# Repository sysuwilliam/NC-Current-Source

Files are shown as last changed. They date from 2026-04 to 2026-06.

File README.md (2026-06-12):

<div align="center">

# 高精度数控恒流源

<p>
  
  
  
  
  
</p>

系统基于 <code>STM32F103 + DAC8562 + OPA197 + 可调 Buck</code>，实现高精度恒流输出、参数显示与保护控制。

</div>

## 项目简介

本项目是 2026 年中山大学电子设计与程序设计校内赛电子设计赛道选题三“高精度数控恒流源”的完整实现。系统以 `STM32F103` 为主控，结合 `DAC8562`、`OPA197`、功率 MOS 管和可调 Buck 电源，完成稳定恒流输出、状态检测、人机交互与保护控制。

项目目标是在不同负载条件下输出高精度、可调节、可显示、可保护的直流恒流。仓库中保留了从方案规划、硬件设计、嵌入式固件、串口屏工程，到测试标定、外壳设计和参考资料的完整内容。

## 主要功能

- 可设定输出电流并稳定恒流输出
- 串口屏显示电流、电压、负载等信息
- 按键与编码器调节参数
- Buck 自动调节输出余量，降低 MOS 发热
- 支持过流、短路、开路保护

## 工作原理

系统采用“硬件恒流内环 + 软件余量外环”的结构：

- `DAC8562 + OPA197 + MOS + Rs` 构成硬件恒流环，直接建立目标电流并负责快速稳流
- `STM32` 采样 `Vsense`、`VOUT+`、`VOUT-`，计算输出电流、负载电压、负载状态和 MOS 压差余量
- `DAC8562` 的另一通道用于控制可调 Buck，动态调节输出电压，为恒流环提供合适工作余量
- 串口屏、按键和编码器负责人机交互，实现参数设置、状态显示和工作控制

控制链路如下：

```text
I_set -> DAC8562 -> OPA197 + MOS + Rs -> I_out
                -> STM32采样与计算 -> Buck调节
```

简要理解就是：

- 模拟电路负责“把电流稳住”
- MCU 负责“把状态算清楚”
- Buck 负责“把供电余量调合适”

## 仓库结构

```text
.
├── README.md                        项目说明
├── 赛题/                            校赛题目原文
├── 规划/                            初期规划、中期报告、收尾总结
├── 代码/
│   ├── 成品/                        最终主固件工程
│   ├── 成品2/                       成品阶段备份工程
│   └── 测试板/                      早期测试板固件工程
├── PCB/
│   └── 测试板/                      PCB 工程文件
├── 串口屏/
│   ├── UI.HMI                       串口屏工程
│   └── 资料/                        串口屏开发手册、例程与协作笔记
├── 测试/
│   ├── 恒流源测试/                  测试规划、测试记录、标定数据与分析图表
│   └── 恒压源测试/                  早期电源与 Buck 联调记录
├── 数据手册/                        DAC、Buck、LDO 等器件手册
├── 外壳/                            3D 外壳模型文件
├── 参考工程/                        参考项目、接口说明、BOM 等资料
└── github协作指南/                  团队协作与 Git 使用说明
```

## 项目状态

项目已完成。仓库当前保存了最终代码、测试数据、串口屏工程、PCB 文件、外壳模型和相关设计资料，可用于展示、复盘和后续迭代参考。

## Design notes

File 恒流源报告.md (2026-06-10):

# 高精度数控恒流源系统设计、控制分析与测试报告

| 项目 | 内容 |
| --- | --- |
| 队伍 | 做的都队 |
| 成员 | 待补充 |
| 比赛 | 2026 年中山大学电子设计与程序设计校内赛电子设计赛道，选题三 |
| 仓库链接 | <https://github.com/sysuwilliam/NC-Current-Source> |
| 提交版本 | `debca7a` |
| 报告状态 | 阶段性报告，最终测试数据和外壳资料待赛前补充 |

## 摘要

本项目设计并实现了一套高精度数控恒流源系统，目标是在可调负载条件下输出稳定、可设定、可显示并具备保护能力的直流恒流。系统采用 `STM32F103 + DAC8562 + OPA197 + MOS + 可调 Buck` 的总体结构，其中 DAC8562 的 CH2 输出电流参考，OPA197、低边 MOS 与 `2Ω` 采样电阻构成快速硬件恒流内环；STM32 采样 `Vsense`、`VOUT+` 和 `VOUT-`，计算输出电流、负载电压、负载电阻和 MOS 压差余量，并通过 DAC8562 的 CH1 慢速调节 Buck 输出，使恒流环保留足够余量且降低 MOS 发热。现有测试表明，电流主链路线性良好，去掉 `0mA` 点后 `I_set -> I_meas` 拟合 `R² = 0.99999900`，`500mA` 点误差约为 `-0.5%`。后续重点是补全 `VOUT±` 校准、负载电阻显示、Buck 自动慢环和三类保护的最终验证。

## 1. 系统设计

### 1.1 总体架构

系统以外部直流输入作为整机能源，分为功率输出、模拟恒流、数字控制和人机交互四个部分。当前仓库中的设计资料和固件均围绕“硬件恒流内环 + 软件 Buck 余量外环”展开。

```text
35V 输入
├── 可调 Buck：输出 VOUT+，给负载和低边 MOS 恒流功率级供电
└── 固定 Buck：输出 5V
    ├── 串口屏
    ├── OPA197 运放
    └── LDO：输出 3.3V
        ├── STM32F103
        ├── DAC8562
        ├── TS5A3159A 模拟开关
        └── ADC / 比较器相关小信号电路
```

控制链路为：

```text
用户设定 Iset
    -> STM32 计算 DAC2 目标电压
    -> DAC8562 CH2 输出电流参考
    -> OPA197 + MOS + Rs 构成硬件恒流环
    -> STM32 采样 Vsense / VOUT+ / VOUT-
    -> 计算 Iactual / Vload / Rload / VMOS
    -> DAC8562 CH1 慢速调节可调 Buck 输出 VOUT+
```

### 1.2 关键器件与作用

| 模块 | 器件/参数 | 作用 |
| --- | --- | --- |
| 主控 | STM32F103 | 采样、计算、按键与串口屏交互、保护状态管理 |
| DAC | DAC8562 | CH2 设定恒流参考，CH1 控制可调 Buck |
| 恒流运放 | OPA197 | 驱动 MOS，使采样电阻电压跟随 DAC2 参考 |
| 功率调整 | 低边 MOS | 线性调整输出电流，承担恒流功率级压差 |
| 电流采样 | `Rs = 2Ω` | 将输出电流转换为采样电压 |
| Buck | LMR16030 相关电路 | 将输入电压降为可调 `VOUT+` 和固定 5V |
| 交互 | 串口屏、按键、编码器 | 设置电流、显示状态、清除报警 |

恒流功率路径为：

```text
VOUT+ -> 负载 -> MOS -> Rs -> GND
```

该路径需要短而粗，MOS、采样电阻和 Buck 电感是主要发热器件。PCB 设计中应把 MOS Drain 大焊盘铺铜并多打过孔，外壳对应 MOS、Rs 和电感区域预留散热孔。

### 1.3 PCB 与可靠性设计

1. `Rs` 使用 Kelvin 采样：功率电流从采样电阻主焊盘流过，运放反馈和 ADC 采样从采样点单独引出，减少铜皮压降对电流精度的影响。
2. `GND` 与 `AGND` 单点连接：连接点放在 Rs 下端或 `AGND_STAR` 附近，避免 Buck、屏幕和数字回流流过模拟参考地。
3. Buck 与模拟区隔离：Buck 的 SW 节点、电感、二极管和输入输出电容远离 DAC、OPA、ADC 分压和 MOS Gate 信号。
4. `VOUT+ / VOUT-` 采样从真实负载端附近引出，用于计算负载电压、负载电阻、MOS 压差和保护状态。
5. 外壳作为加分项处理：正文只放最终装配图、散热孔设计和接口布置说明；完整三维源文件放仓库附录。

## 2. 控制分析

### 2.1 硬件恒流内环

硬件恒流内环由 `DAC2 -> OPA197 -> MOS -> Rs` 构成。DAC2 输出电压作为运放同相端参考，运放调节 MOS Gate，使采样电阻上的电压接近参考电压。理想关系为：

```text
Iout = Vref / Rs
Iout = DAC_ISET / 2Ω
```

该环路不依赖软件高速闭环，主要由运放和 MOS 的模拟响应决定，因此适合承担快速稳流任务。实测中 `DAC2_meas -> I_meas` 拟合为：

```text
I_meas_mA = 0.497253 * DAC2_mea_mV - 0.029041
R² = 0.99999994
RMSE = 0.041 mA
```

该结果说明只要 DAC2 实际输出电压确定，模拟恒流内环线性非常好。当前主误差更多来自 DAC 命令值、ADC 显示换算和 Buck 余量设置。

### 2.2 Buck 慢速余量外环

Buck 外环的目的不是直接高速调电流，而是给恒流内环提供合适压差，避免 MOS 压差过小导致恒流失败，也避免压差过大造成 MOS 发热。

核心计算量为：

```text
Vload = VOUT+ - VOUT-
Rload = Vload / Iout
VMOS = VOUT- - Vsense
VOUTP_target = I_set * Rload_est + I_set * Rsense + VMOS_margin
```

根据测试和分析，初版可取：

```text
Rsense = 2Ω
VMOS_margin = 1.2V ~ 2.0V
```

DAC1 与 Buck 输出的反算采用当前测试总结中的关系：

```text
VOUT+ = 10.012879 * DAC1_actual_V - 1.797554
DAC1_cmd_V = (VOUTP_target + 1.797554) / 10.012879
```

仓库早期测试记录中也出现过 `VOUT+ = 31.242 - 10.011 * V_DAC1` 的负斜率公式，二者对应的控制点或电路阶段可能不同。最终报告应以最后一晚实测的 `DAC1_cmd -> VOUT+` 标定为准，明确写出当时测量点、接法和公式符号。

同时必须加入限幅，避免 Buck 输出超过硬件和输入电源能力。当前 `VOUT± 校准 -> Rload 校准 -> Buck 自动调 DAC1` 仍属于最终待验证项，建议最后一晚按以下顺序补齐：

1. 用万用表标定 `VOUT+`、`VOUT-` 显示值。
2. 用校准后的 `Vload / Iout` 计算 `Rload_est`。
3. 固定 50mA、250mA、500mA 三档，改变负载，观察自动 Buck 是否能让 `VMOS` 保持在目标范围。
4. 记录 `DAC1_cmd`、`VOUT+`、`VOUT-`、`VMOS` 和 MOS 温升趋势。

### 2.3 显示、状态与交互层

STM32 负责把 ADC 采样值换算为显示量，并通过串口屏显示工作模式、设定电流、实际电流、负载电阻、DAC 输出和保护状态。按键与编码器负责：

1. 设定目标电流。
2. 开启或停止输出。
3. 在过流或开路故障后清除报警。

显示值不应直接作为保护判断的唯一依据。报告中区分：

| 名称 | 用途 |
| --- | --- |
| `I_serial` | ADC 原始换算电流 |
| `I_disp` | 校准和滤波后的用户显示电流 |
| `I_fast` | 短平均、低延迟的保护判断电流 |
| `Rload_disp` | 滤波和死区处理后的负载电阻显示值 |

## 3. 保护逻辑

保护逻辑分为过流、短路和开路三类。报告应如实记录每一类保护的状态：已实现、已验证、设计完成待验证。当前建议最终报告采用下表更新。

| 保护类型 | 判据 | 动作 | 恢复方式 | 当前状态 |
| --- | --- | --- | --- | --- |
| 过流保护 | `Vsense > 1.10V` 或 `I_fast > 550mA`，持续超过去抖时间 | `SW_IN=0`、`DAC2=0`、`BUCK_EN=0`，报警锁存 | 用户按 `ALARM CLEAR` 后回到待机 | 设计完成，待最终验证 |
| 短路保护 | `Iset` 非零、`Iactual` 接近设定值且 `Vload < 0.2V ~ 0.5V` 持续 50ms-200ms | 进入短路限流，降低 Buck 输出，显示“短路限流” | 短路解除后自动回到正常 Buck 调节 | 设计完成，待最终验证 |
| 开路保护 | `Iset > 20mA`、`Iactual < 5mA`，Buck 已升高仍无电流，持续约 200ms | `SW_IN=0`、`DAC2=0`、`BUCK_EN=0`，报警锁存 | 接好负载后人工清除报警 | 设计完成，待最终验证 |

过流和开路应锁存，防止故障解除瞬间自动重启造成反复冲击；短路保护以“限流不损坏”为目标，可以自动恢复。保护判断使用 `I_fast` 或短时间平均值，避免显示滤波过慢造成保护滞后。

## 4. 测试数据与结果

### 4.1 测试数据来源

当前阶段的量化分析主要来自：

1. `测试/恒流源测试/测试记录/测试数据02.xlsx`
2. `测试/恒流源测试/测试分析/测试数据02分析.md`
3. `测试/恒流源测试/figures/` 中生成的拟合、误差、稳定性和余量图

原始表格和完整图像不放入正文全文展开，作为仓库附录提供。

### 4.2 电流设定精度

综合校准表中，设定电流与电流表实测电流拟合为：

```text
I_meas_mA = 0.994172 * I_set_mA + 0.259333
R² = 0.99999586
RMSE = 0.340 mA
最大拟合残差 = 1.071 mA
```

去掉 `0mA` 点后：

```text
I_meas_mA = 0.994738 * I_set_mA + 0.067706
R² = 0.99999900
RMSE = 0.165 mA
最大拟合残差 = 0.345 mA
```

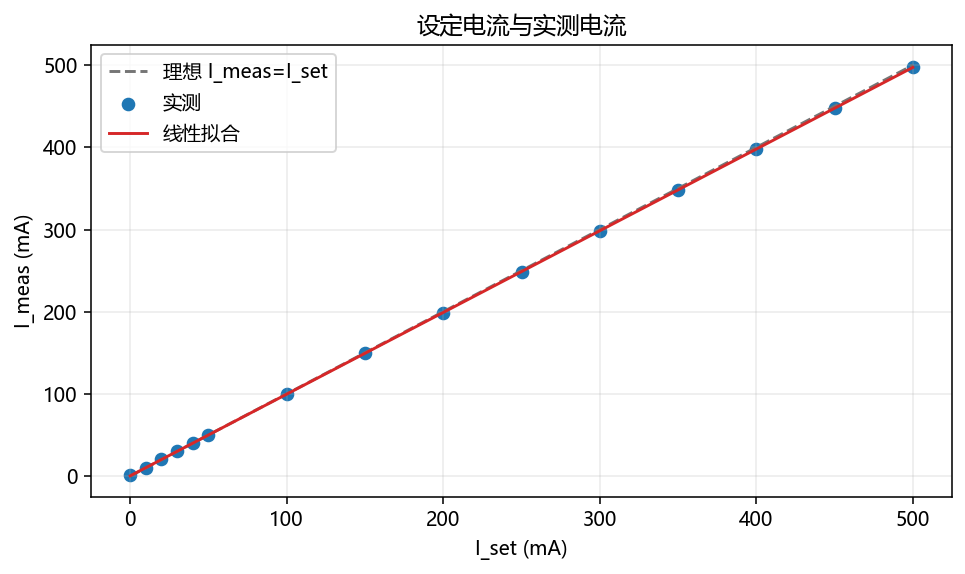
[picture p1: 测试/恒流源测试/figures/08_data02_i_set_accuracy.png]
设定电流与实测电流拟合


最大绝对误差出现在 `500mA` 点：

```text
I_set = 500mA
I_meas = 497.5mA
误差 = -2.5mA
相对误差 = -0.5%
```

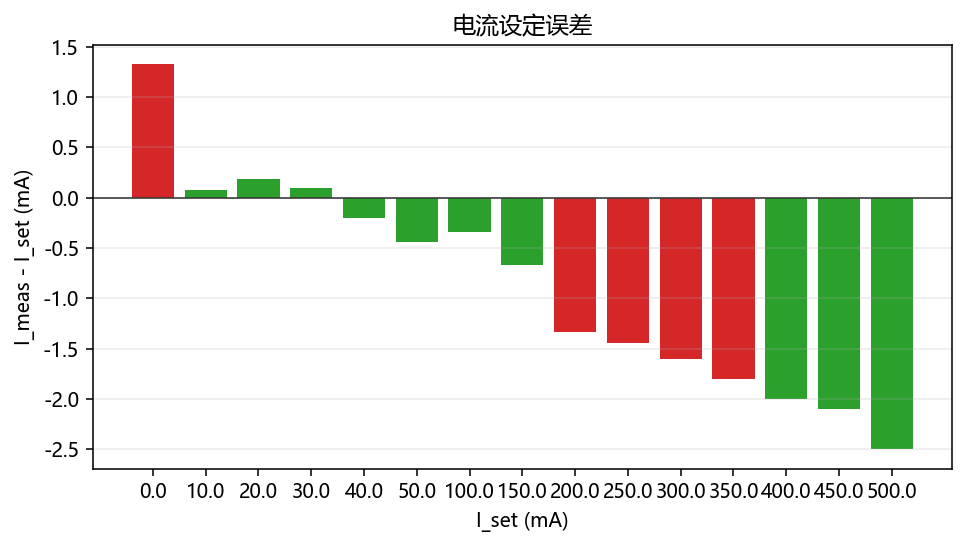
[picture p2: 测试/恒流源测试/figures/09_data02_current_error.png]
电流设定误差


### 4.3 DAC2 校准结果

DAC2 命令值到输出电流的拟合为：

```text
I_meas_mA = 0.498188 * DAC2_cmd_mV + 1.368386
R² = 0.99999534
RMSE = 0.361 mA
```

因此固件中采用如下前馈公式：

```text
DAC2_cmd_mV = (I_set_mA - 1.368386) / 0.498188
```

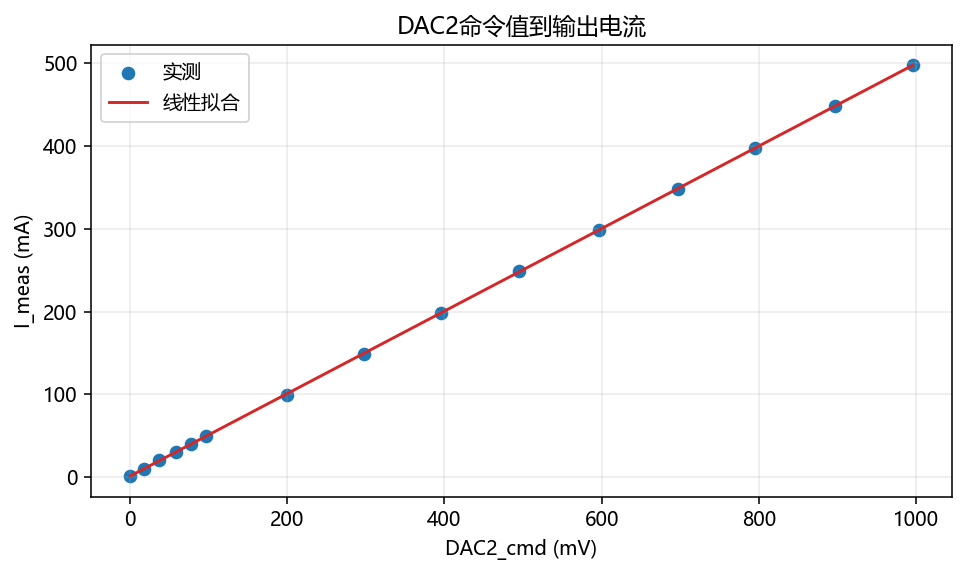
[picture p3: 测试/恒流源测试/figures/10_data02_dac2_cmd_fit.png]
DAC2 命令值到输出电流


DAC2 实测电压到输出电流的拟合更接近理论：

```text
I_meas_mA = 0.497253 * DAC2_mea_mV - 0.029041
R² = 0.99999994
RMSE = 0.041 mA
```

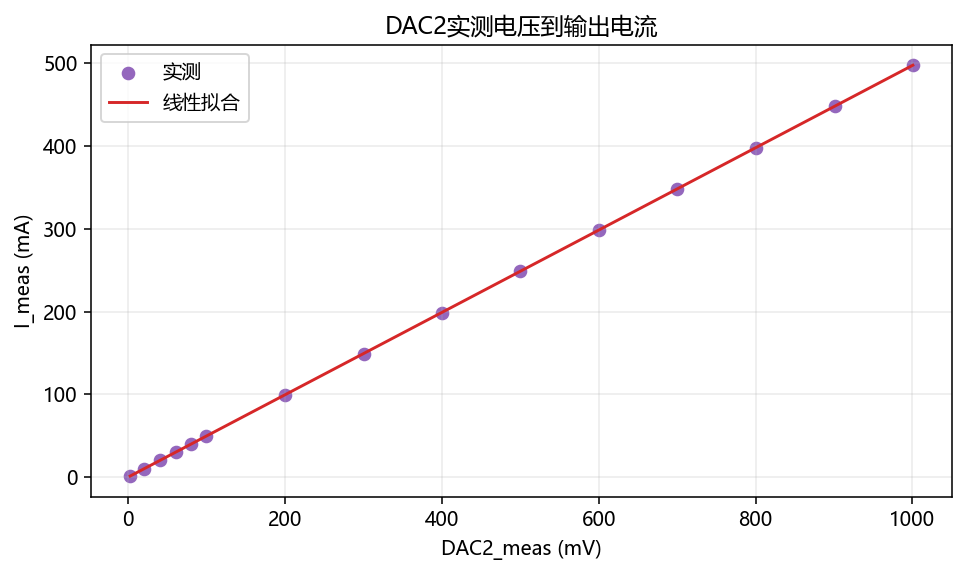
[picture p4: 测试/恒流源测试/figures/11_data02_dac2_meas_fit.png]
DAC2 实测电压到输出电流


### 4.4 VOUT 显示校准与 MOS 余量

当前 VOUT 显示链路的校准公式为：

```text
VOUTP_cal = 0.985864 * VOUTP_serial + 0.001825
VOUTN_cal = 0.998639 * VOUTN_serial - 0.026753
```

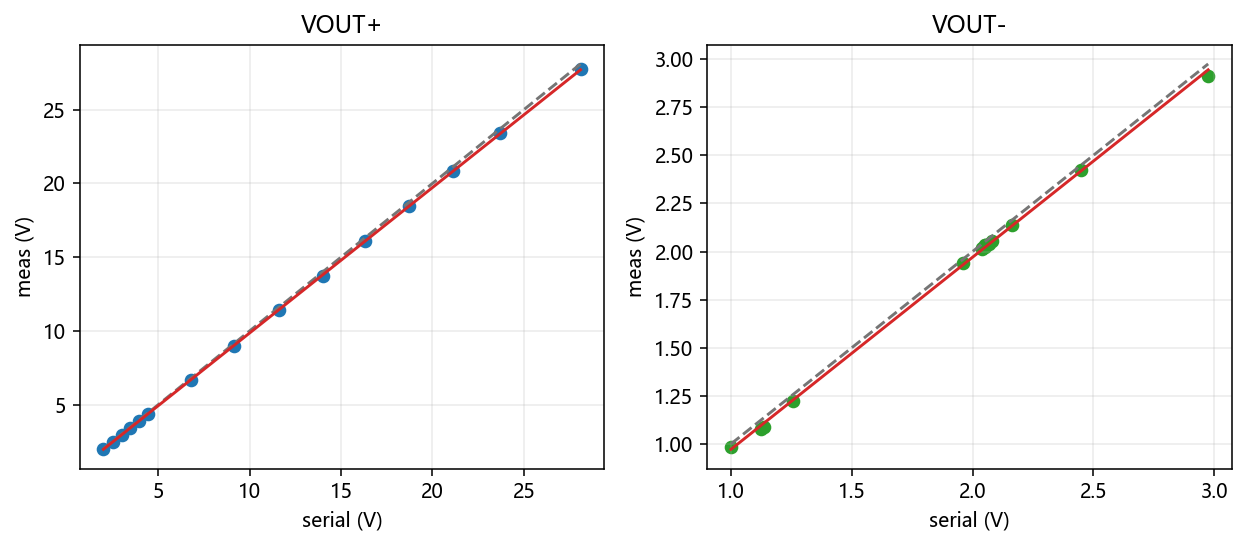
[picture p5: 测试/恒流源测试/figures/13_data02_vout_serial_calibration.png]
VOUT 串口显示校准


以主表估算的 MOS 压差余量如下：

| I_set(mA) | I_meas(mA) | VOUTN_meas(V) | Vsense_serial(mV) | VMOS估算(V) |
| --- | ---: | ---: | ---: | ---: |
| 250 | 248.56 | 2.426 | 505 | 1.921 |
| 300 | 298.40 | 1.222 | 606 | 0.616 |
| 350 | 348.20 | 1.076 | 705 | 0.371 |
| 400 | 398.00 | 0.985 | 807 | 0.178 |
| 450 | 447.90 | 1.087 | 909 | 0.178 |
| 500 | 497.50 | 2.913 | 1011 | 1.902 |

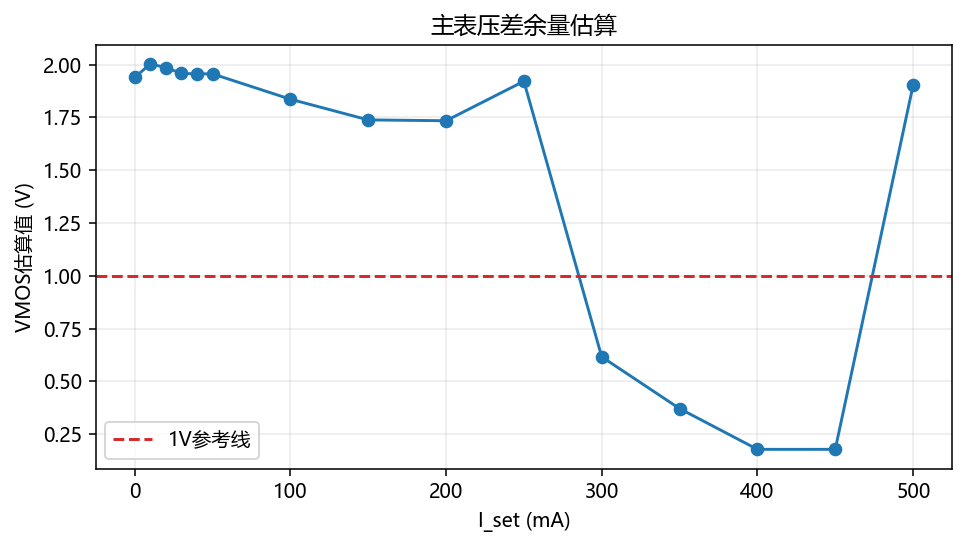
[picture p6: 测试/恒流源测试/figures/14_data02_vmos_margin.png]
MOS 压差余量估算


该结果说明 `300mA ~ 450mA` 工况下 Buck 输出余量偏低，恒流环接近压差不足。最终报告应在自动 Buck 慢环实现后补充新表，证明 `VMOS` 能稳定保持在目标范围。

### 4.5 连续采样稳定性

连续串口数据在 50mA、250mA、500mA 三档下的统计如下：

| I_set(mA) | 样本数 | I_actual均值(mA) | I_actual标准差(mA) | Vsense均值(mV) | Vsense标准差(mV) | RLOAD均值(Ω) | RLOAD标准差(Ω) | VMOS均值(mV) |
| --- | ---: | ---: | ---: | ---: | ---: | ---: | ---: | ---: |
| 50 | 29 | 51.023 | 0.447 | 97.793 | 0.412 | 50.161 | 0.537 | 1920.4 |
| 250 | 30 | 252.685 | 0.377 | 501.900 | 0.305 | 49.759 | 0.097 | 2346.5 |
| 500 | 31 | 506.804 | 0.301 | 1009.742 | 0.514 | 49.631 | 0.039 | 1924.4 |

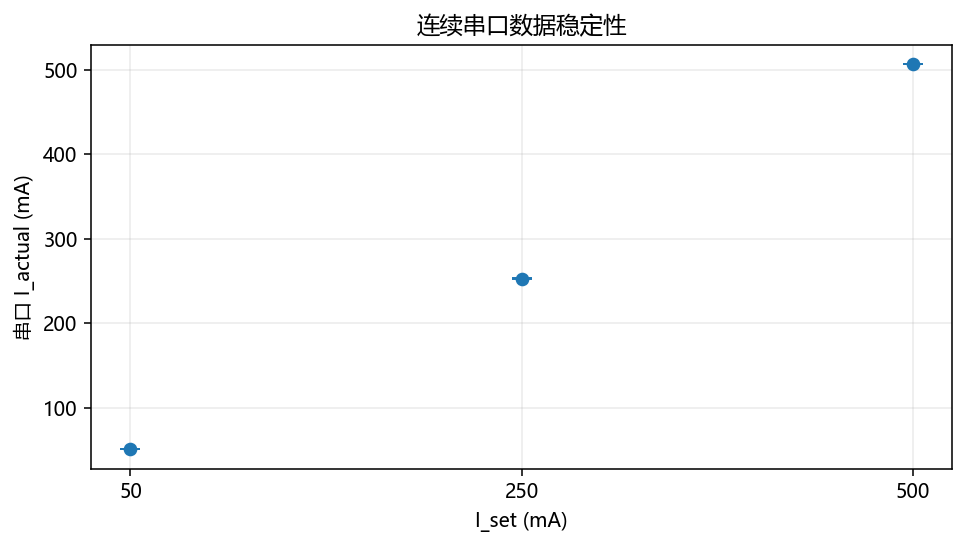
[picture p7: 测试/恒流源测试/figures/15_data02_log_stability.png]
连续串口数据稳定性


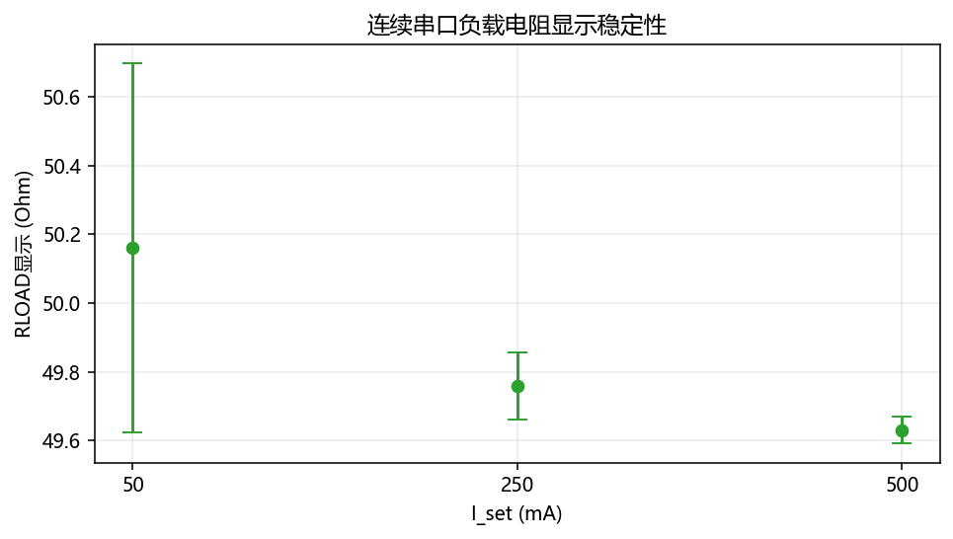
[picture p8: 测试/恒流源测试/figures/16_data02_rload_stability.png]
连续串口负载电阻显示稳定性


结论是电流显示重复性较好，三档标准差均小于 `0.5mA`；负载电阻显示在低电流档波动较大，适合增加低电流显示门限、强滤波和显示死区。

### 4.6 纹波测试

当前仅记录了 `50mA` 档的一次示波器读数：

```text
Vpp ≈ 5mV
Rsense = 2Ω
I_ripple_pp ≈ 5mV / 2Ω = 2.5mApp
```

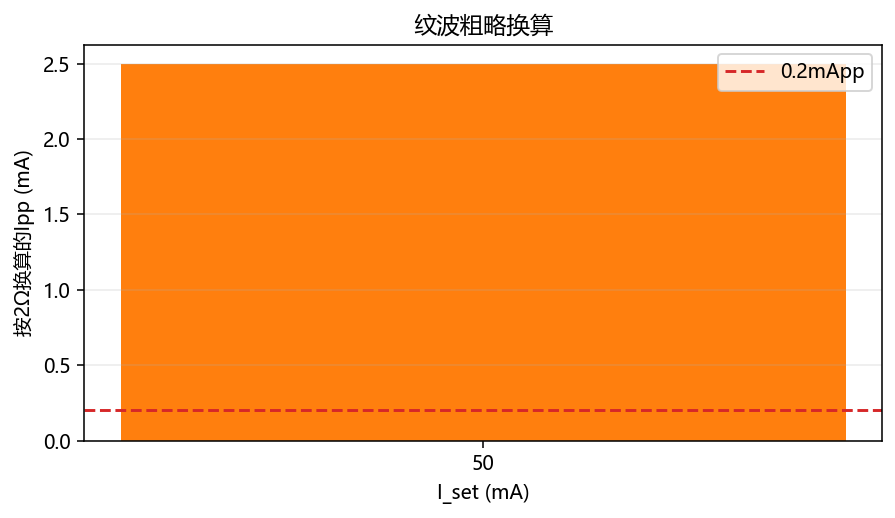
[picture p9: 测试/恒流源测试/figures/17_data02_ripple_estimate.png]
纹波粗略换算


该数据不能直接作为最终纹波结论，因为普通探头长地线、Buck 高频尖峰、示波器带宽和噪声底都会影响 mV 级读数。最终应按短地弹簧、AC 耦合、20MHz 限带、先测噪声底的方法重测。

## 5. 误差分析

### 5.1 DAC2 命令值与实际输出误差

`DAC2_meas -> I_meas` 的线性非常好，而 `DAC2_cmd -> I_meas` 的 RMSE 明显更大，说明模拟恒流内环本身不是主要误差来源，DAC 命令值到实际电压的偏差和软件换算更关键。现已采用前馈校准：

```text
DAC2_cmd_mV = (I_set_mA - 1.368386) / 0.498188
```

低电流段仍受零点偏置和仪表分辨率影响，`0mA`、`5mA`、`10mA`、`20mA` 可单独补测。

### 5.2 采样电阻误差与温漂

理想公式假设 `Rsense = 2Ω`。实际中采样电阻的初始精度、温漂、焊盘热分布和功率发热都会改变等效阻值。建议使用 `0.1%`、低温漂、足够功率裕量的采样电阻，并在最终报告中记录测试时电流档位、持续时间和发热情况。

### 5.3 ADC 分压与参考误差

`VOUT+`、`VOUT-` 经分压进入 ADC，误差来源包括分压电阻容差、ADC 参考电压、布线噪声和滤波延迟。当前已得到校准式：

```text
VOUTP_cal = 0.985864 * VOUTP_serial + 0.001825
VOUTN_cal = 0.998639 * VOUTN_serial - 0.026753
```

后续 `Rload` 和 `VMOS` 都应使用校准后的 `VOUTP_cal`、`VOUTN_cal` 计算，否则 Buck 慢环会被错误余量带偏。

### 5.4 Buck 余量不足

主表中 `300mA ~ 450mA` 的 `VMOS` 估算值只有 `0.178V ~ 0.616V`，说明 Buck 目标电压偏低，MOS 压差不足，恒流环可能接近饱和。改进方向是用校准后的负载估计值计算：

```text
VOUTP_target = I_set * Rload_est + I_set * Rsense + VMOS_margin
```

并让 DAC1 慢速调节 Buck，使 `VMOS` 保持在目标范围。

### 5.5 纹波测量误差

若目标电流纹波为 `0.2mA`，在 `2Ω` 采样电阻上的等效电压纹波只有：

```text
0.2mA * 2Ω = 0.4mVpp
```

这已经接近普通示波器探头和接地方法的噪声底。最终纹波测试必须先测噪声底，再使用短地、限带和合适时基记录，不应只用一次 `5mVpp` 普通探头读数下结论。

## 6. 待补充的最终验证项目

| 项目 | 需要补充的内容 | 建议验收记录 |
| --- | --- | --- |
| 成员信息 | 队员姓名、学号、分工 | 首页表格 |
| `VOUT±` 校准 | 新校准后的公式和误差 | `VOUTP/VOUTN` 实测对比表 |
| `Rload` 显示 | 不同电流和负载下的显示误差 | `Rload_nominal`、`Rload_disp`、误差 |
| Buck 自动慢环 | 负载变化时 `VMOS` 是否维持目标范围 | `DAC1_cmd`、`VOUT+`、`VMOS` 曲线或表格 |
| 三大保护 | 过流、短路、开路触发和恢复过程 | 判据、动作、恢复状态截图或日志 |
| 纹波 | 规范测量后的最终纹波 | 噪声底、带宽、时基、Vpp、换算电流 |
| 外壳 | 装配图、散热孔、接口位置 | 正文一张图，源文件放仓库 |

## 7. 资料索引

| 资料 | 仓库路径 |
| --- | --- |
| 总体说明 | `README.md` |
| 系统方案与 PCB 原则 | `方案说明.md` |
| 固件主工程 | `代码/成品/`、`代码/成品2/` |
| PCB 工程 | `PCB/测试板/` |
| 恒流测试记录 | `测试/恒流源测试/测试记录/` |
| 恒流测试分析 | `测试/恒流源测试/测试分析/` |
| 测试图表 | `测试/恒流源测试/figures/` |
| 串口屏资料 | `串口屏/` |
| 数据手册 | `数据手册/` |
| 参考工程 | `参考工程/` |

## 参考资料

1. `README.md`：项目简介、系统架构、关键参数和仓库导航。
2. `方案说明.md`：电源树、恒流控制逻辑、保护逻辑、PCB 布局和调试流程。
3. `测试/恒流源测试/测试分析/测试数据02分析.md`：电流精度、DAC 校准、VOUT 校准、稳定性和纹波分析。
4. `测试/恒流源测试/测试分析/PID调控校准公式总结.md`：校准公式、Buck 目标电压和可选 PI 调控方案。
5. `测试/恒流源测试/测试记录/测试数据02.xlsx`：原始测试数据。

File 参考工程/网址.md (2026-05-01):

1. [200W超低纹波可调数字电源-LRP3212（Low Ripple Power 32V 12A）](https://oshwhub.com/eda_ydaolrocl/200w-ultra-low-ripple-digital-bu)
2. [OPA547压控恒流源](https://oshwhub.com/2259123zz/opa547-ya-kong-heng-liu-yuan)
3. [支持正负电流输出的数控恒流源](https://www.jlc-ycs.com/platform/detail/8251253cc31848cc811d72bcd725bc76?type=1)

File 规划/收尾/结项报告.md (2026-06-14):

# 高精度数控恒流源系统设计、控制分析与测试报告

| 项目 | 内容 |
| --- | --- |
| 参赛队伍 | 做的都队 |
| 参赛成员 | 邓嘉杰、刘欣雅、卢城霖 |
| 选题 | 选题三：高精度数控恒流源 |
| 项目仓库 | [https://github.com/sysuwilliam/NC-Current-Source](https://github.com/sysuwilliam/NC-Current-Source) |

---

## 摘要

本项目设计并实现了一套基于单片机控制的高精度数控恒流源。系统面向 `0～500 mA` 直流恒流输出需求，支持 `1 mA` 步进设定、输出电流和负载参数实时显示，并具有过流、短路和开路保护功能。为兼顾恒流精度、输出范围和功率器件温升，系统采用“**可调 Buck 预稳压 + 运放/MOS 线性恒流 + MCU 数字标定与控制**”的混合控制结构。

硬件以 STM32F103C8T6 为控制核心，MCP4822 双通道 DAC 分别产生恒流参考电压和 Buck 调节电压；OPA197、功率 MOS 管及 `2 Ω` 采样电阻构成快速模拟恒流内环；LMR16030 可调 Buck 根据设定电流和负载估计值调节 `VOUT+`，为 MOS 管保留约 `1.5 V` 的工作压差，从而在保证恒流能力的同时降低线性功率器件发热。STM32 同步采集 `VOUT+`、`VOUT-` 和 `V_SENSE`，完成电流、电压、负载阻值和 MOS 压差的计算，并通过均值滤波、卡尔曼滤波、线性校准及多点标定后的残差补偿提高显示精度。

测试结果表明，DAC2 实测电压与输出电流具有很高的线性度，关系为 `I_meas = 0.497253×DAC2_meas−0.029041`，决定系数达到 `R²=0.99999994`；设定电流与实测电流去除零点后决定系数为 `R²=0.99999900`。历史测试中 500 mA 点误差为 `−2.5 mA`，相对误差为 `−0.50%`；连续采样结果显示，50 mA、250 mA 和 500 mA 三档的显示标准差均小于 `0.5 mA`。最终系统完成 0～500 mA 数字设定、负载阻值显示、Buck 自动调压以及过流、短路和开路保护。串口屏除显示数值与状态外，还可实时绘制目标电流和实际电流双通道波形；项目同时完成了面向实物装配、散热和操作的三维外壳结构设计。

**关键词：** 数控恒流源；模拟负反馈；可调 Buck；数字校准；PI 控制；负载检测；STM32

---

## 1 项目背景与设计任务

### 1.1 项目背景

恒流源能够在负载阻值发生变化时维持输出电流基本不变，广泛应用于器件测试、LED 驱动、传感器激励、电化学测量和实验室电源等场景。传统模拟恒流源具有响应快、结构直观的优点，但设定方式单一、参数不易显示，且在宽负载范围下容易因功率管压差过大而产生明显发热；纯开关恒流方案效率较高，但开关纹波、闭环补偿和低电流精度控制难度较大。

本项目将线性恒流与开关预稳压相结合：快速模拟环负责稳定电流，低速数字环负责设定、校准、显示、保护和供电余量管理，使系统兼具高精度、宽负载范围和较低功耗。

### 1.2 设计任务

赛题要求设计并制作一台基于单片机控制的高精度数控恒流源，主要技术要求如下：

1. 输出电流范围为 `0～500 mA`，设定步进为 `1 mA`，精度要求为 `±0.5%`；
2. 当输出电流超过 `550 mA` 时能够自动切断，并显示设定电流和实际输出电流；
3. 在恒流模式下，负载电阻在 `0～50 Ω` 范围变化时，输出电流变化绝对值小于设定值的 `1%`；
4. 输出端短路时自动将电流限制在设定值，不损坏设备；
5. 负载开路时自动检测并报警；
6. 发挥部分要求输出纹波电流不大于 `0.2 mA`，并能够测量和显示负载电阻值。

### 1.3 设计指标与完成情况

| 指标 | 赛题要求 | 系统设计与测试结果 |
| --- | --- | --- |
| 输出电流范围 | 0～500 mA | 实现 0～500 mA 数字设定，软件安全上限保留至 600 mA，正常使用限制在 500 mA |
| 设定步进 | 1 mA | 实现 1 mA、10 mA、100 mA 可切换步进，默认可使用 1 mA 精调 |
| 电流精度 | ±0.5% | 主链路线性良好；历史保守数据最大误差约为 500 mA 点 −0.50%，低电流区通过多点标定后的残差补偿进一步修正 |
| 负载范围 | 0～50 Ω | 模拟恒流环配合 Buck 自动调压，覆盖短路至约 50 Ω 负载 |
| 负载变化 | 电流变化绝对值小于设定值 1% | 最终功能验证中负载变化满足设计要求 |
| 过流保护 | >550 mA 自动切断 | 设置 550 mA 阈值，触发后关闭 Buck 并锁存报警 |
| 短路保护 | 限制在设定值 | 模拟恒流内环天然限流，Buck 前馈在低阻工况下降低功耗 |
| 开路保护 | 自动检测并报警 | 根据设定电流、实际电流和输出状态检测并报警 |
| 负载阻值显示 | 可测量并显示 | 由校准后的负载压降与输出电流计算，低电流区设置显示门限和强滤波 |
| 输出纹波 | ≤0.2 mA | 已建立采样电阻纹波测试方法；普通探头粗测受噪声底限制，详见 8.7 节 |

---

## 2 系统总体方案

### 2.1 总体设计思路

系统采用两块 PCB 分离设计：功率/模拟板负责输入保护、电源变换、恒流功率级和模拟采样；控制板负责 STM32、编码器、按键、串口通信与人机交互。板间通过排线传输 SPI、Buck 使能和 ADC 信号，能够降低功率开关噪声对数字控制和弱信号测量的影响，也便于分模块调试。

总体能量与控制流程如下：

```mermaid
flowchart LR
    VIN[直流输入 30 V] --> PROT[保险丝/TVS/共模滤波]
    PROT --> BUCK1[可调 Buck]
    BUCK1 --> VP[VOUT+]
    VP --> LOAD[外部负载 0~50 Ω]
    LOAD --> VN[VOUT-]
    VN --> MOS[线性 MOS 恒流级]
    MOS --> RS[Rs=2 Ω]
    RS --> GND[GND]

    PROT --> BUCK5[固定 5 V Buck]
    BUCK5 --> OPAMP[OPA197]
    BUCK5 --> LDO[3.3 V LDO]
    LDO --> MCU[STM32F103]
    LDO --> DAC[MCP4822]

    MCU -->|SPI DAC2| DAC
    DAC -->|电流参考| OPAMP
    OPAMP -->|Gate 驱动| MOS
    MCU -->|SPI DAC1| DAC
    DAC -->|Buck 控制| BUCK1

    VP --> ADC[ADC 采样]
    VN --> ADC
    RS --> ADC
    ADC --> MCU
    MCU --> HMI[串口屏/编码器/按键]
```

### 2.2 方案比较与选择

#### 2.2.1 纯线性恒流方案

纯线性方案可由运放、MOS 管和采样电阻构成，结构简单、输出纹波低、恒流响应快，但 MOS 管承受的功耗为：

$$
P_{MOS}=V_{MOS}I_{out}
$$

当输入电压高、负载电压低或发生短路时，MOS 管压差明显增大，容易产生较高温升，不利于长期稳定运行。

#### 2.2.2 纯 Buck 恒流方案

纯开关恒流方案效率高，但要在 0～500 mA 全范围内同时满足低纹波、高精度和快速负载响应，需要复杂的电流模式控制和环路补偿，且开关节点噪声会增加 ADC 和显示校准难度。

#### 2.2.3 本项目混合方案

本项目由 Buck 粗调供电电压、线性环精调输出电流：

- OPA197 与 MOS 构成的模拟恒流环响应最快，直接承担负载扰动；
- DAC2 和数字 PI 负责设定与静态精度修正；
- DAC1 和 Buck 慢环只管理 MOS 压差，不参与高速电流调节。

这种分层控制使每个环路只处理适合自身带宽的问题，既避免 Buck 高频调节干扰电流，又显著降低 MOS 管长期功耗。

### 2.3 系统模块组成

| 模块 | 核心器件或参数 | 主要作用 |
| --- | --- | --- |
| 主控模块 | STM32F103C8T6 | 数据采集、控制计算、状态机和人机交互 |
| 双通道 DAC | MCP4822-E/SN | DAC1 控制 Buck，DAC2 产生恒流参考 |
| 模拟恒流环 | OPA197 + SUD50N06-09L-TP + 2 Ω | 快速建立并稳定输出电流 |
| 可调 Buck  | LMR16030 | 输出 VOUT+，动态管理 MOS 压差和功耗  |
| 固定电源 | LMR16030 + SPX29302 | 产生 5 V 和 3.3 V 电源 |
| ADC 采样 | STM32 内部 ADC + 精密分压 | 采集 VOUT+、VOUT−、Vsense |
| 人机交互 | 串口屏、EC11 编码器、按键 | 参数设置、数据显示和告警提示 |
| 输入保护 | 自恢复保险丝、TVS、共模电感 | 过流、浪涌和高频干扰抑制 |

---

## 3 硬件系统设计与工作原理

### 3.1 输入保护与电源树

系统测试时通常使用 24～30 V 直流输入，输入端依次设置自恢复保险丝、TVS 管、共模电感和大容量滤波电容。电源分为两路：

1. 一路经可调 LMR16030 输出 `VOUT+`，供负载和线性恒流功率级使用；
2. 另一路经固定 Buck 输出 5 V，供 OPA197 和串口屏使用，再通过 SPX29302 LDO 产生 3.3 V，供 STM32、MCP4822 和小信号电路使用。

固定 5 V 和 3.3 V 电源与功率输出分开，避免负载变化直接影响 MCU 供电。调试过程中发现，实验电源限流设置过低时会进入恒流模式，造成 5 V、3.3 V 下跌及 MCU 复位，因此整机调试时将输入电源限流设置为不低于 0.5 A，并在正式工作前检查电源是否保持 CV 状态。

### 3.2 双通道 DAC 电路

MCP4822 是双通道 12 位电压输出 DAC，通过 SPI 与 STM32 通信。两路输出的职责严格分开：

- **DAC1：** 经 OPA197 和反馈网络改变可调 Buck 的反馈状态，用于调节 `VOUT+`；
- **DAC2：** 产生恒流参考电压，直接送入恒流运放同相端。

DAC2 与运放输入之间串联 `R1=330 Ω`。该电阻不是为了形成明显分压，而是限制异常状态下的瞬态电流，并与输入端电容共同隔离 DAC 输出和运放输入的高频扰动。输入节点通过 `R6=49.9 kΩ` 下拉至 AGND，使 MCU 未初始化、DAC 关闭或连接异常时仍具有明确的 0 V 默认状态，避免高阻节点悬浮；`C5=100 nF` 对参考电压进行低通滤波，减小数字通信和电源噪声耦合到恒流设定端。

参考节点的直流关系为：

$$
V_{ref}=V_{DAC2}\frac{49.9k}{49.9k+330}
$$

比例约为 0.99343，因此保护电阻对量程影响很小，可在标定中统一补偿。

### 3.3 模拟恒流内环

恒流功率路径为：

```text
VOUT+ → 负载 → VOUT− → Q2 Drain → Q2 Source
       → V_SENSE_RAW → Rs → GND
```

OPA197 同相端接收 DAC2 参考，反相端经 `R5=47 Ω` 采集 `V_SENSE_RAW`。运放调节 Q2 Gate 电压，使采样电阻两端电压逼近参考电压：

$$
V_{sense}\approx V_{ref},\qquad I_{out}=\frac{V_{sense}}{R_s}
$$

本系统实际使用开步睿思 `PZWR0005B2R00A9` 精密绕线电阻，参数为 `2 Ω、±0.1%、5 W`。因此理想关系约为：

$$
I_{out}(mA)\approx0.496715\,V_{DAC2}(mV)
$$

实测斜率为 `0.497253 mA/mV`，与理论值接近，说明模拟恒流链具有良好的线性基础。

运放输出与 MOS Gate 之间串联 `R4=47 Ω`，用于限制 MOS 栅极瞬态充放电电流，并隔离栅极电容对运放输出稳定性的影响；反相输入前的 `R5=47 Ω` 可限制异常输入电流，并与补偿网络共同改善高频稳定性。运放输出与反相端之间预留 `C2=330 pF` 补偿电容，用于抑制由 MOS 栅极电容、布线寄生参数和负载变化引起的高频振荡。该电容取值需要在稳定性和响应速度之间折中，因此原理图中保留了根据阶跃波形调整或拆除的余地。

### 3.4 MOS 管工作区与功耗管理

Q2 采用 SUD50N06-09L-TP 功率 MOS 管，在本系统中工作于线性区。MOS 管压差定义为：

$$
V_{MOS}=V_{OUT-}-V_{sense}
$$

MOS 功耗为：

$$
P_{MOS}=V_{MOS}I_{out}
$$

如果 Buck 输出过低，`V_MOS` 不足，运放即使将 Gate 电压提高也无法继续增加电流，恒流环进入压差饱和；如果 Buck 输出过高，则 MOS 功耗和温升增加。综合恒流稳定性和发热，系统将目标 MOS 压差设置为约 1.5 V，并允许其在合理范围内缓慢变化。

例如在 500 mA 工作时，若 `V_MOS=1.5 V`，MOS 理论功耗约为：

$$
P_{MOS}=1.5\times0.5=0.75W
$$

相比直接由 30 V 线性降压，该功耗明显降低。PCB 对 MOS 大焊盘铺铜并设置导热过孔，实物安装散热片，外壳在 MOS、电感和采样电阻附近预留通风区域。

### 3.5 可调 Buck 与 DAC1 控制

可调 Buck 使用 LMR16030。DAC1 经运放和反馈网络改变 FB 节点等效电压，从而调节 `VOUT+`。最终阶段对控制链进行了实测标定，得到：

$$
V_{OUT+}=10.012879\,V_{DAC1}-1.797554
$$

因此目标输出电压对应的 DAC1 命令为：

$$
V_{DAC1}=\frac{V_{OUT+,target}+1.797554}{10.012879}
$$

DAC1 输出在软件中限制于硬件有效范围，目标 `VOUT+` 同时受输入电压和 Buck 最大占空比限制。当输入为 30 V 时，系统在 500 mA、约 50 Ω 负载工况下可将 `VOUT+` 提高至约 27.7 V，并为恒流环保留接近 2 V 的 MOS 压差。

### 3.6 ADC 采样电路

系统采集三个模拟量：

- `ADC_VOUT+`：VOUT+ 经 `330 kΩ/33 kΩ` 精密电阻分压；
- `ADC_VOUT−`：VOUT− 经相同比例分压；
- `V_SENSE`：采样电阻上端电压经独立 RC 滤波后进入 ADC。

VOUT 分压比例约为 11，使最高约 30 V 的功率输出落入 3.3 V ADC 的安全量程。分压节点后串联 `1 kΩ`，并配置 `22 nF` 电容：串联电阻限制 ADC 采样瞬态电流并隔离输入保护，电容滤除 Buck 开关尖峰。`V_SENSE` 通道使用 `1 kΩ+10 nF` 的较轻滤波，兼顾保护、抗噪和电流变化响应。

理想换算为：

$$
V_{OUT}=\frac{ADC_{raw}}{4095}\times3.3\times11,
\qquad I_{raw}=\frac{V_{sense}}{2Ω}
$$

实际系统在理想换算后再进行通道标定，用于补偿 ADC 参考电压、分压器实际比例、地参考差异和装配误差。

### 3.7 数模地、跨板连接与 PCB 布局

功率/模拟板设置 GND、AGND 和 ADC_REF_GND：

- GND 承担 Buck、MOS、负载和采样电阻的功率回流；
- AGND 作为 DAC、运放等弱信号电路的参考；
- GND 与 AGND 通过 0 Ω 电阻单点连接；
- ADC_REF_GND 从采样参考区域单独引至控制板，避免屏幕、LED、按键和数字通信电流流过模拟测量参考。

PCB 将 Buck 的 SW 节点、电感和肖特基二极管集中在功率区，将 DAC、运放、ADC 分压和反馈线布置在模拟区。MOS Gate、运放输入及 ADC 信号远离电感和高速开关节点；采样电阻的反馈线从器件端点单独引出，减小大电流铜皮压降对测量结果的影响。

两块板联调时还发现，实验室临时取用、长度和接触质量不一致的散装杜邦线会明显影响跨板 ADC 信号稳定性。其原因包括接触电阻变化、信号回路面积过大、参考地与信号线分离以及对 Buck 开关噪声的拾取。最终连接应使用长度一致、固定压接的排线或线束，并使每个敏感模拟信号尽量与 ADC_REF_GND 相邻；调试线束固定后不再随意更换。该经验同时说明，精密测量系统的“连接器和线束”属于模拟链路的一部分，而不是可以忽略的机械附件。

## 4 控制系统与软件设计

最终固件采用采样就绪标志协调控制更新，电流 PI 与 Buck 前馈分别承担不同任务，串口屏数据通过发送队列输出，避免长时间阻塞主控制流程。

### 4.1 控制层级

系统包含三个不同时间尺度的环节：

1. **模拟恒流内环：** 由 OPA197、MOS 和采样电阻组成，速度最快，直接抑制负载扰动；
2. **数字电流修正：** STM32 根据校准后的电流反馈，以增量式 PI 微调 DAC2，修正稳态误差；
3. **Buck 供电余量前馈：** 根据设定电流和负载估计值计算 `VOUT+`，约 1 s 更新一次，用于保证 MOS 工作压差并降低发热。

其中 Buck 程序不是高速电流闭环，也不追踪每一次 ADC 抖动；快速恒流由模拟环完成。

### 4.2 主程序流程

```mermaid
flowchart TD
    A[系统上电] --> B[初始化 GPIO/ADC/DMA/SPI/UART/定时器]
    B --> C[初始化 DAC、串口屏、按键和编码器]
    C --> D[处理屏幕、按键与编码器]
    D --> E[读取三路 ADC 并进行滤波]
    E --> F{形成一组新数据?}
    F -- 否 --> D
    F -- 是 --> G[更新物理量与 ADC_FLAG]
    G --> H[Buck 前馈更新 DAC1]
    H --> I[增量式 PI 更新 DAC2]
    I --> J[执行保护和状态显示]
    J --> D
```

均值窗口和卡尔曼状态完成更新后置位 `ADC_FLAG`，DAC1、DAC2 只在新数据有效时更新。屏幕发送采用缓冲队列和串口中断机制，数值刷新与波形绘制不会在主循环中长时间等待。

### 4.3 数据采集与滤波

三路 ADC 原始值分别进入独立数组，达到设定样本数后计算均值，再送入三个独立的一维卡尔曼滤波器。最终代码中的典型参数为：

```text
Q   = 0.001
MEA = 0.05
```

均值滤波降低随机抖动，卡尔曼滤波改善显示稳定性。VOUT+、VOUT−、Vsense 分别维护独立状态，避免通道间相互覆盖。

### 4.4 电流设定前馈

历史标定得到 DAC2 命令电压与实测电流的关系：

$$
I_{meas}(mA)=0.498188\,V_{DAC2,cmd}(mV)+1.368386
$$

目标电流可反算为 DAC2 初始命令：

$$
V_{DAC2,ff}(mV)=\frac{I_{set}(mA)-1.368386}{0.498188}
$$

前馈用于使输出快速接近目标，PI 只修正剩余偏差。实际输出还经过上下限约束，避免异常变量产生超量程命令。

### 4.5 增量式 PI 电流修正

最终代码采用增量式 PI：

$$
e(k)=I_{set}(k)-I_{disp}(k)
$$

$$
\Delta u(k)=K_p[e(k)-e(k-1)]+K_i e(k)
$$

$$
u(k)=u(k-1)+\Delta u(k)
$$

参数为 `Kp=0.0007`、`Ki=0.00025`、`Kd=0`。程序设置误差死区，并将 DAC2 命令限制在 `0～1.4 V`。不使用微分项，是因为 ADC 量化噪声和 Buck 开关尖峰会被微分运算放大；本系统的主要动态响应已由模拟恒流环承担。

### 4.6 电流显示误差补偿

原始电流由 `V_SENSE/2 Ω` 得到。最终程序首先进行全量程基础修正：

$$
I_{base}=0.98189I_{raw}+4.821mA
$$

随后依据多点标定结果，对低电流区中可重复的剩余偏差作小幅补偿。该处理用于建立 ADC 读数与外部标准电流表之间的静态映射，属于测量仪器常用的标定方法。系统精度仍主要建立在高线性的模拟恒流内环、精密采样电阻和 PI 闭环基础上。

### 4.7 VOUT 校准、负载计算与显示

最终 VOUT 校准公式为：

$$
V_{OUT+,cal}=0.98663V_{OUT+,raw}+0.13675
$$

$$
V_{OUT-,cal}=0.97992V_{OUT-,raw}+0.24886
$$

校准后计算：

$$
V_{load}=V_{OUT+,cal}-V_{OUT-,cal}
$$

$$
R_{load}=\frac{V_{load}}{I_{disp}}
$$

低电流时除法会放大噪声，因此程序在电流过小时不更新负载阻值，正常工作区对结果进行滤波和范围限制。

### 4.8 Buck 供电余量前馈

最终代码每约 `1000 ms` 更新一次 Buck 控制量。目标电压为：

$$
V_{OUT+,target}=I_{set}R_{load}+I_{set}R_s+1.5V
$$

再由实测关系反算 DAC1：

$$
V_{DAC1}=\frac{V_{OUT+,target}+1.797554}{10.012879}
$$

DAC1 命令限制在硬件有效范围内。低于约 10 mA 时，程序将 DAC1 设置为较低的安全值，避免低电流或空载状态下 VOUT+ 无必要升高。该算法是低速前馈而非高速反馈：它根据当前负载估计给出合适供电余量，恒流精度仍由模拟内环和 DAC2 PI 保证。

### 4.9 人机交互与波形显示

串口屏能够显示设定电流、实际电流、VOUT+、VOUT−、负载电压、负载阻值、DAC 命令以及保护状态。编码器支持 `1 mA、10 mA、100 mA` 步进调节，按键用于输出控制和报警处理。

除数值显示外，屏幕内置双通道波形窗口：通道 0 绘制目标电流，通道 1 绘制实际电流。STM32 周期性调用波形数据发送函数，将两条曲线同步送入串口屏，因此能够直接观察设定变化、建立过程、稳态偏差和扰动恢复。这一功能既提高了现场展示效果，也为 PI 参数调整和异常排查提供了直观依据。

## 5 保护设计

### 5.1 过流保护

程序将 `550 mA` 作为过流阈值。当校准后的电流量超过阈值时，状态标志进入过流保护，主程序关闭 Buck，使目标电流和 DAC2 命令回到安全状态，并在串口屏显示故障信息。保护解除后由用户重新确认输出条件，避免自动反复启动。

### 5.2 短路限流

输出端短路时，负载电压接近零，但 OPA197、MOS 和采样电阻构成的模拟负反馈环仍会使 `V_SENSE` 跟随 DAC2 参考，因此电流被限制在设定值附近。短路保护的核心不是额外制造一个更高带宽的软件环，而是利用原有硬件恒流内环完成限流；Buck 前馈在低负载条件下降低 VOUT+，减少 MOS 在短路状态下的功耗。短路解除后，系统继续按负载估计更新供电余量。

### 5.3 开路检测

输出使能后，如果实际电流接近零，程序将其判为负载开路，关闭 Buck 并在屏幕显示开路告警。开路判断依赖电流反馈和 Buck 使能状态，不通过 `V/I` 计算，因此不会在电流接近零时产生除零问题。工程使用中应在输出连接稳定后再使能，并保证板间采样线与参考地连接可靠，避免接触不良被误认为负载开路。

### 5.4 保护测试结果

| 测试项目 | 测试方式 | 系统表现 | 结论 |
| --- | --- | --- | ---- |
| 过流 | 将输出条件推向 550 mA 以上 | Buck 关闭，输出命令进入安全状态，屏幕显示过流信息 | 通过 |
| 短路 | 输出端直接短接 | 模拟恒流环将电流限制在设定值附近，器件未出现损坏  | 通过 |
| 开路 | 工作过程中断开负载 | 电流降为零，系统关闭输出并显示开路告警 | 通过 |
| 故障恢复 | 排除故障后重新确认输出 | 系统可恢复正常工作 | 通过 |

## 6 设计、制作与调试过程

### 6.1 第一阶段：电源与 Buck 验证

首轮焊接后，先将恒流环关闭，仅验证输入保护、固定 5 V、3.3 V LDO 和可调 Buck。测试确认固定供电基本正常，可调 Buck 能随控制点变化。早期实验同时发现元件漏焊、封装不匹配、反馈电阻开路等问题，由此建立了“分模块上电、先电阻再电压、先固定电源再功率输出”的调试流程。

### 6.2 第二阶段：恒流模拟链路排查

初次测试中出现 DAC2 给定后 MOS 源极电压仍接近零的现象。逐点测量 DAC 输出、运放同相端、反相端、输出端和 MOS 三极后，定位到 DAC2 至运放输入的 R1 焊接不良。重新焊接后参考电压能够到达运放输入，验证了逐节点测量对模拟闭环排故的重要性。

同时观察到固定较高 `VOUT+` 时 MOS 明显发热，说明仅有线性恒流环虽然能够工作，但不适合宽负载范围长期运行。这一结果推动了后续 Buck 自动余量控制设计。

### 6.3 第三阶段：DAC 方案迭代

早期版本采用另一型号 DAC，调试中出现参考电压无法启动、输出高阻和焊接可靠性问题。经过 SPI 波形、供电、参考电压及芯片焊接检查后，团队决定更换为 MCP4822，并重新设计功率/模拟板。新方案具有内置基准、双通道结构清晰、驱动简单等优点，最终稳定实现 DAC1、DAC2 双路控制。

同时取消了容易形成悬浮节点的模拟开关，使 DAC2 经保护电阻直接进入恒流运放，并增加明确下拉路径。这一修改减少了启动状态不确定性，也简化了保护和调试逻辑。

### 6.4 第四阶段：第二版硬件联调

新板完成后，依次验证：

1. MCP4822 SPI 通信和实际输出；
2. DAC1 与 VOUT+ 的传递关系；
3. DAC2 与实测电流的传递关系；
4. `V_SENSE`、`VOUT+`、`VOUT−` 跨板采样；
5. 编码器、串口和串口屏通信。

测试中曾出现 VOUT+ 消失，最终定位为 Buck 反馈网络中的 R21 开路。重新焊接后 Buck 恢复。该问题说明功率反馈路径中的单个焊点即可使整机表现为严重故障，因此最终 PCB 增加关键测试点，并在装配后进行断电连通性检查。

跨板 ADC 联调还发现，随机取用的散装杜邦线会使 Vsense 和 VOUT 采样出现明显漂移或跳动。更换为接触可靠、长度一致并将模拟信号与 ADC_REF_GND 配对的固定线束后，采样稳定性显著改善。最终将线束与连接器纳入模拟测量链统一管理。

### 6.5 第五阶段：数据标定与软件重构

系统能够恒流后，采集 0～500 mA 多点数据，记录设定电流、DAC2 命令、DAC2 实测值、电流表值、ADC 显示值及 VOUT 参数。数据分析表明：

- 模拟恒流内环本身线性度极高；
- DAC 命令值与实际输出存在固定增益和零点偏差；
- ADC 电流显示存在比例误差和低电流残差；
- VOUT+、VOUT− 需要分别校准；
- 不同负载下 MOS 压差需要由 Buck 自动管理。

因此软件重构为独立的采样滤波、物理量换算、校准、PI、电源余量和保护模块，避免原先在主循环中混杂更新造成变量语义不清和调节周期不确定。

### 6.6 第六阶段：最终闭环与功能完成

最终阶段完成了：

- 低电流显示残差补偿；
- 电流 PI 参数调整；
- VOUT+、VOUT− 和负载阻值校准；
- Buck 负载前馈慢环；
- 过流、短路和开路保护；
- 串口屏数据显示和状态提示；
- 外壳结构与接口布局设计。

最终系统能够在改变设定电流和负载时自动调节 VOUT+，并保持输出电流稳定，形成从硬件、固件、交互到结构设计的完整作品。

### 6.7 关键迭代汇总

| 阶段 | 主要问题 | 定位方法 | 改进结果 |
| --- | --- | --- | --- |
| 初版供电 | 元件漏焊、反馈开路  | 断电阻值和分模块上电 | 固定 5 V、3.3 V 和 Buck 正常 |
| 恒流输入 | DAC2 未到达运放输入 | 测量 DAC2、R1、U2 +IN | 修复 R1 焊点，恒流链建立 |
| DAC 调试 | 参考和输出异常 | 独立供电、SPI 波形、芯片引脚检查 | 改用 MCP4822，双通道正常 |
| 功率温升 | MOS 压差过大 | 测量 VOUT−、Vsense 和温升 | 引入 Buck 余量控制和散热片 |
| 采样显示 | 电流与电压显示偏差  | 多点仪表对比和误差分析 | 完成线性校准和多点误差补偿 |
| 控制稳定 | 两个数字环互相干扰  | 降低更新频率、职责分离 | 模拟快环、PI 慢修正、Buck 更慢 |
| 安全功能 | 故障状态需自动处理  | 开路、短路、过流实测 | 三类保护通过 |

---

## 7 成果展示

### 7.1 硬件成果

项目完成了一套控制板和一套功率/模拟板。功率/模拟板集成输入保护、固定 5 V Buck、可调 Buck、MCP4822、OPA197、功率 MOS、2 Ω 精密采样电阻以及三路 ADC 前端；控制板集成 STM32、编码器、按键、串口屏接口和板间连接器。两板分离便于功率区与数字区独立调试，同时通过固定线束传递 DAC、控制和采样信号。

> **图 7-1 双板实物及连接关系**
> 

### 7.2 串口屏与波形显示

串口屏可显示设定电流、实际电流、VOUT+、VOUT−、负载阻值、DAC 命令、输出状态和故障状态。其波形页面同时绘制目标电流与实际电流，两条曲线能够直观反映设定阶跃、实际跟随和稳态波动。这一设计使恒流源不依赖外接上位机即可完成基本状态观察，也便于现场展示控制效果。

### 7.3 外壳结构设计

项目完成了针对双板系统的三维外壳方案。功率板位于底部并围绕 MOS、Buck 电感和采样电阻设置通风区域；串口屏固定在上盖开窗处；控制板和编码器布置在便于操作的面板位置。外壳采用分体式安装和可拆上盖，屏幕、控制板和功率板分别设置机械支撑，避免通过 PCB 或排线相互承力，并为内部线束预留弯折和检修空间。

### 7.4 软件与工程成果

项目仓库保存了最终 STM32 工程、串口屏工程、原理图与 PCB、外壳模型、测试日志、校准数据和分析图表。软件实现了 ADC 采样与滤波、增量式 PI、电源余量前馈、状态显示、双曲线波形以及三类故障处理。

### 7.5 项目特点

1. **Buck 与线性恒流协同：** Buck 管理功率余量，模拟环保证快速稳流，兼顾效率和精度；
2. **双 DAC 分工明确：** DAC1 管理供电余量，DAC2 管理恒流参考；
3. **可视化程度高：** 串口屏同时显示数值、状态以及目标/实际电流波形；
4. **测量链工程化：** 采用独立 ADC 参考地、精密 2 Ω 采样电阻和固定跨板线束；
5. **完整设计闭环：** 项目覆盖原理图、PCB、固件、测试标定、保护、人机界面和外壳结构。

## 8 测试方案与结果分析

### 8.1 测试仪器与条件

测试使用可调直流稳压电源、数字万用表、电流表、示波器以及多组功率电阻/滑动变阻器。输入电压主要为 24～30 V，测试前确认电源处于 CV 模式且限流不低于系统正常输入电流。电流表串接于输出回路，万用表分别测量 DAC、VOUT 和 Vsense 测试点；ADC 数据通过串口输出并同步显示在串口屏。

### 8.2 DAC2 实测电压与输出电流

测试得到：

$$
I_{meas}(mA)=0.497253V_{DAC2,meas}(mV)-0.029041
$$

决定系数 `R²=0.99999994`，RMSE 为 `0.041 mA`，最大残差约 `0.090 mA`。理论斜率为 `0.496715 mA/mV`，与实测结果接近，证明 OPA197、MOS 和 2 Ω 采样电阻构成的模拟内环具有良好线性。

DAC2实测电压与输出电流

### 8.3 设定电流与实测电流

综合校准表中，设定电流与电流表实测值的关系为：

$$
I_{meas}(mA)=0.994738I_{set}(mA)+0.067706
$$

去除 0 mA 点后，`R²=0.99999900`，RMSE 为 `0.165 mA`，最大残差为 `0.345 mA`。历史数据中 500 mA 点为 497.5 mA，误差 `−2.5 mA`，相对误差 `−0.50%`；低电流区绝对误差通常为亚毫安量级，但由于分母较小，相对误差更敏感。

设定电流与实测电流

电流设定误差

### 8.4 电流显示误差补偿

多点仪表对比表明，ADC 显示误差具有较稳定的增益和零点成分，低电流区还存在小幅、可重复的剩余偏差。程序先进行基础线性修正，再根据标定结果对剩余偏差作小幅补偿。补偿前典型的“电流表实测值减显示值”如下：

| I_set/mA | 差值/mA | I_set/mA | 差值/mA |
| ---: | ---: | ---: | ---: |
| 10 | 1.08 | 100 | 1.00 |
| 20 | 1.80 | 150 | 0.70 |
| 30 | 1.40 | 200 | 0.50 |
| 40 | 1.37 | 250 | 0.80 |
| 50 | 1.24 | 300 | 0.90 |
| 60 | 0.70 | 350 | 1.00 |
| 70 | 0.70 | 400 | 0.80 |
| 80 | 1.00 | 450 | 0.30 |
| 90 | 1.70 | 500 |  −0.10 |

这些误差相对于 0～500 mA 满量程很小，但在 10～100 mA 区间会明显影响相对误差，因此需要进行低电流标定。

### 8.5 VOUT+、VOUT− 校准

最终校准数据如下：

| VOUT+ 原始换算/V | 万用表/V | VOUT− 原始换算/V | 万用表/V |
| ---: | ---: | ---: | ---: |
| 4.94 | 5.007 | 1.60 | 1.865 |
| 12.02 | 12.004 | 9.24 | 9.237 |
| 20.14 | 20.002 | 17.36 | 17.247 |
| 27.22 | 26.994 | 24.46 | 24.249 |

得到：

$$
V_{OUT+,cal}=0.98663V_{OUT+,raw}+0.13675
$$

$$
V_{OUT-,cal}=0.97992V_{OUT-,raw}+0.24886
$$

校准后的电压足以支持负载阻值显示和 Buck 余量估计。

### 8.6 连续采样稳定性

三档连续串口数据统计如下：

| I_set/mA | 样本数 | I_actual 均值/mA | 标准差/mA | Vsense 均值/mV | Vsense 标准差/mV | RLOAD 均值/Ω | RLOAD 标准差/Ω | VMOS 均值/mV |
| ---: | -----: | ---: | ---: | ---: | ---: | ---: | ---: | ---: |
| 50 | 29 | 51.023 | 0.447 | 97.793 | 0.412 | 50.161 | 0.537 | 1920.4 |
| 250 | 30 | 252.685 | 0.377 | 501.900 | 0.305 | 49.759 | 0.097 | 2346.5 |
| 500 | 31 | 506.804 | 0.301 | 1009.742 | 0.514 | 49.631 | 0.039 | 1924.4 |

三档显示标准差均小于 0.5 mA。低电流时 `R=V/I` 对噪声更敏感，因此 50 mA 档负载显示波动大于高电流档。

连续串口数据稳定性

负载阻值显示稳定性

### 8.7 负载适应能力

测试覆盖短路、低阻负载以及约 50 Ω 高阻负载。短路时模拟环维持限流；负载升高时，Buck 前馈根据 `I_set(R_load+R_s)+1.5V` 提高 VOUT+，避免 MOS 压差不足。连续记录中 50 mA、250 mA 和 500 mA 三档均在约 50 Ω 负载附近保持稳定输出，说明系统可覆盖题目规定的高阻端工况。

负载调整率的测试方法为在固定 `I_set` 下连续改变负载，并计算：

$$
S_L=\frac{I_{max}-I_{min}}{I_{set}}\times100\%
$$

最终功能测试中，短路限流、高阻输出和负载变化均能正常工作。

### 8.8 Buck 自动调压和 MOS 余量

早期固定 DAC1 时，部分中高电流、高阻工况的 `V_MOS` 仅为 0.18～0.62 V，恒流环接近压差不足；500 mA 工况将 VOUT+ 提高至约 27.724 V 后，`V_MOS` 恢复至约 1.90 V。最终代码根据负载估计和设定电流每约 1 s 计算一次 VOUT+ 目标，使 MOS 获得约 1.5 V 设计余量，并避免低阻负载时承担不必要的功耗。

### 8.9 纹波测试

早期在 50 mA 档使用普通示波器探头得到约 5 mVpp 的读数。该结果混入长地线环路、Buck 高频尖峰和示波器噪声底，不能直接等同于真实低频电流纹波。题目所要求的 `0.2 mA` 对 2 Ω 采样电阻仅对应 `0.4 mVpp`，应使用短地弹簧、AC 耦合、20 MHz 限带，并首先测量噪声底。项目已完成测量链路分析，后续可使用差分探头或低噪声前置放大器提高毫伏以下测量可信度。

## 9 误差分析

### 9.1 DAC 量化与增益误差

MCP4822 为 12 位 DAC。量化、内部基准和通道增益误差使软件命令值与实际输出存在差异。测试中 `DAC2_meas→I_meas` 的 RMSE 仅为 0.041 mA，而 `DAC2_cmd→I_meas` 的 RMSE 为 0.361 mA，说明模拟恒流内环的本征误差很小，主要固定误差出现在 DAC 命令到实际参考电压的链路中。

### 9.2 采样电阻误差与温升

实际器件为 `PZWR0005B2R00A9` 精密绕线电阻，标称 `2 Ω、±0.1%、5 W`。500 mA 时功耗为：

$$
P_R=I^2R=0.5^2\times2=0.5W
$$

额定功率约为实际最大耗散的 10 倍，可降低温升引起的阻值漂移，并提高短路限流状态下的可靠性。绕线电阻存在寄生电感，但本项目输出为直流、控制带宽较低，其影响远小于阻值精度、布线和地参考误差。

### 9.3 运放和 MOS 误差

OPA197 输入失调会等效叠加到采样电压上；对 2 Ω 采样电阻而言，100 μV 对应约 0.05 mA。MOS 阈值和跨导变化不会直接决定闭环稳态电流，但会影响运放输出范围、动态响应和低压差可控能力。

### 9.4 ADC、参考电压与分压误差

STM32 ADC 的量化误差、3.3 V 参考偏差、分压器实际比例、采样时间和通道串扰都会影响 VOUT 与 Vsense。VOUT 需要约 11 倍还原，因此 ADC 端的微小偏差会被同步放大。VOUT+、VOUT− 分别标定可补偿两个通道的器件和布线差异。

### 9.5 接地、线束与接触误差

功率地存在 Buck、MOS 和负载回流，如果 ADC/DAC 参考与功率回路共用较长路径，地电位差会表现为电流零点和显示误差。系统采用 AGND/GND 单点连接、ADC_REF_GND 独立回流和采样线独立引出。

跨板调试中还验证了线束质量的重要性：散装杜邦线的长度、接触电阻和回路面积不一致，会使 ADC 跨板信号波动；固定压接排线、信号与参考地相邻、减少插拔和悬空连接后，稳定性明显改善。因此连接器、排针焊点和线束接触均属于误差链的一部分。

### 9.6 Buck 余量误差

负载估计不准或 Buck 更新不及时会使 `V_MOS` 偏离设计值。压差过小时恒流环可能饱和，压差过大时 MOS 发热增加。最终代码使用约 1 s 周期的负载前馈，避免 DAC1 高频动作扰动电流；负载突变后的短时间内则由模拟恒流环利用原有余量保持输出。

### 9.7 低电流相对误差

在 10～20 mA 区间，即使绝对误差只有 0.1～0.2 mA，相对误差也会显著增大。ADC 零点、运放失调、仪表分辨率和跨板地差在该区间占比更高。因此系统采用零点门限、滤波和多点标定后的残差补偿，而不将低电流误差简单归结为一个全量程比例系数。

### 9.8 测试仪器和方法误差

电流表会引入额外内阻和保险丝接触电阻；功率电阻实际值随温度变化；普通示波器探头在毫伏级测量时容易拾取地线环路噪声。测试时应固定仪表档位、线束和等待时间，并明确区分电流表实测值、ADC 显示值与理论计算值。

### 9.9 误差链总结

综合测试表明，误差贡献大致为：

```text
DAC命令与实际电压差异、ADC与地参考误差
> 采样电阻温漂、线束与仪表误差
> 模拟恒流内环的本征线性误差
```

因此系统采用“高线性模拟内环 + 数字标定和慢速修正”的结构：软件补偿的是稳定、可重复的系统偏差，而不是替代硬件闭环。

## 10 总结与展望

本项目完成了一套覆盖原理图、PCB、嵌入式固件、人机界面、数据标定和外壳结构的高精度数控恒流源。系统采用可调 Buck 与线性恒流环结合的结构：OPA197、MOS 和 2 Ω 精密采样电阻承担快速恒流，STM32 和 MCP4822 完成数字设定、PI 修正以及 Buck 供电余量管理，从而兼顾输出精度、负载范围和功率器件温升。

测试表明，模拟恒流链的电压—电流斜率与理论值接近，连续显示标准差小于 0.5 mA；系统能够完成 0～500 mA 调节、高阻负载输出、短路限流、开路报警和过流关断。串口屏不仅显示数值和状态，还实时绘制目标电流与实际电流双通道波形；三维外壳方案进一步考虑了屏幕开窗、操作面板、功率器件散热、双板支撑和线束检修。

项目调试经历了电源反馈开路、DAC 方案更换、模拟节点悬浮、焊点接触、跨板 ADC 线束干扰以及多环职责划分等问题。通过分模块上电、逐节点测量、多点仪表对比和软件重构，最终形成了可运行、可测量、可展示的完整系统。

后续可从以下方面继续提升：

1. 使用独立精密基准和外置高分辨率 ADC，提高低电流绝对精度；
2. 对采样电阻实施更严格的 Kelvin 四线连接，并使用定制屏蔽线束；
3. 在保持 Buck 低速稳定的前提下，改善负载阶跃后的余量恢复速度；
4. 使用低噪声差分测量链，对 0.2 mA 纹波指标进行高置信度验证；
5. 增加参数保存、上位机记录和自动化测试功能。

总体而言，系统实现了题目要求的数控恒流、参数测量、自动供电余量调节和安全保护，具有较好的完整性、可扩展性和工程实践价值。

## 附录 A 关键控制公式汇总

| 项目 | 公式 |
| --- | --- |
| DAC2 理论电流 | `Iout_mA≈0.496715×DAC2_meas_mV` |
| DAC2 实测关系 | `I_meas_mA=0.497253×DAC2_meas_mV−0.029041` |
| DAC2 命令前馈 | `DAC2_cmd_mV=(I_set_mA−1.368386)/0.498188`  |
| 电流基础校准  | `I_base=0.98189×I_raw+0.004821 A` |
| VOUT+ 校准 | `VOUTP_cal=0.98663×VOUTP_raw+0.13675 V` |
| VOUT− 校准 | `VOUTN_cal=0.97992×VOUTN_raw+0.24886 V` |
| 负载电压 | `Vload=VOUTP_cal−VOUTN_cal` |
| 负载阻值 | `Rload=Vload/I_disp` |
| MOS 压差 | `VMOS=VOUTN_cal−Vsense` |
| Buck 目标 | `VOUTP_target=I_set×(Rload+2Ω)+1.5V` |
| DAC1 反算 | `DAC1=(VOUTP_target+1.797554)/10.012879` |
| MOS 功耗 | `PMOS=VMOS×Iout` |
| 纹波换算 | `Iripple_pp=Vpp/Rs` |

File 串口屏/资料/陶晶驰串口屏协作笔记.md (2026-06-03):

# 陶晶驰串口屏协作笔记

本文用于后续开发高精度数控恒流源的串口屏界面和 STM32 联调代码。资料来源为本目录下的 `官方网页.md`、`开发手册.pdf`、`例程.zip`，以及陶晶驰官方 wiki/官网页面入口。

## 1. 基本模型

陶晶驰串口屏的开发分两部分：

1. 在 PC 端的 USART HMI 工具里制作 HMI 工程，放置页面和控件，编写屏内事件脚本，然后编译生成 `*.tft` 下载到屏。
2. MCU 通过 UART 给屏幕发送 ASCII 指令，并解析屏幕返回的串口数据。

屏幕端不是普通液晶裸屏，而是带脚本解释器的 HMI 设备。绝大多数 UI 改动都可以通过类似 `控件.属性=值` 的命令完成，例如：

```c
tjc_send_string("main.t_set.txt=\"1.234\"");
tjc_send_string("main.n_current.val=1234");
tjc_send_string("page setting");
```

所有串口指令必须以 3 个字节 `0xff 0xff 0xff` 结尾。用 C 字符串发送时常写成：

```c
printf("n0.val=666\xff\xff\xff");
```

建议项目中封装一个 `tjc_send_cmd()`，统一追加结束符，避免漏发。

## 2. 串口与电气连接

常规连接：

- 屏幕 TX 接 STM32 RX。
- 屏幕 RX 接 STM32 TX。
- GND 共地。
- 屏幕按型号供电，常见为 5 V，实际以产品型号页和丝印为准。

默认联调建议：

- UART: `115200, 8N1`。
- 不开硬件流控。
- STM32 先用中断或 DMA 接收，进入环形缓冲区，再由主循环解析完整帧。

波特率相关：

- `baud=115200`：修改当前运行波特率，掉电不一定保存。
- `bauds=115200`：保存波特率配置，写入后通常需要复位/重新连接确认。
- HMI 工程 `program.s` 中常设置：

```text
bauds=115200
bkcmd=0
page 0
```

## 3. 指令格式

### 3.1 设置控件属性

文本控件：

```text
t0.txt="hello"
main.t_current.txt="12.345mA"
```

数值控件：

```text
n0.val=123
main.n_dac.val=32768
```

颜色、显隐、使能等属性也可直接设置，具体属性取决于控件类型。

### 3.2 页面跳转

```text
page 0
page main
```

建议正式项目使用页面名，减少页面 ID 改动带来的问题。

### 3.3 刷新与可见性

```text
ref t0          // 刷新单个控件
ref 0           // 刷新当前页
vis b0,0        // 隐藏 b0
vis b0,1        // 显示 b0
tsw b0,0        // 禁止触摸 b0
tsw b0,1        // 允许触摸 b0
tsw 255,0       // 禁止当前页所有控件触摸
tsw 255,1       // 恢复当前页所有控件触摸
```

实际工程中，进行危险操作或保存参数时可短暂 `tsw 255,0`，处理完成后恢复。

### 3.4 模拟点击

```text
click b0,1      // 触发按下事件
click b0,0      // 触发释放事件
```

可用于 MCU 主动驱动屏幕执行某个按钮事件，但正式项目更推荐把共用逻辑写成页面/控件事件脚本或 MCU 端函数，避免“假点击”导致状态难追。

### 3.5 获取控件值

```text
get n0.val
get t0.txt
```

屏幕会返回数值帧或字符串帧。MCU 必须按返回帧格式解析，不要把它当普通 ASCII 行。

### 3.6 屏幕主动发原始数据

屏内事件脚本常用：

```text
printh 55 01 04 01 ff ff ff
prints h0.val,1
```

- `printh` 发送十六进制字节。
- `prints` 发送变量原始内容，可按指定长度输出。

官方例程使用了自定义 7 字节帧：

```text
55 cmd data0 data1 ff ff ff
```

例如：

```text
printh 55 01 04 01 ff ff ff
```

表示命令 `0x01`，对象/通道 `0x04`，状态 `0x01`。

## 4. 屏幕返回帧

所有屏幕返回数据通常也以 `ff ff ff` 结束。常见帧包括：

- `0x65 page_id component_id event ff ff ff`：触摸事件返回。`event=0x01` 多表示按下，`event=0x00` 多表示释放。
- `0x66 page_id ff ff ff`：当前页面 ID 返回，常由 `sendme` 触发。
- `0x70 ascii... ff ff ff`：字符串数据返回，常由 `get t0.txt` 触发。
- `0x71 value[4] ff ff ff`：数值数据返回，常由 `get n0.val` 触发，数值通常为小端 32 位。
- `0x00 ff ff ff`、`0x01 ff ff ff` 等：指令执行状态返回，受 `bkcmd` 影响。
- `0x86 ff ff ff`：设备进入睡眠。
- `0x87 ff ff ff`：设备自动唤醒。
- `0x88 ff ff ff`：设备上电初始化完成。

`bkcmd` 控制指令执行结果是否返回：

- `bkcmd=0`：不返回普通指令执行结果，减少串口负担。
- `bkcmd=1/2/3`：按不同级别返回成功/失败信息，调试时可打开。

建议开发期使用 `bkcmd=3` 检查指令错误，正式运行改为 `bkcmd=0` 或低返回级别。

## 5. STM32 端建议架构

### 5.1 发送封装

建议最少实现：

```c
void tjc_send_cmd(const char *cmd);
void tjc_set_txt(const char *obj, const char *txt);
void tjc_set_val(const char *obj, int32_t val);
void tjc_page(const char *page_name);
```

实现要点：

- 所有函数最终都调用同一个 UART 发送函数。
- 自动追加 `0xff 0xff 0xff`。
- 文本值需要自动加双引号，例如 `t0.txt="abc"`。
- 避免在中断里拼接长字符串。

### 5.2 接收解析

推荐流程：

1. UART 中断或 DMA 收字节，写入环形缓冲。
2. 主循环或任务中查找完整帧，以 `ff ff ff` 作为帧尾。
3. 按首字节分发：
   - `0x65`：官方触摸事件。
   - `0x66`：页面 ID。
   - `0x70`：字符串返回。
   - `0x71`：数值返回。
   - `0x55` 或项目自定义帧头：屏内脚本主动发给 MCU 的业务命令。
4. 解析成功后从环形缓冲删除整帧；帧头不匹配时删除 1 字节重新同步。

官方 HAL 例程的 `deleteRingBuffer()` 代码中 `return` 位于 `for` 循环内部，按实际效果只删除 1 字节。移植时应修正为循环完成后再返回。

### 5.3 自定义协议建议

对恒流源项目，建议不用屏幕默认触摸事件直接承载业务，而是在屏内按钮/滑块事件里发自定义帧：

```text
55 cmd len payload... checksum ff ff ff
```

最简版可先使用：

```text
55 cmd data0 data1 ff ff ff
```

后续如果命令变多，再升级为带长度和校验的帧。命令建议预留：

- `0x01`：设置输出电流，单位可用 uA 或 0.001 mA。
- `0x02`：输出使能/关闭。
- `0x03`：切换量程或模式。
- `0x04`：请求 MCU 回传当前测量值。
- `0x05`：校准参数保存/读取。
- `0x06`：报警确认。

屏幕只负责输入意图，真正的限幅、斜坡、保护、校准换算必须在 MCU 端完成。

## 6. 恒流源界面初步拆分

建议页面：

- `main`：设定电流、实际电流、输出电压/功率、输出开关、状态/报警。
- `set`：数字键盘或步进设置，支持 mA/uA 单位。
- `cal`：校准入口，显示 DAC 码、ADC 原始值、拟合参数。
- `protect`：过压、过流、过温、合规电压余量等保护状态。
- `about` 或 `debug`：固件版本、屏幕版本、串口状态、原始测量值。

建议控件命名：

- 文本显示用 `t_` 前缀，如 `t_i_set`、`t_i_meas`、`t_status`。
- 数值变量用 `n_` 前缀，如 `n_i_set_ua`、`n_output_en`。
- 按钮用 `b_` 前缀，如 `b_out`、`b_set`、`b_cal_save`。
- 滑块用 `h_` 或 `j_` 前缀，具体跟工具默认控件类型保持一致。

MCU 定期刷新屏幕的内容：

- 设定电流。
- 实测电流。
- 输出电压或 MOS 管余量。
- DAC 码/ADC 码。
- 输出状态。
- 保护/报警状态。

屏幕发给 MCU 的内容：

- 用户确认后的设定值。
- 输出开关命令。
- 校准点确认。
- 页面切换后的数据请求。

## 7. 调试清单

1. 用 USB-TTL 单独连屏，确认 `baud` 和供电。
2. 串口助手发送 `page 0 ff ff ff`、`t0.txt="OK" ff ff ff` 验证屏幕接收。
3. 屏幕按钮事件写 `printh 55 01 01 01 ff ff ff`，串口助手确认返回。
4. STM32 接屏后先只打印/记录收到的十六进制帧。
5. 再打开业务解析，确认帧尾同步和异常帧恢复。
6. 最后才接入 DAC 输出控制，且必须在 MCU 端做电流限幅和输出使能保护。

## 8. 后续协作约定

后续我会按这个思路协助：

- 设计 HMI 页面时，先定页面名、控件名、事件帧。
- 写 STM32 代码时，先实现稳定的 `tjc_send` 和 `tjc_parse` 模块。
- 联调时，用串口助手先验证每条屏幕脚本，再接 MCU 业务逻辑。
- 所有危险输出命令都先进入 MCU 的安全状态机，屏幕命令不直接改 DAC。

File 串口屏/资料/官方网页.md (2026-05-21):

[产品型号](https://www.tjc1688.com/contents/7/13.html)
[资料中心](http://wiki.tjc1688.com/start/index.html#)
[stm32联调](http://wiki.tjc1688.com/debug/stm32/index.html)

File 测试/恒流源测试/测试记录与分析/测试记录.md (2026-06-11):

# 测试记录

## 第一次测试（5.14周四晚）

第二版需要修改：
元件临时替换
C29（1uF）（忘买了）暂时用10uF替代✔
C24（22uF/63V）（封装和耐压不匹配）暂时用10uF/50V替代✔
R15和R21（以及R8、R37）100kΩ（忘买了）暂用插件替代✔
SMD焊盘不匹配：U4、U8、U13、U14 ✔
部分丝印被遮挡/未标出，R22与R23的丝印反了（还有哪反了？）✔
LED1坏了✔
测试结论：除了可调buck以外的供电/降压电路都没有问题

## 第二次测试（5.16周六早）

万用表测不了贴片电阻阻值（R22=10kΩ较精确）
因为R15断开导致5V降不了，D4烧毁
由实测数据拟合得到可调buck输出公式：VOUT+ = 31.242 - 10.011 * V_DAC1
由公式计算最值：0（-1.794）~31.242V 范围合适
有误差（比如4.8/5）但没什么问题。（因为公式精度只影响 Buck 输出和 MOS 余量估计，误差 0.2V 左右可以接受，而且最后可以靠adc反馈自动微调）
负载45Ω，VOUT+二十几伏/15V，给SWIN使能，
DAC_CH2给0.1V，测得mos栅极1.55V，漏极23.694V，源极约为0
DAC_CH2给0.2V，栅极1.6V，漏极接近VOUT+，源极仍为0
记录了调整DAC_CH1时VOUT+的响应速度，VOUT+向下调很快，向上则较慢（后续调整哪里的电容？）
测试结论：可调buck降压电路没问题，mos和运放还需研究
需要进一步测试：
DAC_CH2给电压时，运放IN+（U2pin3）是否有电压？
运放的各引脚电压（主要是IN+-、OUT）看运放是否正常工作

## 第三次测试（5.17周日早）

过程记录：
R3附近丝印VOUT+标错了吧，那个应该是ADCREFGND，所以0V是正常的

---

VIN为15V，负载45Ω，DACCH1给0，DACCH2给0，
VOUT+为14.897，VOUT-为14.839
VOUT+为14.890，VOUT-为14.824
VOUT+为14.894，VOUT-为14.817
上电时间在5分钟以内
观察到，单片机绿色led自动熄灭——应该是自动复位
继续测，5V、3.3V、bucken、swin都正常，估计是噪声使mcu复位
Mos数据：
Vg=1.557V，Vd=VOUT-=14.846V，Vs=0
观察到IN+没法接受到DACCH2的0.2V电压，怀疑断路，发现R1确实没焊好，于是重新焊好R1

---

DACCH2不给电压：
Vload=1.871
VOUT+=14.574
VOUT-=12.750

---

Vload=0.350
VOUT+=14.877
VOUT-=14.526
Mos：
Vg=1.7V
Vd=VOUT-
Vs=17mV

---

VOUT+=14.520
VOUT-=10.356
Vload=4.149
电源显示电流0.10~0.11A
Vd=2V，Vs=195mV
Mos很烫（因为15V对mos来说太多）

---

VIN改成8V后，发现不使能时，VOUT+还有一点多伏，接在万用表两端正在稳定缓慢放电。我每次等到放电放至10mV以内时再使能，发现VIN无论是8V还是15V，使能后都没有再出现电流很大的现象——我猜和哪个电容没放完电有关。

---

VIN给8V，确保VOUT+放电完毕，还没开始使能，发现单片机红色电源灯自己熄灭了，但重新上电还能亮，我就暂时没管这个继续测了
打算绕过R1，0.2V不给DACCH2直接给com脚：
模拟开关Com给0.2V，电源显示电流到0.12A，
此时VOUT+=7.7V，VOUT-=3V，Vload=4V
且马上撤去com电压，只要上电&使能，0.12A（0.11A）就能保持——这个肯定是放电问题，但又不是VOUT+的放电问题，因为VOUT+我再看一次确保使能前是0V了，但再使能还是有0.11A的电流
我再次测试，使能后还是0.11A，测了com的电压，从约200mV马上减小到约0V，同时观察到0.11A变成0.02A（多次复现后确认是com脚的放电问题，而且要使能后放电效果最好）
过了十分钟吧，再使能，电流掉到0.04A了（说明com脚自动放电很慢）
没使能的时候测com，从24mV一下放电为0V，这时再使能就是0.02A了
单片机电源灯自动熄灭原因分析：我让com悬浮后又放电后，接着马上重新上电的一小段时间内，单片机电源灯不亮，我测5V和3V3都是正常的，然后测完就发现单片机又能一直稳定亮了——单片机的供电也受到了放电的影响？（但这是在放电后的影响）总之这个隔一小段时间才能稳定给单片机供电的现象是可以复现的。
测模拟开关：
SWIN=0，u1的pin2/3有一个是-35mV，其他都正常
SWIN=1，没有不符合预期的异常数据。Agnd也都是精确的0V。
数据分析：
0.01A/15V和0.02A/8V是数字电源待机输入电流，表示基本无负载输出；
0.12A是电源输入电流，适合仅作为有无负载输出的状态判断，不用计算
标红数据：Is= Vload / 45Ω ≈0.089A，与理论值0.1A目标电流接近（先不纠结误差，因为实验数据记录并不严谨和精确）
测试结论：
运放和mos都是正常的，模拟开关本身应该也没问题，问题定位到模拟开关的com脚上
猜测原因：
撤掉手动电压后是开路，不是 0V；COM/+IN 有 C1 和高阻输入，所以会存电。（“断开0.2V”和“把该电源通道输出设成0V并保持开启”是不同的，dac输出0V也不是悬空，而是把输出拉到0V附近）
如果是这样，那么保证单片机和dac芯片的稳定通信就能解决问题，但还是建议焊上下拉电阻47kΩ（并在第二版中做相应修改）

## 第四次测试（5.21周四晚）

可调buck分压问题：DAC_CH1为0.75时，VOUT+预期是23.73V，以后记得VIN要调到大于VOUT+预期值
DAC_CH1不受单片机指令控制，一直保持=FB电压（0.75V），说明DAC_CH1输出是高阻态（被FB拉到相同电压），说明DAC芯片没有输出
DAC芯片引脚电压记录
pin1：DAC_CH1 0.75
pin2：DAC_CH2 0
pin4：LDAC# 0
pin5：CLR# 3.3V
pin6：SYNC# 3.3V
pin7：SCLK 0
pin8：DIN 0
pin9：AVDD 3.3V
pin10：VREFIN/VREFOUT 0
示波器可以看到spi的方波信号（到底是哪个脚的信号？）
要做dac单独模块排查
BUCK_EN = 0
只保留 3.3V
直接测 U3 pin1 / pin2 / pin10
先让 DAC 本体输出 0V、1V、2V 成功
再接回 Buck 和恒流环
串口输出、adc、编码器✅
除了dac模块其他都没问题，先跳过dac，继续手动给dac1和2的电
尝试复现测试三现象，但给了一次dacch2的0.2V后，单片机就自动复位了（绿灯灭），撤去0.2V，一按下使能按键单片机就复位，绿灯按下去才亮松开就灭（使能了才复位？还是单片机一直在复位？）用万用表给com放电后单片机才可以稳定开启使能
在COM右端和agnd测试点焊盘之间焊上47kΩ后：
为什么一给com脚0.2V，单片机同时自动复位？并且用万用表测com脚两端电压，发现电压从0V附近稳定上升到70mV，有时又跳变到更低，但最终这么做时间长了（至少半分钟）都会变成突然跳到5V输出（不是手不稳定的问题，附近也没有5V的电压）同时伴随着单片机电源灯熄灭？（此现象发生过至少三次，且最终都没有损坏单片机）
47kΩ电阻真的形成放电路径了吗？有时测com脚电压，能逐渐上升到十几二十几甚至更高mV最后突变到5V，有一两次又稳定在一点多/二点多mV上。而万用表的测量其实也是在放电，这样就不确定电是谁放的、万用表又引入了什么影响——AI建议还是要断电测电阻
AI建议测试操作2：

1. 全部断电，VOUT+ 放干净。
2. 测 COM、AGND、U1 pin4、U2 pin3、U2 pin6、+5V 之间的电阻。
3. 如果 COM 到 U2 OUT 或 +5V 不是开路/高阻，先清焊点、洗助焊剂、重焊 47k。
4. 上电但 BUCK_EN=0，不给 COM 0.2V，只测 COM、U2 +IN、U2 OUT 是否自己爬升。
   （此现象没尝试复现过）运放的out脚，在com电压跳变到5V后，测得接近5V。但后面com正常时out脚就是1.2（还是1.6来着）左右
   对比第三次测试，既然接线和硬件相同，为什么那次就没有“一给”0.2V就复位的问题？是因为（之前代码只用到了bucken和swin的同时使能按键）新的代码复杂度增加影响了单片机吗？还是今天连线哪里有问题？（拆下来接上去过好几次，大概率没问题）
   Safe_off能直接产生类似复位的现象，可能导致混淆，这个很可疑
   ——先禁用safeoff的灭灯功能，看看下次测试还有没有绿灯熄灭现象
   Dacch2是否能代替com，这也还没验证（模拟开关）
   5V到底是哪来的？这是最奇怪的问题（其实我只有第一次观察到了5V，后面都是听到万用表切换到V档、看见单片机电源灯熄灭，而并没有直接看到是5V还是几V）
   观察到用手碰焊上去的47kΩ下拉电阻时，电源电流从0.02变成0.03/0.04A

下一步测试：
Dac芯片独立测试
5V来源硬件检查（见“测试操作2”）
Safeoff代码清零验证

## 第五次测试（5.22周五晚）

Dac芯片独立测试：
烧录了ai提供的第一版代码，只给3V3焊盘上电，前四个（见聊天记录）都符合预期，就是pin10没有输出（测的全都是电容不是小引脚）
做了几轮代码（包括软件spi）和硬件检查，结论是要么是焊接导致芯片整体偏移，要么是芯片本身真的坏了，最好重新焊接一下，还不行就是芯片坏了，干脆换一个芯片
5V来源硬件检查：
【给下一块板的启示】
DAC 输出到运放 +IN 不要经过容易悬浮的模拟开关，直接到运放输入，中间可串 100Ω～1k 保护电阻；
运放 +IN 必须有明确下拉/默认 0V 路径；
DAC 输出、运放 +IN、运放 OUT、MOS Gate、+5V 都留测试点；
高阻模拟节点周围少放脏焊点、飞线、临时插件；
不要再让“断开输入”变成悬空状态。
新图建议这样画：
DAC_OUT ── 100Ω~1k ── 运放 +IN
│
47k~100k
│
AGND
没来得及做VIN上电时的检查
Safeoff代码清零验证：
没来得及验证去掉safeoff后，是否还有“com给电后一按按键绿灯就灭”的现象
下一步（最后）测试：
Dac芯片重焊，烧ai给的测试代码，看能不能开启2.5V参考电压，不行就放弃这个芯片

## 第六次测试（5.23周六早）

Dac8562还是不行，遂放弃，画新的原理图并重新打板

## 第七次测试（5.28周日晚）

新板子dac芯片本身正常了，出现了一些代码上的问题

## 第八次测试（5.30周六早）

硬件部分大致测试通过，剩下软件

## 第九次测试（5.31周日晚）

VOUT+消失——发现是因为R21断路
dac1的设定值与实际值✅
dac1与Vout+的公式get✅
Vsense的采样值（算得实际电流）与用电流表测得实际电流的线性校准公式get✅（还没算好）
一个注意事项：电源限流要设到0.5A，否则CV切换到CC使3V3和5V掉电波动、单片机复位
发现电位器在450mA（45欧）的时候就会烧（所以这次没测500mA，要测的话就之后调小电阻吧）
获取测试数据01

## 第十次测试（6.2周二晚）

获取测试数据02，算出校准公式

## 第十一次测试（6.4周四晚）

校准公式不准
代码重构

## 第十二次测试（6.6周六早）

代码重构完成，剩下小电流Idisp校准、显示滤波问题、三大保护逻辑、…

## 第十三次测试（6.9周二晚）

电流校准完成，pi与滤波调参完成

## 第十四次测试（6.11周四晚）
VOUT+-与Rload校准完成
BUCK慢环添加完成
电流重新校准完成
三大保护测试通过
外壳设计完成

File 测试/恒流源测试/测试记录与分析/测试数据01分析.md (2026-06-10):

# 恒流源测试数据01分析报告

## 1. 电路工作链路概述

从原理图看，系统由控制板和功率/模拟板组成。输入电源经保护和滤波后产生 `VBUS/VBUS_FILT`，一路固定 BUCK 产生 `+5V`，再由 LDO 产生 `3V3`；另一路可调 BUCK 产生 `VOUT+`。控制板通过 SPI 驱动 `MCP4822` 双通道 DAC，其中：

- `DAC_CH1` 参与可调 BUCK 的 FB 求和节点，决定输出电压上限/工作点；
- `DAC_CH2` 作为恒流参考，送入 `OPA197`，运放驱动 MOS 管，使采样电阻电压跟随参考；
- `ADC_VOUT+ / ADC_VOUT- / V_SENSE` 回到 MCU，用于电压、电流和压差状态判断。

因此这个电源更准确地说是：**BUCK 提供可调电压余量，运放+MOS+采样电阻形成恒流闭环，MCU/DAC 给定目标值。**

从控制结构上看，它不是单纯靠 BUCK 闭环直接恒流，而是两级控制：

```text
DAC1 -> 可调BUCK反馈节点 -> 决定VOUT+可用电压余量
DAC2 -> 运放恒流参考 -> MOS线性调整 -> 决定负载电流
```

这个结构的优点是恒流环可以由模拟运放快速闭合，MCU 只需要给 DAC 目标值；缺点是 MOS 上必须保留足够压差，BUCK 输出电压设得太低时恒流环会进入饱和。

## 2. 可调 BUCK 反馈节点理论公式

原理图中可调 BUCK 的 FB 节点连接：

- `R21 = 100kΩ`：从 `VOUT+` 到 FB；
- `R20 = 3.3kΩ`：从 FB 到 GND；
- `R22 = 10kΩ`：从控制注入电压 `Vinj` 到 FB；
- LMR16030 的 FB 稳态电压记为 `Vfb`，典型值约 `0.75V`。

对 FB 节点列 KCL：

```text
(Vout - Vfb)/R21 + (Vinj - Vfb)/R22 + (0 - Vfb)/R20 = 0
```

整理得：

```text
Vout = Vfb * (1 + R21/R20 + R21/R22) - (R21/R22) * Vinj
```

这里的物理含义是：

- `R21/R20` 决定普通 BUCK 分压反馈的基础放大倍数；
- `R21/R22` 决定外部控制电压对输出电压的调制增益；
- 因为 `Vinj` 项前面是负号，所以注入电压升高会让 BUCK 输出下降；
- 只要 FB 节点输入电流很小，且 BUCK 能正常闭环，这个线性求和模型就成立。

代入原理图阻值：

```text
1 + R21/R20 + R21/R22 = 41.3030
R21/R22 = 10.0000
Vout = 41.3030 * Vfb - 10 * Vinj
```

若取 `Vfb = 0.75V`：

```text
Vout ≈ 30.9773 - 10 * Vinj
```

由 Sheet1 实测截距反推：

```text
Vfb_eff = 31.241957 / 41.3030 = 0.756408 V
```

这与 `0.75V` 典型值接近，说明 FB 求和模型与原理图吻合。

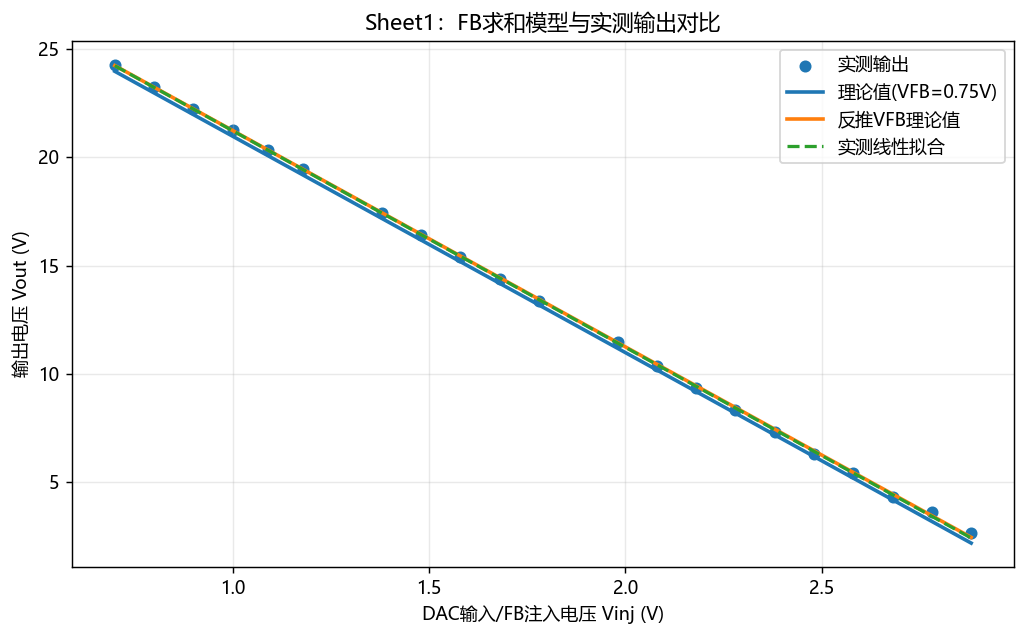
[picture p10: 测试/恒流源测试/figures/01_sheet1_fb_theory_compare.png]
Sheet1 FB理论对比


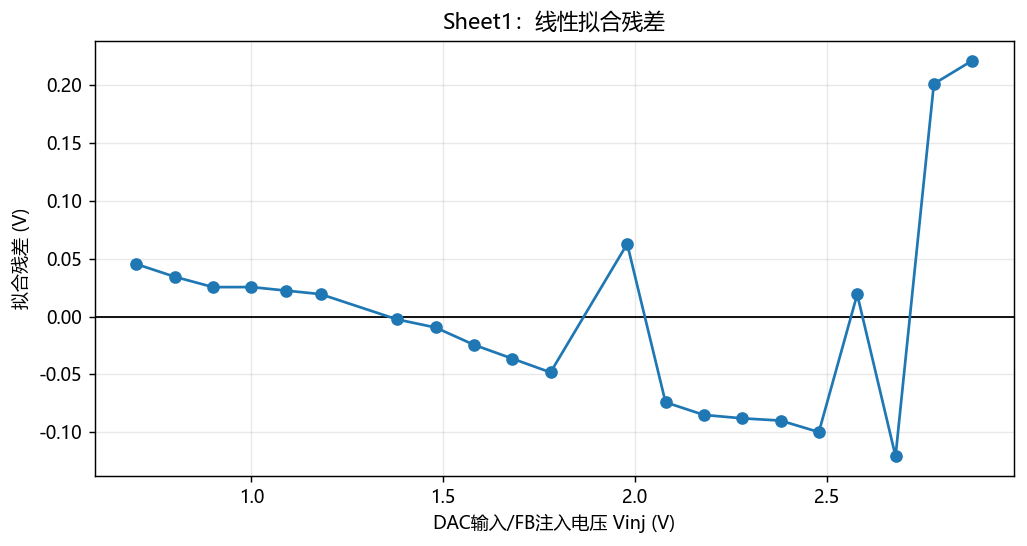
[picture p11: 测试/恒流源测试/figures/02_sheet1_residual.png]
Sheet1残差


Sheet1 实测拟合：

```text
Vout = -10.010538 * Vinj + 31.241957
R² = 0.99983856
最大残差 = 0.221 V
平均绝对残差 = 0.065 V
```

结论：斜率理论值为 `-10`，实测为 `-10.0105`，非常接近；截距对应的 FB 等效参考约 `0.7564V`。

## 3. DAC1 到输出电压的正向调压关系

在 Sheet2 的 DAC1 标定中，输出随 `DAC1_actual` 增大而增大。结合前面的反向 FB 注入公式，可以理解为运放/控制级使：

```text
Vinj ≈ 3.3V - VDAC1
```

这个关系来自硬件上 `DAC_CH1` 经运放和电阻网络参与 FB 控制。若运放工作在线性区，且它把 DAC1 转换成相对于 `3V3` 的反向控制量，那么 DAC1 越高，实际送入 FB 求和节点的 `Vinj` 越低；由于 `Vout` 对 `Vinj` 的系数是 `-10`，最终表现为 DAC1 越高，`VOUT+` 越高。

代入 FB 求和公式：

```text
Vout = 10 * VDAC1 + (41.3030 * Vfb - 33)
```

使用反推 `Vfb_eff = 0.756408V`：

```text
Vout ≈ 10 * VDAC1 -1.7580
```

实测拟合：

```text
Vout = 10.012879 * VDAC1(V) -1.797554
R² = 0.99999995
最大残差 = 0.000898 V
```

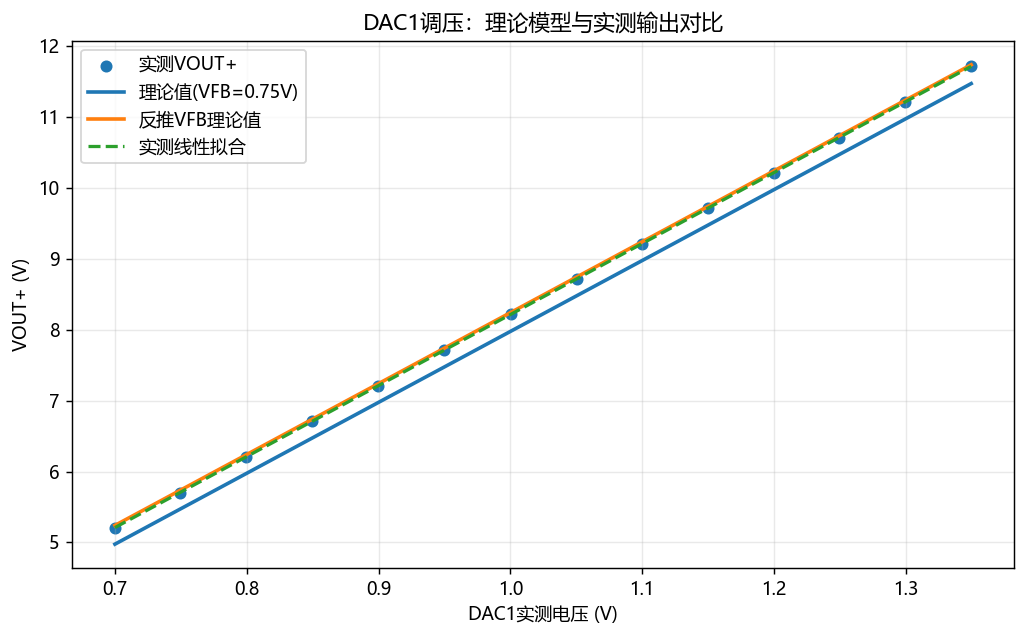
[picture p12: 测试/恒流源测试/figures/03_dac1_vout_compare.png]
DAC1理论对比


结论：DAC1 每增加 `100mV`，输出电压约增加 `1.001V`。实测斜率与理论 `10V/V` 基本一致，说明可调 BUCK 的 DAC 控制链路线性很好。DAC1 本身最大实测误差约 `0.900mV`。

这组结果也说明目前 DAC1 控制输出电压的主要误差不是线性误差，而更可能来自：

- LMR16030 FB 参考电压的实际值与典型值偏差；
- DAC1 输出零点/满量程误差；
- 运放输出摆幅、输入失调和电阻精度；
- 测量仪表或采样换算的小偏差。

## 4. DAC2 恒流理论公式

恒流环中，`DAC_CH2` 经 `R1=330Ω` 串联后，节点由 `R6=49.9kΩ` 到 AGND，并经 `C5` 滤波送入 `OPA197` 正输入端。理想情况下，运放调节 MOS 管，使采样电阻电压等于该参考电压：

```text
Vref_i = VDAC2 * 49.9k / (49.9k + 330)
Iout = Vref_i / Rsense
```

若 `Rsense = 2Ω`：

```text
Iout = VDAC2 * 0.993430 / 2Ω
```

硬件上运放闭环的目标可以理解为：

```text
V+ = Vref_i
V- = Vsense = Iout * Rsense
运放调节MOS栅极，直到 V- ≈ V+
```

所以理想恒流值只由 `DAC2参考电压 / 采样电阻` 决定。MOS、负载和 BUCK 输出电压主要决定“能不能达到这个电流”，而不是理想电流公式本身。也就是说，只要 MOS 未饱和、运放未饱和、BUCK 电压余量足够，恒流公式应当成立。

用 `mV` 和 `mA` 表示：

```text
Iout(mA) ≈ 0.496715 * DAC2(mV)
```

如果忽略 `330Ω` 与 `49.9kΩ` 的轻微分压，则近似为：

```text
Iout(mA) ≈ 0.5 * DAC2(mV)
```

实测拟合：

```text
Iout = 0.498058 * DAC2_Target(mV) +1.685285
R² = 0.99999300
最大拟合残差 = 0.891 mA
```

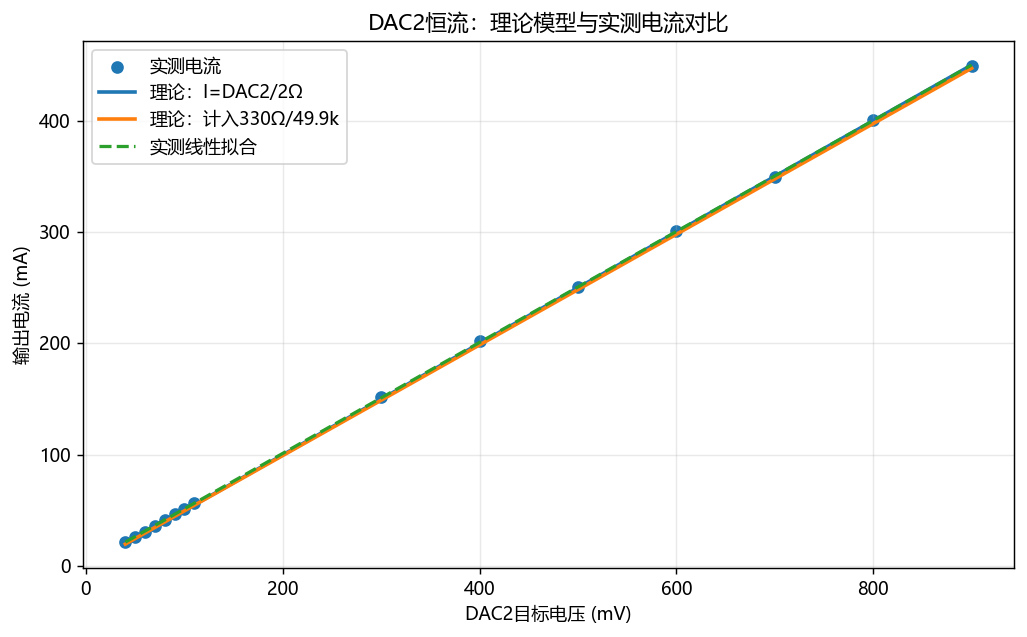
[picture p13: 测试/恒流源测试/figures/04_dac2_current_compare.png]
DAC2理论对比


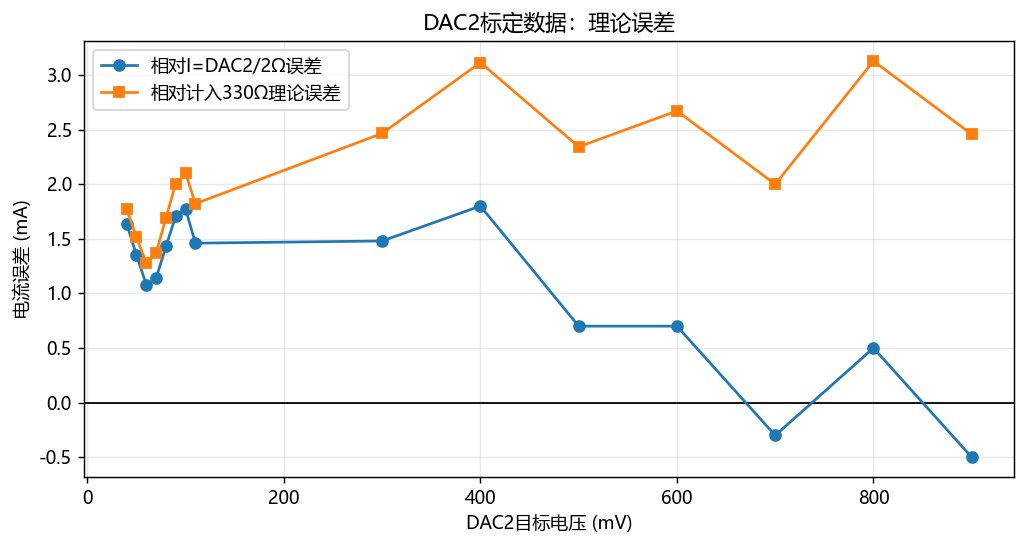
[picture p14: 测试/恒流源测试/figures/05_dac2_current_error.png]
DAC2误差


DAC2 标定数据摘要：

| DAC2目标(mV) | DAC2实测(mV) | 理论电流(mA) | 实测电流(mA) | 误差(mA) |
| --- | --- | --- | --- | --- |
| 900 | | 450.00 | 449.50 | -0.50 |
| 800 | | 400.00 | 400.50 | 0.50 |
| 700 | | 350.00 | 349.70 | -0.30 |
| 600 | | 300.00 | 300.70 | 0.70 |
| 500 | | 250.00 | 250.70 | 0.70 |
| 400 | | 200.00 | 201.80 | 1.80 |
| 300 | | 150.00 | 151.48 | 1.48 |
| 110 | 113.65 | 55.00 | 56.46 | 1.46 |
| 100 | 104.20 | 50.00 | 51.77 | 1.77 |
| 90 | 94.00 | 45.00 | 46.71 | 1.71 |
| 80 | 83.38 | 40.00 | 41.43 | 1.43 |
| 70 | 72.74 | 35.00 | 36.14 | 1.14 |
| 60 | 62.55 | 30.00 | 31.08 | 1.08 |
| 50 | 53.03 | 25.00 | 26.35 | 1.35 |
| 40 | 43.53 | 20.00 | 21.64 | 1.64 |

结论：DAC2 到输出电流的线性很好，但存在正偏差。相对于 `I=DAC2/2Ω` 的简单理论，平均绝对误差约 `1.171mA`，最大约 `1.800mA`。这说明主要问题不是非线性，而是零点/比例系数/采样链路存在系统偏置。

从硬件角度看，偏高可能来自以下几类来源：

- `Rsense` 实际值小于标称 `2Ω`，同样的采样电压会对应更大的真实电流；
- DAC2 输出或运放输入端存在正向零点偏移；
- 运放输入失调被直接等效成采样电阻上的电压误差，例如 `10mV` 失调在 `2Ω` 上就是 `5mA`；
- MCU/串口打印中的电流计算使用了理想 `2Ω`，但实际采样电阻、ADC基准或增益没有校准；
- 采样地 `AGND/ADC_REF_GND/GND` 回流导致毫伏级地电位差，这在 `2Ω` 采样上会直接变成毫安级电流误差。

目前偏差量级约 `5~9mA`，折算成采样电阻电压约 `10~18mV`，这个量级很像零点、地线压降、运放失调叠加后的系统误差。

## 5. 输出电压采样公式

原理图中 `VOUT+` 与 `VOUT-` 均通过 `330kΩ/33kΩ` 分压进入 ADC，并在 ADC 前串 `1kΩ`、并 `22nF` 做低通滤波。理想分压比为：

```text
Vadc = Vin * 33k / (330k + 33k) = Vin / 11
Vin = 11 * Vadc
```

因此负载两端电压可由差分方式重构：

```text
Vload = 11 * (ADC_VOUT+ - ADC_VOUT-)
```

串口日志中 `Vload` 与 `VOUT_P - VOUT_N` 基本一致，说明这条采样链路的公式方向是正确的。这里采用高阻分压，优点是损耗小；缺点是 ADC 输入源阻抗较高，因此 `1k + 22nF` 滤波、电容漏电、ADC采样时间都会影响精度。若后续追求更高精度，建议检查 ADC 采样周期是否足够长。

## 6. 串口日志恒流点与重复性

右侧串口日志解析出 18 条完整记录，每个电流档重复 3 次。统计如下：

| DAC2目标(mV) | 理论电流(mA) | 实测均值(mA) | 标准差(mA) | 平均误差(mA) | 最小VMOS(mV) |
| --- | --- | --- | --- | --- | --- |
| 400 | 200.0 | 205.509 | 0.077 | 5.509 | 5451 |
| 500 | 250.0 | 255.474 | 0.215 | 5.474 | 2166 |
| 600 | 300.0 | 306.173 | 0.308 | 6.173 | 1936 |
| 700 | 350.0 | 356.041 | 0.244 | 6.041 | 1846 |
| 800 | 400.0 | 408.728 | 0.350 | 8.728 | 1615 |
| 900 | 450.0 | 458.633 | 0.379 | 8.633 | 125 |

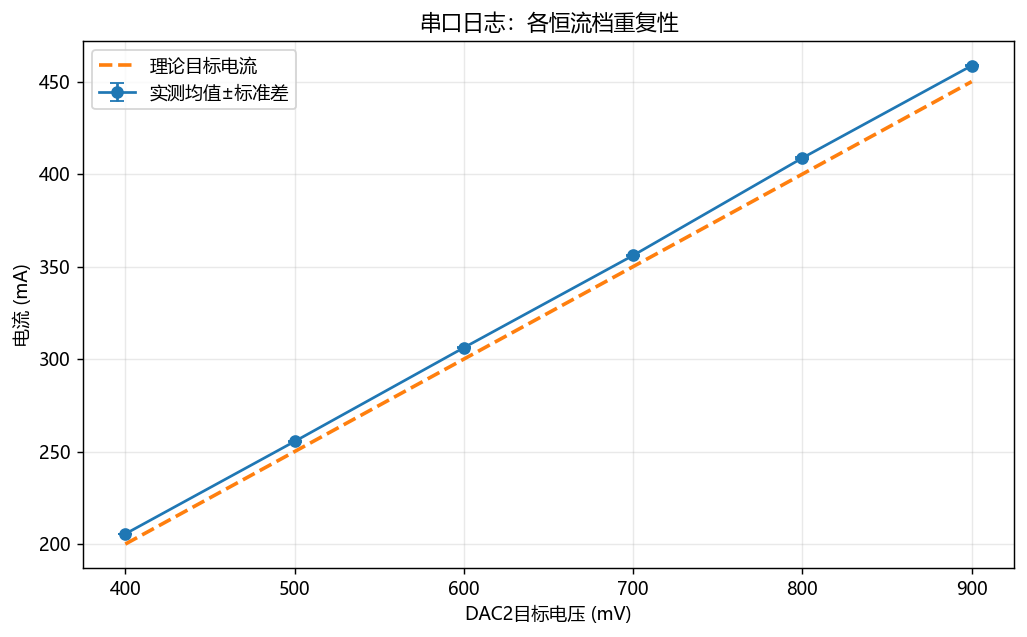
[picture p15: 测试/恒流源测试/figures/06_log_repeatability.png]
重复性


重复性很好：各档最大标准差约 `0.379mA`。这说明闭环在这些测试点下较稳定，误差主要表现为系统偏高，而不是随机抖动。

## 7. 压差余量分析

恒流环需要 MOS/调整级保留足够压差，否则运放即使继续驱动，也无法让采样电阻电压继续升高。串口日志中的 `VMOS` 可作为压差余量观察量。

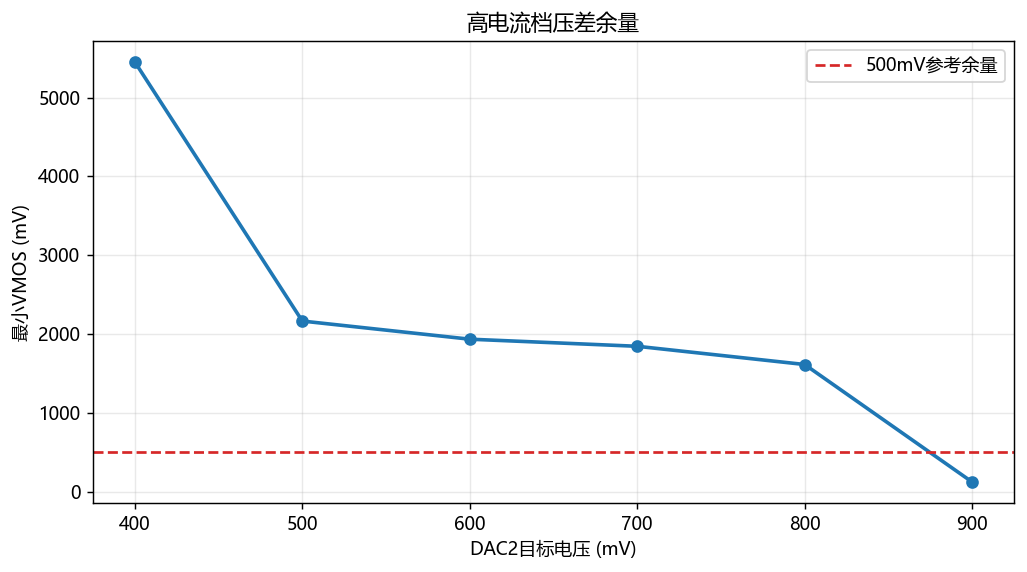
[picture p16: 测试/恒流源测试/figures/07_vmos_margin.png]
VMOS压差余量


在 `DAC2_Target = 900mV` 档：

```text
理论电流 ≈ 450mA
实测电流 ≈ 458.6mA
最小VMOS ≈ 125mV
```

这个压差已经很低，说明该负载约 `46Ω`、电流约 `459mA` 时接近调节边界。如果继续提高电流、提高负载阻值，或输入电压下降，恒流环可能进入饱和，表现为电流上不去、误差变大或波动增加。

从硬件能量路径看，负载电压约为：

```text
Vload ≈ Iout * Rload
```

调整级需要的余量近似为：

```text
VOUT+ >= Vload + VMOS_min + Vsense + 走线/器件余量
```

其中 `Vsense = Iout * Rsense`。当 `Rload≈46Ω`、`Iout≈459mA` 时，仅负载就需要约 `21.1V`，采样电阻还需要约 `0.918V`，再加上 MOS 调整余量，BUCK 输出必须足够高。现在测到的 `VMOS` 最低约 `125mV`，说明 DAC1 对应的 BUCK 输出电压已经贴近需求下限。

## 8. 综合判断

1. **可调 BUCK 的理论模型成立。** FB 求和方程给出的斜率为 `-10`，Sheet1 实测为 `-10.0105`，反推 FB 参考约 `0.7564V`。
2. **DAC1 调压链路线性极好。** `VOUT+` 与 `DAC1_actual` 的 R² 为 `0.99999995`，最大拟合残差仅 `0.000898V`。
3. **DAC2 恒流链路线性好但整体偏高。** 实测斜率 `0.498058mA/mV` 接近理论 `0.5mA/mV`，但截距约 `1.685mA`，实际电流普遍偏高。
4. **重复性优于绝对精度。** 同档三次重复标准差小于 `0.4mA`，说明可以通过软件标定显著改善绝对误差。
5. **高电流档受压差余量限制。** `900mV` 档最小 `VMOS` 只有约 `125mV`，建议提高 DAC1 电压余量或限制该负载下的最大恒流设定。

整体来看，这版硬件已经具备比较好的基础：电压调节链路线性非常好，恒流环重复性也好，说明原理设计方向成立。当前更像是“还没完成精密校准”和“高电流档余量需要管理”的阶段，而不是拓扑错误。

## 8.1 已获得与待补充的标定关系

本次测试已经确认或正在建立的关系如下：

1. `DAC1_Target` 与 `DAC1_actual` 的对应关系已经获得。当前数据中 DAC1 实测误差最大约 `0.900mV`，可以认为 DAC1 输出本身线性和一致性较好。
2. `DAC1_actual` 与 `VOUT+` 的标定公式已经获得：

```text
VOUT ≈ 0.010012879 * DAC1_actual(mV) - 1.797554
```

也可写成：

```text
VOUT ≈ 10.012879 * DAC1_actual(V) - 1.797554
```

3. `V_SENSE` 采样值换算出的电流与电流表实测电流之间，还需要进一步做线性校准。建议后续按以下形式拟合：

```text
I_meter = k_sense * I_sense_adc + b_sense
```

其中：

```text
I_sense_adc = V_SENSE / Rsense
```

如果 `Rsense = 2Ω`，则理想情况下：

```text
I_sense_adc(mA) = V_SENSE(mV) / 2
```

实测后用于固件补偿的形式可以写成：

```text
I_calibrated = k_sense * (V_SENSE / Rsense) + b_sense
```

或者反向求目标采样电压：

```text
V_SENSE_target = Rsense * (I_target - b_sense) / k_sense
```

这一项目前“公式形式已确定，系数还未最终计算”，需要下一组 `V_SENSE` 与电流表同步数据来完成。

## 9. 下一步测试建议

建议下一轮测试按“先拆链路，后闭环整机”的顺序做。

### 9.1 静态硬件参数复测

- 用四线法测量采样电阻实际值，记录温度下的阻值变化；
- 单独测 `DAC_CH1/DAC_CH2` 输出电压，覆盖低端、中点、高端，得到 DAC 零点和增益误差；
- 测 `OPA197` 恒流环输入两端电压差，确认稳定恒流时 `V+` 与 `V-` 的误差量级；
- 测 `AGND`、`ADC_REF_GND`、功率 `GND` 在不同电流下的电位差，判断地线压降是否进入采样链路；
- 核对 `330k/33k` 分压电阻实际值，计算 ADC 电压采样比例误差。

### 9.2 DAC1 电压余量测试

- 固定负载和恒流目标，扫 DAC1，记录 `VOUT+、Vload、VMOS、Iout`；
- 找出每个电流档刚好失去恒流的 DAC1 临界点；
- 建立软件中的最小输出电压策略，例如：

```text
VOUT_set >= I_target * Rload_est + I_target * Rsense + VMOS_margin
```

其中 `VMOS_margin` 建议先取 `0.5~1.0V` 做保守验证。

### 9.3 DAC2 恒流校准测试

- 在足够压差余量下测试 DAC2，例如每 `50mV` 或 `100mV` 测一点；
- 每个点至少记录 5 次，计算均值、标准差和温升后的漂移；
- 拟合一次线性校准：

```text
I_actual = k * DAC2 + b
DAC2_corrected = (I_target - b) / k
```

- 若残差出现弯曲，再考虑二次校准或分段线性校准。

### 9.4 动态与热测试

- 做负载阶跃测试，观察恒流恢复时间、过冲和振荡；
- 在 100mA、300mA、450mA 等档位各持续运行 10~30 分钟，记录电流漂移、MOS温度、采样电阻温度；
- 测输入电压从低到高变化时的电流保持能力，确认实际输入范围；
- 对最高功率点进行热成像或点温测试，重点看 MOS、采样电阻、BUCK电感和二极管。

### 9.5 本次测试注意事项

- 输入电源的限流建议设置为 `0.5A`。如果电源限流过低，系统从 CV 状态切换到 CC 状态时，输入电源可能进入限流，导致板上 `5V` 与 `3V3` 掉电波动，进而引发单片机复位。
- 本次使用的电位器/负载在约 `450mA`、`45Ω` 条件下已经接近或超过承受能力，出现发热烧毁风险。因此本次没有继续测 `500mA`。后续如需测试 `500mA` 档，应更换功率足够的负载，或调小负载电阻并重新核算功耗。
- 负载功耗按下式估算：

```text
Pload = I^2 * Rload
```

以 `450mA`、`45Ω` 为例：

```text
Pload = 0.45^2 * 45 ≈ 9.1W
```

因此普通小功率电位器不适合直接承受该测试点，建议使用大功率电阻、电子负载或多电阻并联分摊功耗。

## 10. 当前整体分析与建议

- 软件中对 DAC2 做一次线性校准，初步可用实测拟合反解：

```text
DAC2_Target_corrected = (I_target - 1.685285) / 0.498058
```

- 对 DAC1 输出电压也可保留拟合式用于预设电压余量：

```text
VOUT ≈ 0.010012879 * DAC1_actual(mV) -1.797554
```

- 高电流/高负载电压时，确保 `VMOS` 至少保留数百 mV，工程上建议先按 `>=500mV` 作为报警线，再结合实测温升和动态响应决定最终阈值。
- 复测采样电阻实际阻值、OPA197输入失调、DAC2零点、ADC换算系数，优先排查造成 `+5~9mA` 系统偏差的来源。
- 完成 `V_SENSE` 采样电流与电流表实测电流的线性校准后，应优先在固件中使用校准后的 `I_calibrated` 作为显示值和保护判断值。

对当前版本的总体评价：

- **原理可行性：通过。** 电压环和恒流环的实测趋势与原理公式一致；
- **线性：较好。** DAC1、DAC2 的拟合 R² 都非常高；
- **重复性：较好。** 恒流点三次重复标准差小，适合做软件标定；
- **绝对精度：需要校准。** 当前电流整体偏高，必须补偿零点和增益；
- **高功率余量：需要优化。** 900mV 档 `VMOS` 过低，应提高 BUCK 设定或限制该工作点；
- **下一版重点：采样链路和地线。** 毫伏级误差会直接变成毫安级电流误差，PCB回流和ADC参考地需要重点检查。

## 对于本报告的分析：

1. DAC1/Buck 线性很好，DAC1 预设公式可用。
2. DAC2→I_meas 线性很好，适合一次线性校准。
3. 串口重复性不错，说明显示波动不是主要矛盾；主要是显示偏差要校准。
4. 高电流+高负载下 VMOS 会塌，必须管理 Buck 余量。
5. 高电流测试时负载功率很大，不能用普通电位器硬扛。

##### 存疑结论：

1. “实测均值偏高 5~9mA”——要改名为 I_serial_avg 偏高，而不是 I_meas 偏高。
2. “偏差像运放失调/地线压降”——目前证据不够，优先怀疑 ADC显示链校准。
3. “下一步测试建议”全部做——太散，只取其中与 I_meas、I_serial、VOUTP/N 相关的部分。

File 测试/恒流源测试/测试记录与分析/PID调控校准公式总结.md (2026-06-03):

# 校准与可选 PI 调控公式汇总

> 来源：`测试数据01分析.md`、`测试数据02分析.md`。
> 若 01、02 公式不同，以 `测试数据02分析.md` 为准。

## 0. 软件实现优先级建议

建议按以下顺序实现：

```text
1. 电流前馈校准：I_set -> DAC2_cmd
2. 电流显示/反馈校准：I_serial -> I_disp / I_feedback
3. 显示滤波与 I_fast 快速保护量
4. VOUT+ / VOUT- 校准与 Rload 显示
5. 过流、短路、开路保护逻辑
6. BUCK 前馈公式：VOUTP_target -> DAC1_cmd
7. 可选 PI 慢速修正：只修正剩余小误差
```

## 1. DAC2命令值 -> 实际输出电流

```text
I_meas_mA = 0.498188 * DAC2_cmd_mV + 1.368386
```

用途：根据 DAC2 命令值估算实际输出电流。

反算用于电流设定前馈：

```text
DAC2_cmd_mV = (I_set_mA - 1.368386) / 0.498188
```

用途：作为电流设定的前馈校准公式，先给 DAC2 一个接近目标电流的命令值。

## 2. DAC2实测电压 -> 实际输出电流

```text
I_meas_mA = 0.497253 * DAC2_meas_mV - 0.029041
```

用途：验证 DAC2 实际输出电压与恒流环输出电流是否一致。`DAC2_meas` 是万用表测 DAC_CH2 测试点得到的实测电压。

理论公式：

```text
Vref_i = VDAC2 * 49.9k / (49.9k + 330)
Iout = Vref_i / Rsense
```

若 `Rsense = 2Ω`：

```text
Iout_mA = 0.496715 * DAC2_meas_mV
```

用途：作为 DAC2 恒流链路的理论基准。此项主要用于排故，不是固件主控制公式；固件主控制优先使用第 1 节的 `DAC2_cmd -> I_meas`。

## 3. 串口/ADC电流显示校准

```text
I_feedback_mA = 0.980222 * I_serial_mA + 0.023329
```

用途：把 MCU 原始换算电流校准为更接近电流表的反馈电流。该值可作为：

```text
I_disp：最终显示电流
I_feedback：可选 PI 慢速修正的反馈量
```

建议后续代码里统一保留 `I_disp` 作为给用户看的显示值；若用于 PI，可在内部等价使用 `I_feedback`。

## 4. VOUT+ 显示校准

```text
VOUTP_cal = 0.985864 * VOUTP_serial + 0.001825
```

用途：校准 VOUT+ 显示值，用于后续计算负载电压、负载电阻和 BUCK 余量。

## 5. VOUT- 显示校准

```text
VOUTN_cal = 0.998639 * VOUTN_serial - 0.026753
```

用途：校准 VOUT- 显示值，用于计算 MOS 压差和负载电压。

## 6. 负载电压

```text
Vload = VOUTP_cal - VOUTN_cal
```

用途：计算负载两端真实电压。

## 7. MOS压差余量

```text
Vsense_cal_V = I_feedback * Rsense
VMOS = VOUTN_cal - Vsense_cal_V
```

用途：判断恒流环是否有足够压差余量。`VMOS` 太低时，恒流环可能进入饱和。

建议初步判断：

```text
VMOS < 0.5V：余量不足，建议提高 BUCK 或报警
VMOS 约 1.0V ~ 1.6V：较合适
VMOS 太大：MOS 功耗增加，需要降低 BUCK
```

## 8. 负载电阻估算

```text
Rload_est = Vload / I_feedback_A
```

用途：估算当前负载阻值，用于计算 BUCK 需要提供的输出电压。

注意低电流保护：

```text
I < 5mA：Rload 显示 --
5~10mA：可显示但强滤波
I ≥ 10mA：正常显示
```

原因：低电流时分母太小，轻微 ADC 波动会导致 Rload 显示明显跳变。

## 9. BUCK输出目标电压

```text
VOUTP_target = I_set_A * Rload_est + I_set_A * Rsense + VMOS_margin
```

当前建议：

```text
Rsense = 2Ω
VMOS_margin = 1.2~1.5V，可根据温升和恒流稳定性调整
```

用途：根据目标电流、负载阻值和 MOS 余量，计算 DAC1/BUCK 应该给出的 VOUT+。

## 10. DAC1命令值反算

测试拟合关系为：

```text
VOUT+ = 10.012879 * DAC1_actual_V - 1.797554
```

软件实际控制的是 `DAC1_cmd`，不是万用表测得的 `DAC1_actual`。由于当前 DAC1 误差较小，可先近似认为：

```text
DAC1_actual ≈ DAC1_cmd
```

反算：

```text
DAC1_cmd_V = (VOUTP_target + 1.797554) / 10.012879
```

用途：根据目标 BUCK 输出电压，反算 DAC1 应输出的控制电压。

建议加限幅：

```text
DAC1_cmd_V 限制在实际可用范围内，例如 0V ~ 3.3V
VOUT+_target 也应限制在 BUCK 和输入电源允许范围内（2V~28V）
```

## 11. ADC原始电压换算

```text
Vadc_mV = ADC_raw * 3300 / 4095
```

VOUT 分压为 `330k/33k`，比例约为 11：

```text
VOUT_mV = Vadc_mV * 11
```

用途：把 ADC 原始值换算为 VOUT+ / VOUT- 电压。

注意：这是理想换算，最终用于显示和计算时应再进入第 4、5 节的 VOUT 校准公式。

## 12. Vsense电流原始换算

```text
I_serial_mA = Vsense_mV / Rsense_ohm
```

若 `Rsense = 2Ω`：

```text
I_serial_mA = Vsense_mV / 2
```

用途：由采样电阻电压换算 MCU 原始电流显示值，再进入第 3 节电流显示校准公式。

建议区分：

```text
I_serial：原始换算电流
I_disp：校准 + 滤波后的显示电流
I_fast：短平均、少滤波后的保护用电流
```

## 13. PI 慢速修正核心公式

前馈：

```text
DAC2_ff_mV = (I_set_mA - 1.368386) / 0.498188
```

反馈：

```text
I_feedback_mA = 0.980222 * I_serial_mA + 0.023329
```

误差：

```text
error_mA = I_set_mA - I_feedback_mA
```

最终 DAC2 输出：

```text
DAC2_cmd_mV = DAC2_ff_mV + PI_trim_mV
```

其中：

```text
PI_trim_mV = PI(error_mA)
```

注意：

```text
1. PI_trim 的单位必须是 mV。
2. 建议先不加 D 项，避免放大 ADC 噪声。
3. PI 更新周期建议 100ms ~ 500ms。
4. PI_trim 必须限幅，例如 -10mV ~ +10mV。
5. 调试初期可直接令 PI_trim = 0，只使用前馈校准。
```

用途：用标定前馈快速接近目标，再由 PI 慢速修正剩余误差。此项是可选增强，不是当前第一优先级。

## 14. 电流纹波换算

```text
I_ripple_pp = Vpp / Rsense
```

若 `Rsense = 2Ω`：

```text
I_ripple_pp_mA = Vpp_mV / 2
```

用途：由采样电阻上的纹波电压换算输出电流纹波。

注意：普通示波器探头长地线容易引入开关噪声，重测纹波时应使用短地弹簧、AC 耦合、20MHz 限带，并先测噪声底。

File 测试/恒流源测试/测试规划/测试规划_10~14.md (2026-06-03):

# 建议、测试计划与思路整理

## 命名规范

为了避免越说越晕，提议我们约定一下命名规范，不能什么都叫“实际值”，比如按下表

| 名字 | 含义 | 来源 | 用途 |
| --- | --- | --- | --- |
| `I_set` | 用户设定电流 | 编码器/按键/程序 | 用户目标 |
| `DAC2_cmd` | 软件最终给 DAC2 的命令电压 | 校准公式算出 | 控制恒流目标 |
| `I_meas` | 电流表实测电流 | 外部电流表 | 校准真值、验收真值 |
| `ADC_VSENSE_raw` | ADC 原始采样码 | STM32 ADC | 校准底层数据 |
| `I_serial` | 目前串口未经最终校准/滤波的电流显示 | 软件旧公式 | 临时观察，最后被 `I_disp`替代  |
| `I_disp` | 最终成品上的显示电流 | 校准+滤波后 | LCD/串口显示、用户看到的实际电流 |
| `I_fast` | 快速保护用电流 | 短平均、少滤波 | 过流保护 |
| `VOUTP_meas` | 万用表测 VOUT+ | 万用表 | 校准/验证 |
| `VOUTN_meas` | 万用表测 VOUT- | 万用表 | 计算 Vload、Vmos |
| `VOUTP_adc / VOUTN_adc` | MCU 根据 ADC 算出的 VOUT+/VOUT- | ADC | 软件计算 |
| `Rload_disp` | 显示负载电阻 | 软件计算+滤波 | 发挥项显示 |
| `Vmos` | MOS 两端电压 | `VOUT- - Vsense`或万用表直接测 | Buck 外环、热安全 |

## 系统思路整理

### 1.电流控制主链：

`I_set → DAC2_cmd → 模拟恒流环 → I_meas`

解释：利用I_set和I_meas的数据，拟合出软件校准公式①，修正原本的 `I_set*2=DAC2_cmd` 公式，使 `I_set=I_meas`

### 2.电流显示链：

重要性：直接影响显示电流的精度；且因为这个数据作为pid的目标值，故间接影响输出电流的精度

`ADC_VSENSE_raw → I_serial → 校准公式② → 滤波 → I_disp`

解释：利用I_serial和I_meas的数据，拟合出软件校准公式②，修正原本的 `ADC_Vsense_raw /2 =I_disp` 公式，使 `I_disp=I_meas`

### 3.PID/PI ：

* 为了不影响硬件内环、不引入抖动，pid需要慢速调控DAC2
* 先做PI就够
* 一个思路

  ```
  每 100ms~500ms：
  error = I_set - I_disp
  如果误差持续存在：
  DAC2_cmd += 很小的修正量
  ```

## 三大保护逻辑

### 1.过流保护

看 I_disp 超过 550 就关 Buck EN

AI建议：不要用很慢的显示滤波值，而用 `I_fast`（短平均后的电流），这样既避免毛刺误触发，也不会保护太慢。

### 2.短路保护

注意：题目里的短路保护不是“短路就立刻断电”，而是“输出端短路时，自动限制输出电流为设定值，不损坏设备”

也就是0Ω时系统仍要正常运行，关键在于可调buck（mos）

0Ω/0500mA/Vmos留1V余量——则VOUT+需要1~2V——理论上可行，但我们没测过能否做到这一点

### 3.开路保护

开路时不要用 `Rload = V/I` 去判断，因为 I≈0，R会溢出或变成巨大数

AI建议方案：

```
如果 I_set > 某个阈值，比如 10mA
但 I_disp 长时间 < I_set 的 10% 或 < 5mA
同时 VOUT+ 已经升到较高值 / Buck 已经给到上限
则判断开路
```

或更简单的初版：

```
I_set > 20mA
且 I_disp < 2mA
持续 500ms
→ 开路报警
```

## 电流纹波问题（目标是0.2mA内）

这个到时候不知道怎么测评，示波器电流探头吗？

我们用万用表的话可以观察到0.01mA档的跳变（总体在0.1mA以内吧），但AI说明：万用表 0.01mA 档跳动小，不等于纹波 ≤0.2mA。万用表显示的是低速平均/有效值，可能看不到高频纹波。

AI建议：

```
用示波器电压探头测 Rs 两端电压纹波
AC耦合
尽量短地线
带宽限制打开，比如 20MHz
测 Vpp
I_ripple ≈ V_ripple / 2Ω
```

## 负载变化时电流变化 < 1%

等滑动变阻器到了再测吧？

## 【建议】Rload 显示方案（当前优先级不高）

题目只是说“可测量并显示负载电阻值”，没有给很严格的精度。所以我们不用显示到小数点后三位。

AI的精度建议：

```markdown
0~10Ω：显示 0.1Ω
10~50Ω：显示 0.5Ω 或 1Ω
低电流时：Rload 不更新或显示“--”
```

因为低电流时，`I_disp` 在分母，轻微波动会把 Rload 放大得很明显。

处理方式：

```
VOUT+ / VOUT-：做 ADC 校准 + 中等滤波
I_disp：用校准后电流
Rload_disp：强滤波 + 显示死区
```

## 后续测试需要

### 1.VOUT+能否稳定输出1~2V？

### 2.电流主链路与显示链路还有VOUT+-的校准数据

记录：

```
I_set_mA              用户设定电流
DAC2_cmd_mV           软件给 DAC2 的目标电压
I_meas_mA             电流表实测实际电流
I_serial_mA           串口当前显示/计算的电流
Vsense_serial_mV      串口显示的 Vsense
ADC_VSENSE_raw        ADC原始值，能输出就记

VOUTP_meas_V          万用表测 VOUT+
VOUTN_meas_V          万用表测 VOUT-
VOUTP_serial_V        串口显示 VOUT+
VOUTN_serial_V        串口显示 VOUT-

Rload_nominal_Ω       负载标称值，比如45Ω
```

推荐测点：

```
负载先固定 45Ω：0mA
10mA
50mA
100mA
200mA
300mA
400mA
450mA
```

如果 45Ω 下高电流余量不够，再补一组较小负载：

```
负载 25Ω 或 10Ω：
100mA
300mA
500mA
```

每个点稳定后记录一次即可；但串口值如果会跳，就同一条件下连续记 3 组

### 4.用于串口滤波的数据

不能再随机取三组了

AI建议：可以固定三个电流情况（比如50、250、500）然后连续记录30组 I_serial和30组 Vsense_serial

用于：

```
决定 ADC平均次数
决定 EMA alpha
判断是否有偶发跳点
决定显示死区
```

### 5.电流纹波测试（感觉也得排到下次）

```
示波器测 2Ω 采样电阻两端纹波
I_set = 50mA、250mA、500mA
负载 = 典型负载，比如 25Ω/45Ω
记录 Vsense_ripple Vpp
换算 I_ripple = Vpp / 2Ω
```

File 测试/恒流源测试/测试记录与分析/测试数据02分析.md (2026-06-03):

# 恒流源测试数据02分析报告

## 1. 数据来源与总体判断

本次分析基于 `测试记录/测试数据02.xlsx`，主要包含三类数据：

- 综合校准表：`0~500mA` 的设定电流、实测电流、DAC2 命令值、DAC2 实测值、串口显示电流、VOUT+ / VOUT- 显示与实测；
- 连续串口数据：约 `50mA`、`250mA`、`500mA` 三档的连续打印数据；
- 纹波表：目前只记录了 `50mA` 档的示波器读数。

总判断是：**电流控制主链路已经基本可用，模拟恒流内环线性非常好；后续重点应放在 DAC2 命令校准、电流显示校准、VOUT± 显示校准、BUCK 压差余量管理和纹波测量方法。**

所有图像由 `测试分析/generate_test_data02_figures.py` 使用 `D:\envs\torch_env\python.exe` 生成，输出到 `../figures` 目录。

## 2. 设定电流到实测电流

综合校准表中，设定电流 `I_set` 与电流表实测电流 `I_meas` 的线性拟合为：

```text
I_meas_mA = 0.994172 * I_set_mA + 0.259333
R² = 0.99999586
RMSE = 0.340 mA
最大拟合残差 = 1.071 mA
```

若去掉 `0mA` 点后再拟合：

```text
I_meas_mA = 0.994738 * I_set_mA + 0.067706
R² = 0.99999900
RMSE = 0.165 mA
最大拟合残差 = 0.345 mA
```

设定电流与实测电流

误差统计如下：

```text
平均绝对误差 = 1.075 mA
最大绝对误差：I_set = 500mA, I_meas = 497.5mA, 误差 = -2.5mA, 相对误差 = -0.5%
去掉0mA后最大相对误差：I_set = 20mA, I_meas = 20.19mA, 相对误差 = 0.95%
```

电流设定误差

结论：高电流段已经贴近题目常见的 `±0.5%` 边界，`500mA` 点刚好为 `-0.5%`。低电流段相对误差看起来偏大，但绝对误差只有 `0.1~0.4mA` 量级，主要受零点偏置、仪表分辨率和低电流测量噪声影响。

## 3. DAC2 命令值到输出电流的校准公式

综合表中 `DAC2_cmd` 是固件给 DAC2 的命令电压，`I_meas` 是电流表实测电流。拟合结果为：

```text
I_meas_mA = 0.498188 * DAC2_cmd_mV + 1.368386
R² = 0.99999534
RMSE = 0.361 mA
最大拟合残差 = 0.848 mA
```

DAC2命令值到输出电流

因此固件中可以把目标电流反算为 DAC2 命令值：

```c
DAC2_cmd_mV = (I_set_mA - 1.3684f) / 0.49819f;
```

这个公式比直接使用理想关系更贴合当前硬件和软件输出链路。需要注意的是，`0mA` 点实测仍有约 `1.33mA`，如果比赛指标特别看重低电流，建议单独补测 `0mA、5mA、10mA、20mA` 并做低电流段校准或零点扣除。

## 4. DAC2 实测电压到输出电流

本次数据补充了 `DAC2_mea_mV`，它比 `DAC2_cmd` 更能直接反映模拟恒流环的输入参考。拟合结果为：

```text
I_meas_mA = 0.497253 * DAC2_mea_mV - 0.029041
R² = 0.99999994
RMSE = 0.041 mA
最大拟合残差 = 0.090 mA
```

DAC2实测电压到输出电流

理论上，DAC2 经 `330Ω` 串联电阻和 `49.9kΩ` 到地电阻后送入运放正输入端：

```text
Vref_i = VDAC2 * 49.9k / (49.9k + 330)
Iout = Vref_i / Rsense
```

若 `Rsense = 2Ω`，则：

```text
Iout_mA = VDAC2_mV * 0.993430 / 2
Iout_mA ≈ 0.496715 * VDAC2_mV
```

实测斜率 `0.497253mA/mV` 与理论 `0.496715mA/mV` 非常接近。这说明：**只要 DAC2 的实际输出电压确定，运放 + MOS + 采样电阻这条模拟恒流内环非常线性。** 当前误差更多来自 `DAC2_cmd -> DAC2_meas` 的输出误差，以及串口/ADC 显示链路的换算误差。

## 5. 电流串口显示校准

串口显示电流 `I_serial` 相比电流表实测值整体偏高。拟合结果为：

```text
I_meas_mA = 0.980222 * I_serial_mA + 0.023329
R² = 0.99999018
RMSE = 0.524 mA
最大拟合残差 = 1.105 mA
```

去掉 `0mA` 点：

```text
I_meas_mA = 0.980490 * I_serial_mA - 0.069168
R² = 0.99999003
RMSE = 0.521 mA
```

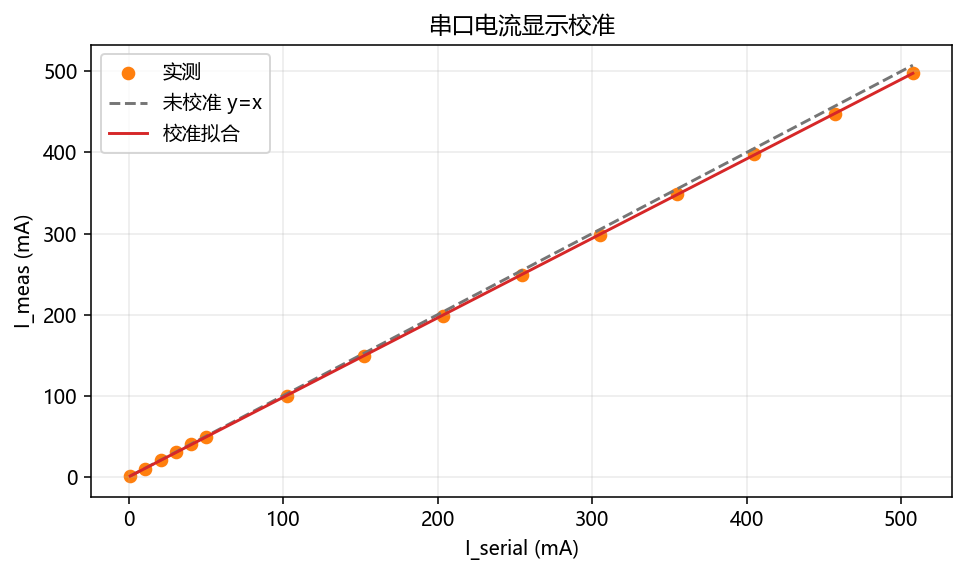
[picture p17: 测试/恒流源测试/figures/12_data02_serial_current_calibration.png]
串口电流显示校准


可以先使用全量数据拟合式做显示校准：

```c
I_disp_mA = 0.98022f * I_serial_mA + 0.023f;
```

例如 `500mA` 点：

```text
I_serial = 507.667mA
校准后 I_disp ≈ 497.65mA
电流表 I_meas = 497.5mA
```

结论：电流显示偏高不是随机波动，而是比例系数偏差。加入这条一次校准后，串口/OLED 显示会明显贴近电流表。

## 6. VOUT+ / VOUT- 显示校准

VOUT 显示链路的拟合结果如下：

```text
VOUTP_meas_V = 0.985864 * VOUTP_serial_V + 0.001825
R² = 0.99998807
RMSE = 0.0284 V
最大拟合残差 = 0.0616 V
```

```text
VOUTN_meas_V = 0.998639 * VOUTN_serial_V - 0.026753
R² = 0.99940035
RMSE = 0.0128 V
最大拟合残差 = 0.0312 V
```

VOUT串口显示校准

从原始显示误差看：

```text
VOUT+ 串口显示最大原始误差 ≈ 0.376 V
VOUT- 串口显示最大原始误差 ≈ 0.062 V
```

建议固件中先按下式修正显示值，再计算 `Vload`、`Rload` 和 `VMOS`：

```c
VOUTP_cal = 0.985864f * VOUTP_serial + 0.001825f;
VOUTN_cal = 0.998639f * VOUTN_serial - 0.026753f;
```

如果不校准 VOUT+，负载电阻和 MOS 压差的显示都会被 VOUT+ 偏高带偏。

## 7. 压差余量与 DAC1 设置

串口日志中的压差定义可按以下关系理解：

```text
VMOS = VOUT_N - Vsense
Vsense ≈ Iout * Rsense
Vload = VOUT_P - VOUT_N
```

综合表用 `VOUTN_meas - Vsense_serial` 估算主表压差，结果如下：

主表压差余量估算

关键点为：

| I_set(mA) | I_meas(mA) | VOUTN_meas(V) | Vsense_serial(mV) | VMOS估算(V) |
| --- | --- | --- | --- | --- |
| 250 | 248.56 | 2.426 | 505 | 1.921 |
| 300 | 298.40 | 1.222 | 606 | 0.616 |
| 350 | 348.20 | 1.076 | 705 | 0.371 |
| 400 | 398.00 | 0.985 | 807 | 0.178 |
| 450 | 447.90 | 1.087 | 909 | 0.178 |
| 500 | 497.50 | 2.913 | 1011 | 1.902 |

`300~450mA` 的 `VMOS` 明显偏低，尤其 `400mA`、`450mA` 只有约 `0.18V`。这不是 MOS 发热导致的压差下降，而是 BUCK 输出电压余量给低了。

以 `450mA`、约 `49.6Ω` 负载为例：

```text
负载电压 ≈ 0.4479A * 49.6Ω ≈ 22.22V
Vsense ≈ 0.909V
若希望 VMOS ≈ 2V，则 VOUT+ 目标应约为：
VOUT+ ≈ Vload + Vsense + VMOS ≈ 22.22 + 0.909 + 2.0 = 25.13V
```

而表中实测：

```text
VOUT+ = 23.417V
VOUT_N = 1.087V
Vsense = 0.909V
VMOS ≈ 0.178V
```

这说明 `300~450mA` 那几行 DAC1 / BUCK 输出目标很可能仍按较低负载电压估算，切到约 `49.6Ω` 负载后余量不够。`500mA` 点 VOUT+ 提高到 `27.724V`，VMOS 又回到约 `1.90V`，也印证了这一点。

建议 DAC1 / BUCK 输出目标按下式估算：

```text
VOUTP_target = I_set * Rload_est + I_set * Rsense + VMOS_margin
```

其中：

```text
Rload_est：建议使用校准后的 Vload/Iout 得到
Rsense：约 2Ω
VMOS_margin：建议初版取 1.5~2.0V
```

## 8. 连续串口数据稳定性

`Sheet1` 中三段连续串口数据分别对应约 `50mA`、`250mA`、`500mA`。解析统计如下：

| I_set(mA) | 样本数 | I_actual均值(mA) | I_actual标准差(mA) | Vsense均值(mV) | Vsense标准差(mV) | RLOAD均值(Ω) | RLOAD标准差(Ω) | VMOS均值(mV) |
| --- | ---: | ---: | ---: | ---: | ---: | ---: | ---: | ---: |
| 50 | 29 | 51.023 | 0.447 | 97.793 | 0.412 | 50.161 | 0.537 | 1920.4 |
| 250 | 30 | 252.685 | 0.377 | 501.900 | 0.305 | 49.759 | 0.097 | 2346.5 |
| 500 | 31 | 506.804 | 0.301 | 1009.742 | 0.514 | 49.631 | 0.039 | 1924.4 |

连续串口数据稳定性

连续串口负载电阻显示稳定性

结论：

- 电流显示重复性不错，三档标准差都小于 `0.5mA`；
- `50mA` 档的 `RLOAD` 显示波动较大，标准差约 `0.54Ω`，这是因为 `R = V/I` 在小电流时对电流噪声更敏感；
- `250mA` 和 `500mA` 档的负载显示已经比较稳，尤其 `500mA` 档 `RLOAD` 标准差约 `0.04Ω`。

显示滤波可以先按下面的思路实现：

```c
// 电流显示：响应稍快
I_disp = I_disp + 0.2f * (I_new - I_disp);

// 负载显示：响应更慢
Rload_disp = Rload_disp + 0.05f * (Rload_new - Rload_disp);
```

再加显示死区：

```text
Rload变化 < 0.3Ω 或 0.5Ω 时，不刷新显示
```

过流保护不要使用这么慢的显示滤波，仍应使用短平均或快速通道，并设置连续超限判据。

## 9. 纹波数据与测量方法

`Sheet2` 当前只记录了 `50mA` 档一项：

```text
I = 50mA
示波器读数 Vpp ≈ 5mV
若按 Rsense = 2Ω 直接换算：
Ipp ≈ 5mV / 2Ω = 2.5mApp
```

纹波粗略换算

题目若要求电流纹波不超过 `0.2mA`，对应采样电阻上的电压纹波只有：

```text
0.2mA * 2Ω = 0.4mVpp
```

因此 `5mVpp` 不能直接说明真实电流纹波合格。但也要谨慎：这个读数很可能混入了 BUCK 高频尖峰、探头地线环路噪声、示波器带宽和接地方式误差，不能仅凭一次普通探头读数判定真实低频电流纹波。

建议重测步骤：

```text
1. 先做噪声底测试：
   探头尖端和地都接到 Rs 下端 / ADC_REF_GND，观察 Vpp。

2. 正式测量：
   探头尖端接 Rs 上端 / V_SENSE；
   探头地接 Rs 下端 / ADC_REF_GND；
   使用短地弹簧，不使用长地夹；
   打开 20MHz 带宽限制；
   使用 AC 耦合；
   同时观察 1us/div、10us/div、100us/div，不只看 ns 级尖峰。

3. 记录 Vpp 后换算：
   I_ripple_pp = Vpp / Rsense
```

如果噪声底本身已经有几 mV，就说明当前测量夹具不足以验证 `0.4mVpp` 级别的采样纹波。

## 10. 汇总结论

已经比较好的部分：

```text
1. I_set -> I_meas 主链路线性很好，500mA 点误差约 -0.5%。
2. DAC2_meas -> I_meas 极其线性，说明模拟恒流内环本身很好。
3. 连续串口数据重复性不错，I_actual 标准差均小于 0.5mA。
4. 500mA + 约50Ω 工况下，VOUT+ 能到 27.724V，VMOS 约 1.9V，高压差工况可以跑。
```

建议马上修改或补测的部分：

```text
1. 固件更新 DAC2 命令校准：
   DAC2_cmd_mV = (I_set_mA - 1.3684f) / 0.49819f;

2. 固件更新电流显示校准：
   I_disp_mA = 0.98022f * I_serial_mA + 0.023f;

3. VOUT+ / VOUT- 先校准，再计算 Rload 和 VMOS。

4. DAC1 / BUCK 输出目标要根据实际负载估计值和 VMOS_margin 计算，避免 300~450mA 这种压差塌陷。

5. 纹波需要按短地、限带、噪声底测试的方法重测；目前 5mVpp 只能作为粗略风险提示，不能作为最终纹波结论。
```

一句话总结：**今天的数据说明电流控制主链已经接近成品状态；最大风险已经从“能不能恒流”转移到“显示准不准、余量够不够、纹波怎么测准”。**

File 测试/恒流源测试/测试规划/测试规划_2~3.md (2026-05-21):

目前已经确认，除了可调buck以外的供电/降压电路都没有问题

测试规范:

- <span class="mark">使能bucken前，要先确保DAC_CH1不是0V</span>（因为0V对应VOUT+最大输出目标，若此时负载较小，mos管发热严重会烧）

测试流程：

1.  测量R20、21、22的实际阻值，粗略计算公式Vout=A-B\*Vdac中的参数A、B，判断Vout+临界值情况

    1.  最大值

        1.  如果低于28V左右，就必须调整电阻（28V是极限，余量偏紧）

        2.  如果约 29V，可以接受

        3.  如果能到 30V，最好。

    2.  最小值

        1.  如果约3~4V，很理想

        2.  如果5V，可以接受

        3.  大于5V，得改电阻

（不改电阻只是不能测边界情况，而不影响接下来的测试，所以考虑到时间原因如果有这个问题可以先搁置？）

2.  如果VOUT范围合适，就进行低压（比如12V，限流0.5A）测试

    1.  接负载50Ω，目标电流设为0（DAC_CH2给0），单片机使能bucken（可能得测下有没有成功给出3.3V），测Vdac和VOUT+，验证趋势：DAC_CH1 越高，VOUT+ 是否越低

    2.  目标电流改为50mA（（DAC_CH2给0.1V）），在5~8V范围内改变VOUT+（DAC_CH1），看电流是否基本稳定在50mA，验证低输出范围是否正常

3.  MOS 裕量不足测试（主要是为了熟悉现象 & 找出大概可参考的Vds最小边界）（这个代替不了500mA&50Ω的最小边界，还得另测）

    1.  负载50Ω，目标电流50mA，先让VOUT+保持足够余量（6~8V），再逐步降低VOUT+，记录 mos余量不足时的临界Vmos（Vmos=VOUT- - Vsense）

    2.  观察mos余量不足的现象：

        1.  Vgate 会升高，甚至接近运放输出上限

        2.  实际电流达不到设定值

        3.  Vsense 开始低于 DAC_CH2

4.  进行高压测试——测量3~5组数据（eg：5、10、20、28、30），通过拟合进一步确认参数AB，得到精确公式。（因为还要考虑电阻误差、DAC 输出误差、LMR16030、FB 基准误差、PCB 实际情况，只测三个电阻的公式精度不够）

5.  还要测什么？

> 100mA 恒流测试  
> 不同负载 10Ω / 25Ω / 50Ω 的低电流测试  
> 短路低电流限流测试，比如 50mA
>
> ……

备注：VDAC_CH2与目标电流的关系：Vdac2=Vsense=I\*2Ω

暂时不用but先放这：

之后上自动测试时，要在软件里限制：

VDAC_MIN = 对应 VOUT=30V 的 DAC 值  
VDAC_MAX = 对应 VOUT=5V 的 DAC 值

（这个手动阶段还用不上吧？）

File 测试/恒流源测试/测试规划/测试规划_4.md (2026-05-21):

# 第四次测试规划

**存电问题**

1.  复现测试三现象：

> VIN给8V时，先是一切正常；
>
> 然后com脚给0.2V，看见电流0.12A，再撤去0.2V或者重新上电&使能，0.12A保持；
>
> 然后在使能情况下用万用表笔给com放电，电流恢复至待机功耗电流（8V时0.02A）；
>
> 此时立刻再重新上电，可观察到单片机供电受影响

2.  把com改成dacch2再看有没有0.12A，看R1路径通没通

3.  在com测试点焊盘和附近的agnd测试焊盘上焊下拉电阻47kΩ（得找找有没有插件，阻值差不多的就行），再看有没有存电问题

**代码验证**

1.  把DAC 代码跑通，单片机给dac1/2，看测试点上有没有对应电压、SW_IN=0 时COM 是否回到 0V即可，后续测试就不用再手动给电压了

2.  把ADC和串口打印代码跑通（同时记录万用表和串口打印值）：

    - VOUT+ 低压时 ADC_VOUT+ 是否约等于万用表 /11；

    - ADC_VOUT- 是否约等于万用表 /11；

    - Vsense 在无电流时是否接近 0；

    - 给 50mA 后 Vsense 是否接近 0.1V。

**恒流测试与自动调节BUCK测试**

1.  目标电流设为50mA（（DAC_CH2给0.1V）），负载45Ω，在6~8V范围内改变VOUT+（DAC_CH1），看电流是否基本稳定在50mA，验证低输出范围是否正常

> VOUT+=5V时，记录数据，对比理论值：

| 测量项 | 期望值 |
| --- | --- |
| DAC_CH2 / COM | 约 0.1V |
| Vsense | 约 0.1V |
| Vload | 约 2.25V |
| VOUT+ | 约 5V |
| VOUT- | 约 2.75V |
| VMOS = VOUT- - Vsense | 约 2.6V |
| 电流 | 约 50mA |

2.  目标电流设为100mA（（DAC_CH2给0.2V）），负载45Ω

程序预期公式输出：

Vbuck_target = I × Rload + I × Rs + VMOS_target

= 0.1 × 45 + 0.1 × 2 + 2.5

= 4.5 + 0.2 + 2.5

> = 7.2V
>
> 记录数据，对比理论值：

| 测量项 | 期望值 |
| --- | --- |
| DAC_CH1 | 约 2.40V |
| VOUT+ | 约 7.2V |
| DAC_CH2 / COM | 约 0.2V |
| Vsense | 约 0.2V |
| Vload | 约 4.5V |
| VOUT- | 约 7.2 - 4.5 = 2.7V |
| VMOS | 约 2.7 - 0.2 = 2.5V |
| 电流 | 约 100mA |

**连续调负载测试与MOS余量观察测试：**

1.  目标电流固定在 50mA，ADC计算Rload_est = Vload / Iactual

> 观察：

- Iactual 是否大致保持；

- VMOS 是否落在 2V~4V；（Vmos=VOUT- - Vsense也需要串口打印）

- Rload ↑是否：

  - Vload = I × Rload ↑

  - VOUT- = VOUT+ - Vload ↓

  - VMOS = VOUT- - Vsense ↓

2.  Rload 继续变大，比如接近 100Ω（可以换个大点的电位器）：

> Vload = 5.0V
>
> VOUT- = 1.0V
>
> VMOS = 1.0 - 0.1 = 0.9V

这时候 MOS 余量不足，可能出现：

> Vsense 低于 DAC_CH2；
>
> 电流达不到 50mA；
>
> Vgate 升高；
>
> 恒流失败。

**本次调试所需代码：**

1.  安全初始化：上电先 BUCK_EN=0，SW_IN=0，DAC_CH1=2.6V，DAC_CH2=0V

2.  SPI：DAC8562 写通道 A/B

3.  ADC读取+串口打印（ADC_VOUT+、ADC_VOUT-、Vsense、Iactual、Vload、VMOS、Rload_est）

4.  GPIO：BUCK_EN 控制GPIO：SW_IN 控制

附：

安全初始化和安全关断（AI提供的示例代码）

（这个优先级最高，避免上电瞬间 Buck 冲高、COM 存电、SW_IN 误接入）
```

void Safe_Init(void)

{

  Buck_Set(0);

  Swin_Set(0);

  DAC_Set_CH1(2.6f); // Buck 低输出目标，大约 5V

  DAC_Set_CH2(0.0f); // Iset = 0

}

void Safe_Off(void)

{

  DAC_Set_CH2(0.0f);

  HAL_Delay(20);

  Swin_Set(0);

  Buck_Set(0);

}
```

串口打印换算关系公式
```

VOUT+ = ADC_VOUT+\_pin \* 11

VOUT- = ADC_VOUT-\_pin \* 11

Vsense = ADC_VSENSE_pin

Iactual = Vsense / Rs

Vload = VOUT+ - VOUT-

VMOS = VOUT- - Vsense

Rload_est = Vload / Iactual
```

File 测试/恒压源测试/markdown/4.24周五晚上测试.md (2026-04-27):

测试记录：

起因就是我想起昨晚后面都是用5V测，但是tps5450最低要求输入电压是5.5V，我就想着会不会boot0V是欠压的问题，就又来测了一下。（还有发现单片机跳线帽不是都在00，还在串口烧录状态，不知道昨晚有没有记得归位？）

我用10V给VIN，5V给5V端子、3.3V用杜邦线给3.3V的端子。然后接上去单片机和板子上的两个电源指示灯是正常亮，但是过30s到一分钟左右就闻到一缕焦香（），马上断电。测单片机的3.3和gnd是正常的，后面我测试都把单片机拔掉了。测降压芯片的电阻也都是正常的。

单片机应该没事，但下次可能要试下裸板烧个程序能不能成功，再确认下有没有问题（第三次测试中确认完毕没有问题）

然后VIN给7V，发现一用3.3V手动使能ena引脚，就有比较大的电流音（原因分析见下图）（7V也被gemini分析说电压不够可能会引起震荡什么的）然后换了12V的VIN电压，电流音小了很多但还有（和昨晚stlink那个差不多大），然后测电压是PH输出1.55V（方波平均值），boot输出为0（自举电路坏了），VESENSE从0-0.07V循环变化。

总之就是，找不到那个味道的来源，不知道是哪个芯片发出来的，是tps5450还是单片机还是什么。。。

我今晚都没测采样电路，希望那里的芯片不要出事(ㄒㄒ)但还是得再测一下

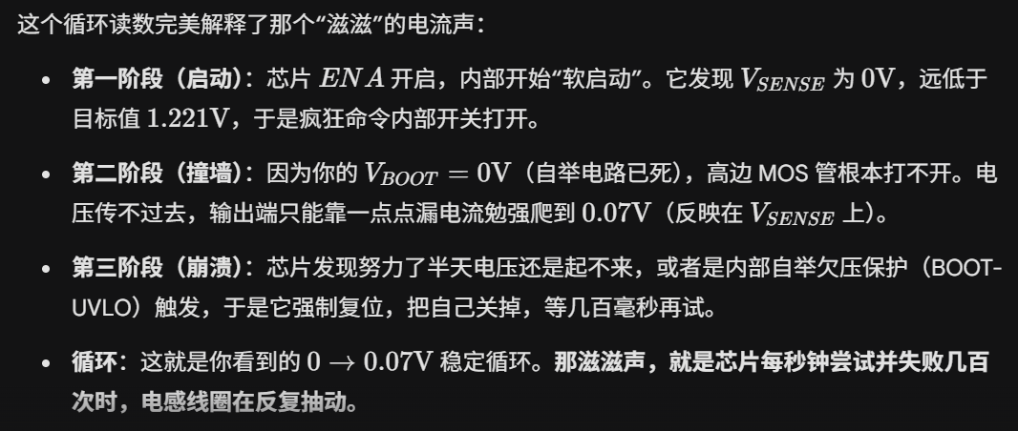
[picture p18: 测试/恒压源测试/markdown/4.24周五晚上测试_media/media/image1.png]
gemini给出的电流音解释如下：

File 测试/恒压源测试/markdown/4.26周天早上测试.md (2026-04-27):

测试记录：

- 核心板插着（烧录的程序是无关的PC13LED测试程序）；VIN接10V输入，5V端子和3V3输入端口都不接输入，拿3V3电压给ENA引脚使能，发现有输出（8.6V）（莫名其妙就有输出了）

- 测试数据：

100Ω负载

| 输入电压/V | 输出电压/V | VESESE/V |
|---|---|---|
| 10 | 8.6 | 1.2or1.12(? |
| 11 | 9.xx | 1.2or1.12(? |
| 12 | 1.xx | 0.2 |
| 15 | 1.55 | 0.2 |
| 20 | 2.xx | 0.2 |
| 30 | 4.xx | 0.4 |

- 换了0-100Ω的电位器负载，没记录具体数据，现象和之前没变化

- 观察到一个现象：用10VVIN，3V使能ena引脚。输出8.6V，看到boot引脚电压是慢慢上升，感觉用了半分多钟，最后稳定在16.87V（然而正常情况下充电是微秒级别的）

- 测了一下两个采样的接口，在10V输入、输出正常8.55V情况下，采样都为0，电压采样的运放的2、3脚都是合理的0.79V，判断故障可以锁定在运放芯片上，暂判断气味来源为运放芯片

**数据理解：**

在理想情况下，根据设定的分压电阻网络（1.5kΩ和10kΩ），反馈引脚（VSENSE）要达到内部基准电压 1.221V，根据分压公式 1.221 =VOUT\*1.5/（10+1.5），理论目标输出电压 VOUT应为 9.361V。若要在10V输入下达到此目标，理论上需要芯片提供93.6%的占空比。

然而，在实际运行中，输出电压受到了最大占空比限制与内部压降的双重制约：

首先，由于自举电容（C1）在每个周期都必须预留时间进行充电，芯片的最大占空比被物理限制在87%（来自tps5450数据手册）。若按87% 的极限占空比计算，10V输入能转换出的理论最高电压仅为8.7V。

其次，在这个 8.7V的基础上，扣除掉芯片内部及回路中的其他物理压降损耗后，最终实际的输出电压只能达到8.6（8.55）V。由于实际输出被卡在8.6V无法继续上升，可算出此时通过反馈网络分压后，实际送到 VSENSE 引脚的电压仅为1.12V。始终无法达到1.221V的稳压阈值，这也正是芯片在10V输入时只能处于极限“开环”挣扎状态的根本原因。

**前三次测试总体分析：**

- 输入电压下限是跟着分压电阻选择变的，不是5.5-36V。手册上写的5.5-36V，只是指逻辑控制电路正常开机的电压范围，但具体到我们的电路，由于改了分压网络，目标输出变成了9.36V，实际最小输入电压就已经被强行抬高了。

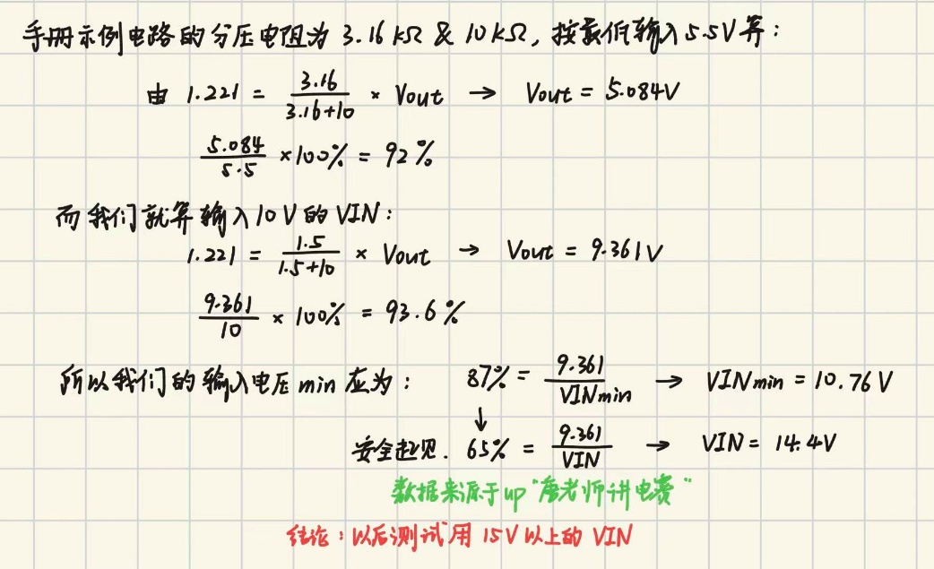
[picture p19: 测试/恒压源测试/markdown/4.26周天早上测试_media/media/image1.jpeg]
数学推导：

> <span class="mark">结论：以后测试用15V以上的VIN</span>

- **关于自举电路（BOOT）如何损坏的猜测**

<!-- -->

- 第一次给的5V实际上不会损坏这个芯片，只是单纯不让它启动

- 第二次与第三次给10V，如前面计算的，由于输入达不到 10.76V（11V）的下限门槛，芯片被迫一直顶在89%的最大占空比极限运行，最终烧断了自举充电回路。

<!-- -->

- **VSENSE引脚0-0.7V的循环**

给10V时，由于输入电压不够，芯片一直顶在最大占空比（87%）。内部的主MOS管几乎处于“长通”状态，很少进行开关动作。虽然 BOOT 电路已经坏了（观察到充电需要30秒），但只要管子勉强导通，它就能像一个大电阻一样把电导过去，维持住8.6V。

但当输入提高到 12V、15V 及以上时，电压余量充足，芯片退出占空比受限状态，尝试以 500kHz 的频率进行 PWM 闭环稳压。由于 BOOT 充电回路已在之前的测试中受损，其无法在高频下为内部高侧 MOS 管提供足够的栅极驱动电压。

这导致 MOS 管无法完全导通，其等效导通内阻Rds_on急剧增大。TPS5450 是通过检测 MOS 管的漏源压降V_ds来实现过流限制的 。巨大的内阻使得哪怕是极小的负载电流，也会产生巨大的 V_ds 压降，从而“欺骗”芯片内部的过流保护（OCP）比较器，使其误认为输出发生了严重短路。

触发过流阈值后，芯片立刻启动了断续模式过流限制（Hiccup 模式），强制关断输出并等待约 16ms 后重试 。正是因为芯片在极短的导通后便进入了长达 16ms 的休眠期，其平均发热功率极低，因此在宏观上并未表现出高温发烫的现象，同时外在表现为输出电压崩溃（1.xxV 均值）和 0-0.07V 的循环打嗝。

- **气味来源猜测**

可能是第二次10V、12V输入导致主回路震荡时，产生了恶劣的电磁尖峰。这些尖峰电压逆向冲破了脆弱的 OPA2188 输出级，烧断了其内部的走线

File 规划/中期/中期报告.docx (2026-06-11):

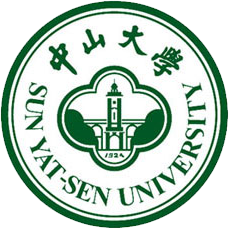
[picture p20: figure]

2026 中山大学电子设计校内赛

中期报告

队伍名：做的都队

队长名：邓嘉杰

成员名：刘欣雅，卢城霖

一、项目基本信息

赛题编号 | □ 选题一 □ 选题二 □ 选题三
赛题名称 | 高精度数控恒流源
队伍名 | 做的都队
队长名 | 邓嘉杰
成员名 | 刘欣雅，卢城霖
提交日期 | 2026年 5月 16日

二、目标与方案

项目目标与总体方案

项目目标：

1. 完成基本的恒流和高精度输出（0到500mA带负载0到50欧，1mA步进加0.5%误差以内），除此自外本项目还打算实现电阻测量功能和恒压模式。
2. 引入调节手段追踪负载电压，减小不必要的发热和能量损耗，尽量提升效率。
3. 具备过流保护、短路限流与开路报警等功能，确保运行安全。
4. 交互部分通过触屏串口LED屏显示设定电流和实际电流输出，外部能够预留按键和旋转编码器进行机械调节。

方案实现：

1. 恒流流部分通过精密运放与大功率 MOS形成深度负反馈实现DAC电压控制恒流输出。
2. 电压部分，供电电压通过DC电压（暂定35V）输入buck降压提供5V，5V通过LDO 转3.3V供电。另一路负载电压通过DAC控制可调buck动态提供所需电压。
3. 总体方案是MCU通过ADC获取采样电阻上电压从而计算出实际电流，电阻值再通过算法调节DAC输出控制1、2中电流和电压达成调节的效果，再通过MCU实现交互功能。
4. 对于存在的偏差通过打表和算法减小达到高精度稳定输出

三、进度概况

项目规划、已完成内容、未完成内容

目前已完成基本原理和仿真测试加测试板的原理图PCB绘制和打样，并测试基本降压功能实现，未完成部分有硬件恒流部分测试以及安全测试和软件部分。

未来打算一周内解决硬件问题和软件基本框架，再用其余时间针对问题完成成品的制作。

四、测试与问题

测试情况、存在问题与解决措施

焊接：

1. 部分元器件遗漏购买或封装有误，如果是不太重要的元器件用相近解决，重要器件用插件暂时替代，封装错误的用飞线解决。
2. 电阻有两个丝印填反，部分丝印没标识。
3. 总结，在成品板中可优化丝印问题，元件最好使用已有的，对照BOM表多次比对

逻辑部分：

1. 电压部分测试成功，5V,3.3V供电稳定且符合预期，可调buck基本符合预期输出电压关系为VOUT+ = 31.242 - 10.011 * VDAC1

（测试过程中5Vbuck上分压电阻意外脱落，钳位二极管被击穿但起到了保护作用，最后重新焊接测试完成）

2. 运放部分：mos管暂时无法导通，暂时没有解决，亟待后续测试

软件部分：

1. 单片机使能功能正常，板间互联正常

五、后续计划

后续工作安排

目前处于手动给DAC电压测试阶段，后续先确认mos管的问题，测试出运放部分是否能够做到DAC电压控制恒流输出，再进入软件控制DAC输出阶段和ADC采样测试和校准，然后实现算法部分达成目标，最后纠正已有问题做出成品（可制作外壳）

六、分工与附件

成员分工与附件清单

（方案基本实现由讨论得出）

邓嘉杰：原理图修正，PCB绘制，软件补充

刘欣雅：逻辑与交互原理图，调试记录，软件补充

卢城霖：电压原理图，软件框架

附件：项目地址sysuwilliam/NC-Current-Source (https://github.com/sysuwilliam/NC-Current-Source)

承办单位：中山大学电子与信息工程学院（微电子学院），中山大学学生信息科技发展中心

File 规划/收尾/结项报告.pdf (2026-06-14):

# 高精度数控恒流源

## 系统设计、控制分析与测试报告

参赛队伍 | 做的都队
参赛成员 | 邓嘉杰、刘欣雅、卢城霖
参赛选题 | 选题三：高精度数控恒流源
核心架构 | STM32F103 + MCP4822 + OPA197 + 可调 Buck

2026 年 6 月

高精度数控恒流源结项报告 | 做的都队

目录

I

摘要

本项目设计并实现了一套基于单片机控制的高精度数控恒流源。系统面向 0～500 mA 直流恒流输出需求，支

持 1 mA 步进设定、输出电流和负载参数实时显示，并具有过流、短路和开路保护功能。为兼顾恒流精度、输

出范围和功率器件温升，系统采用“可调 Buck 预稳压 + 运放/MOS 线性恒流 + MCU 数字标定与控制”的

混合控制结构。

硬件以 STM32F103C8T6 为控制核心，MCP4822 双通道 DAC 分别产生恒流参考电压和 Buck 调节电

压；OPA197、功率 MOS 管及 2 Ω 采样电阻构成快速模拟恒流内环；LMR16030 可调 Buck 根据设定电流

和负载估计值调节 VOUT+，为 MOS 管保留约 1.5 V 的工作压差，从而在保证恒流能力的同时降低线性功率

器件发热。STM32 同步采集 VOUT+、VOUT- 和 V_SENSE，完成电流、电压、负载阻值和 MOS 压差的计算，

并通过均值滤波、卡尔曼滤波、线性校准及多点标定后的残差补偿提高显示精度。

测试结果表明，DAC2 实测电压与输出电流具有很高的线性度，关系为 I_meas = 0.497253×DAC2_meas−0.029041，

决定系数达到 R²=0.99999994；设定电流与实测电流去除零点后决定系数为 R²=0.99999900。历史测试中

500 mA 点误差为 −2.5 mA，相对误差为 −0.50%；连续采样结果显示，50 mA、250 mA 和 500 mA 三档的

显示标准差均小于 0.5 mA。最终系统完成 0～500 mA 数字设定、负载阻值显示、Buck 自动调压以及过流、

短路和开路保护。串口屏除显示数值与状态外，还可实时绘制目标电流和实际电流双通道波形；项目同时完成

了面向实物装配、散热和操作的三维外壳结构设计。

关键词：数控恒流源；模拟负反馈；可调 Buck；数字校准；PI 控制；负载检测；STM32

### 1 项目背景与设计任务

### 1.1 项目背景

恒流源能够在负载阻值发生变化时维持输出电流基本不变，广泛应用于器件测试、LED 驱动、传感器激励、

电化学测量和实验室电源等场景。传统模拟恒流源具有响应快、结构直观的优点，但设定方式单一、参数不易

显示，且在宽负载范围下容易因功率管压差过大而产生明显发热；纯开关恒流方案效率较高，但开关纹波、闭

环补偿和低电流精度控制难度较大。

本项目将线性恒流与开关预稳压相结合：快速模拟环负责稳定电流，低速数字环负责设定、校准、显示、

保护和供电余量管理，使系统兼具高精度、宽负载范围和较低功耗。

### 1.2 设计任务

赛题要求设计并制作一台基于单片机控制的高精度数控恒流源，主要技术要求如下：

1. 输出电流范围为 0～500 mA，设定步进为 1 mA，精度要求为 ±0.5%；
2. 当输出电流超过 550 mA 时能够自动切断，并显示设定电流和实际输出电流；
3. 在恒流模式下，负载电阻在 0～50 Ω 范围变化时，输出电流变化绝对值小于设定值的 1%；
4. 输出端短路时自动将电流限制在设定值，不损坏设备；
5. 负载开路时自动检测并报警；
6. 发挥部分要求输出纹波电流不大于 0.2 mA，并能够测量和显示负载电阻值。

### 1.3 设计指标与完成情况

指标 | 赛题要求 | 系统设计与测试结果
输出电流 范围 | 0～500 mA | 实现 0～500 mA 数字设定，软件安全上限保留至 600 mA，正常使用限制在 500 mA
设定步进 | 1 mA | 实现 1 mA、10 mA、100 mA 可切换步进，默认可使用 1 mA 精调
电流精度 | ±0.5% | 主链路线性良好；历史保守数据最大误差约为 500 mA 点 −0.50%，低电流区通 过多点标定后的残差补偿进一步修正
负载范围 | 0～50 Ω | 模拟恒流环配合 Buck 自动调压，覆盖短路至约 50 Ω 负载
负载变化 | 电流变化绝对值小于设 定值 1% | 代表性负载变换数据的变化量小于设定值 1%
过流保护 | >550 mA 自动切断 | 设置 550 mA 阈值，触发后关闭 Buck 并锁存报警
短路保护 | 限制在设定值 | 模拟恒流内环天然限流，软件识别短路状态并降低 Buck 输出
开路保护 | 自动检测并报警 | 根据设定电流、实际电流和输出状态检测并报警
负载阻值 显示 | 可测量并显示 | 由校准后的负载压降与输出电流计算，低电流区设置显示门限和强滤波
输出纹波 | ≤0.2 mA | 已建立采样电阻纹波测试方法；普通探头粗测受噪声底限制，详见 8.7 节

### 2 系统总体方案

### 2.1 总体设计思路

系统采用两块 PCB 分离设计：功率/模拟板负责输入保护、电源变换、恒流功率级和模拟采样；控制板负责

STM32、编码器、按键、串口通信与人机交互。板间通过排线传输 SPI、Buck 使能和 ADC 信号，能够降低

功率开关噪声对数字控制和弱信号测量的影响，也便于分模块调试。

总体能量与控制流程如下：

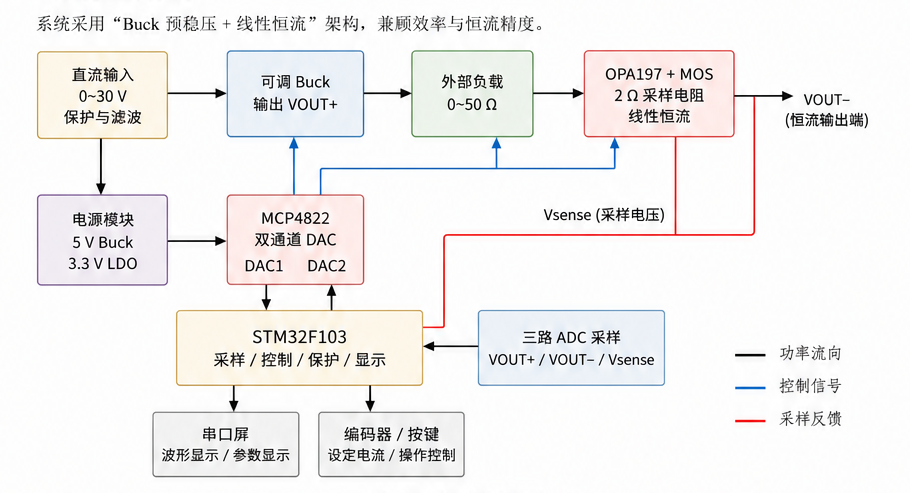
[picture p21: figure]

图 1 系统总体架构

### 2.2 方案比较与选择

### 2.2.1 纯线性恒流方案 纯线性方案可由运放、MOS 管和采样电阻构成，结构简单、输出纹波低、恒流响应

快，但 MOS 管承受的功耗为：

PMOS = VMOSIout

当输入电压高、负载电压低或发生短路时，MOS 管压差明显增大，容易产生较高温升，不利于长期稳定

运行。

### 2.2.2 纯 Buck 恒流方案 纯开关恒流方案效率高，但要在 0～500 mA 全范围内同时满足低纹波、高精度和

快速负载响应，需要复杂的电流模式控制和环路补偿，且开关节点噪声会增加 ADC 和显示校准难度。

### 2.2.3 本项目混合方案 本项目由 Buck 粗调供电电压、线性环精调输出电流：

- OPA197 与 MOS 构成的模拟恒流环响应最快，直接承担负载扰动；
- DAC2 和数字 PI 负责设定与静态精度修正；
- DAC1 和 Buck 慢环只管理 MOS 压差，不参与高速电流调节。

这种分层控制使每个环路只处理适合自身带宽的问题，既避免 Buck 高频调节干扰电流，又显著降低

MOS 管长期功耗。

### 2.3 系统模块组成

模块 | 核心器件或参数 | 主要作用
主控模块 | STM32F103C8T6 | 数据采集、控制计算、状态机和人机交互
双通道 DAC | MCP4822-E/SN | DAC1 控制 Buck，DAC2 产生恒流参考
模拟恒流环 | OPA197 + SUD50N06-09L-TP + 2 Ω | 快速建立并稳定输出电流
可调 Buck | LMR16030 | 输出 VOUT+，动态管理 MOS 压差和功耗
固定电源 | LMR16030 + SPX29302 | 产生 5 V 和 3.3 V 电源
ADC 采样 | STM32 内部 ADC + 精密分压 | 采集 VOUT+、VOUT−、Vsense
人机交互 | 串口屏、EC11 编码器、按键 | 参数设置、数据显示和告警提示
输入保护 | 自恢复保险丝、TVS、共模电感 | 过流、浪涌和高频干扰抑制

### 3 硬件系统设计与工作原理

### 3.1 输入保护与电源树

系统测试时通常使用 24～30 V 直流输入，输入端依次设置自恢复保险丝、TVS 管、共模电感和大容量滤波

电容。电源分为两路：

1. 一路经可调 LMR16030 输出 VOUT+，供负载和线性恒流功率级使用；
2. 另一路经固定 Buck 输出 5 V，供 OPA197 和串口屏使用，再通过 SPX29302 LDO 产生 3.3 V，供 STM32、MCP4822 和小信号电路使用。

固定 5 V 和 3.3 V 电源与功率输出分开，避免负载变化直接影响 MCU 供电。调试过程中发现，实验电

源限流设置过低时会进入恒流模式，造成 5 V、3.3 V 下跌及 MCU 复位，因此整机调试时将输入电源限流设

置为不低于 0.5 A，并在正式工作前检查电源是否保持 CV 状态。

### 3.2 双通道 DAC 电路

MCP4822 是双通道 12 位电压输出 DAC，通过 SPI 与 STM32 通信。两路输出的职责严格分开：

- DAC1：经 OPA197 和反馈网络改变可调 Buck 的反馈状态，用于调节 VOUT+；
- DAC2：产生恒流参考电压，直接送入恒流运放同相端。

DAC2 与运放输入之间串联 R1=330 Ω。该电阻不是为了形成明显分压，而是限制异常状态下的瞬态电

流，并与输入端电容共同隔离 DAC 输出和运放输入的高频扰动。输入节点通过 R6=49.9 kΩ 下拉至 AGND，

使 MCU 未初始化、DAC 关闭或连接异常时仍具有明确的 0 V 默认状态，避免高阻节点悬浮；C5=100 nF

对参考电压进行低通滤波，减小数字通信和电源噪声耦合到恒流设定端。

参考节点的直流关系为：

Vref = VDAC2

49.9k
49.9k + 330

比例约为 0.99343，因此保护电阻对量程影响很小，可在标定中统一补偿。

### 3.3 模拟恒流内环

恒流功率路径为：

VOUT+ → 负载 → VOUT− → Q2 Drain → Q2 Source

→ V_SENSE_RAW → Rs → GND

OPA197 同相端接收 DAC2 参考，反相端经 R5=47 Ω 采集 V_SENSE_RAW。运放调节 Q2 Gate 电压，使

采样电阻两端电压逼近参考电压：

Vsense ≈ Vref, Iout =

Vsense
Rs

本系统实际使用开步睿思 PZWR0005B2R00A9 精密绕线电阻，参数为 2 Ω、±0.1%、5 W。因此理想关系

约为：

### Iout(mA) ≈ 0.496715 VDAC2(mV )

实测斜率为 0.497253 mA/mV，与理论值接近，说明模拟恒流链具有良好的线性基础。

运放输出与 MOS Gate 之间串联 R4=47 Ω，用于限制 MOS 栅极瞬态充放电电流，并隔离栅极电容对运

放输出稳定性的影响；反相输入前的 R5=47 Ω 可限制异常输入电流，并与补偿网络共同改善高频稳定性。运

放输出与反相端之间预留 C2=330 pF 补偿电容，用于抑制由 MOS 栅极电容、布线寄生参数和负载变化引起

的高频振荡。该电容取值需要在稳定性和响应速度之间折中，因此原理图中保留了根据阶跃波形调整或拆除

的余地。

### 3.4 MOS 管工作区与功耗管理

Q2 采用 SUD50N06-09L-TP 功率 MOS 管，在本系统中工作于线性区。MOS 管压差定义为：

VMOS = VOUT − − Vsense

MOS 功耗为：

PMOS = VMOSIout

如果 Buck 输出过低，V_MOS 不足，运放即使将 Gate 电压提高也无法继续增加电流，恒流环进入压差饱

和；如果 Buck 输出过高，则 MOS 功耗和温升增加。综合恒流稳定性和发热，系统将目标 MOS 压差设置为

约 1.5 V，并允许其在合理范围内缓慢变化。

例如在 500 mA 工作时，若 V_MOS=1.5 V，MOS 理论功耗约为：

### PMOS = 1.5 × 0.5 = 0.75W

相比直接由 30 V 线性降压，该功耗明显降低。PCB 对 MOS 大焊盘铺铜并设置导热过孔，实物安装散

热片，外壳在 MOS、电感和采样电阻附近预留通风区域。

### 3.5 可调 Buck 与 DAC1 控制

可调 Buck 使用 LMR16030。DAC1 经运放和反馈网络改变 FB 节点等效电压，从而调节 VOUT+。最终阶段

对控制链进行了实测标定，得到：

### VOUT + = 10.012879 VDAC1 − 1.797554

因此目标输出电压对应的 DAC1 命令为：

VDAC1 =

VOUT +,target + 1.797554
10.012879

DAC1 输出在软件中限制于硬件有效范围，目标 VOUT+ 同时受输入电压和 Buck 最大占空比限制。当输

入为 30 V 时，系统在 500 mA、约 50 Ω 负载工况下可将 VOUT+ 提高至约 27.7 V，并为恒流环保留接近 2 V

的 MOS 压差。

### 3.6 ADC 采样电路

系统采集三个模拟量：

- ADC_VOUT+：VOUT+ 经 330 kΩ/33 kΩ 精密电阻分压；
- ADC_VOUT−：VOUT− 经相同比例分压；
- V_SENSE：采样电阻上端电压经独立 RC 滤波后进入 ADC。

VOUT 分压比例约为 11，使最高约 30 V 的功率输出落入 3.3 V ADC 的安全量程。分压节点后串联

1 kΩ，并配置 22 nF 电容：串联电阻限制 ADC 采样瞬态电流并隔离输入保护，电容滤除 Buck 开关尖峰。

V_SENSE 通道使用 1 kΩ+10 nF 的较轻滤波，兼顾保护、抗噪和电流变化响应。

理想换算为：

VOUT =

### ADCraw 4095 × 3.3 × 11, Iraw =

Vsense
2Ω

实际系统在理想换算后再进行通道标定，用于补偿 ADC 参考电压、分压器实际比例、地参考差异和装

配误差。

### 3.7 数模地、跨板连接与 PCB 布局

功率/模拟板设置 GND、AGND 和 ADC_REF_GND：

- GND 承担 Buck、MOS、负载和采样电阻的功率回流；
- AGND 作为 DAC、运放等弱信号电路的参考；
- GND 与 AGND 通过 0 Ω 电阻单点连接；
- ADC_REF_GND 从采样参考区域单独引至控制板，避免屏幕、LED、按键和数字通信电流流过模拟测

量参考。

PCB 将 Buck 的 SW 节点、电感和肖特基二极管集中在功率区，将 DAC、运放、ADC 分压和反馈线布

置在模拟区。MOS Gate、运放输入及 ADC 信号远离电感和高速开关节点；采样电阻的反馈线从器件端点单

独引出，减小大电流铜皮压降对测量结果的影响。

两块板联调时还发现，实验室临时取用、长度和接触质量不一致的散装杜邦线会明显影响跨板 ADC 信

号稳定性。其原因包括接触电阻变化、信号回路面积过大、参考地与信号线分离以及对 Buck 开关噪声的拾

取。最终连接应使用长度一致、固定压接的排线或线束，并使每个敏感模拟信号尽量与 ADC_REF_GND 相

邻；调试线束固定后不再随意更换。该经验同时说明，精密测量系统的“连接器和线束”属于模拟链路的一部

分，而不是可以忽略的机械附件。

### 4 控制系统与软件设计

本章的软件说明以仓库 代码/6.11 晚最后代码为基准。最终固件采用采样就绪标志协调控制更新，电流 PI 与

Buck 前馈分别承担不同任务，串口屏数据通过发送队列输出，避免长时间阻塞主控制流程。

### 4.1 控制层级

系统包含三个不同时间尺度的环节：

1. 模拟恒流内环：由 OPA197、MOS 和采样电阻组成，速度最快，直接抑制负载扰动；
2. 数字电流修正： STM32 根据校准后的电流反馈，以增量式 PI 微调 DAC2，修正稳态误差；
3. Buck 供电余量前馈：根据设定电流和负载估计值计算 VOUT+，约 1 s 更新一次，用于保证 MOS 工作

压差并降低发热。

其中 Buck 程序不是高速电流闭环，也不追踪每一次 ADC 抖动；快速恒流由模拟环完成。

### 4.2 主程序流程

均值窗口和卡尔曼状态完成更新后置位 ADC_FLAG，DAC1、DAC2 只在新数据有效时更新。屏幕发送采用缓

冲队列和串口中断机制，数值刷新与波形绘制不会在主循环中长时间等待。

### 4.3 数据采集与滤波

三路 ADC 原始值分别进入独立数组，达到设定样本数后计算均值，再送入三个独立的一维卡尔曼滤波器。最

终代码中的典型参数为：

Q = 0.001

MEA = 0.05

| 均值滤波降低随机抖动，卡尔曼滤波改善显示稳定性。VOUT+、VOUT−、Vsense 分别维护独立状态，

避免通道间相互覆盖。

### 4.4 电流设定前馈

历史标定得到 DAC2 命令电压与实测电流的关系：

### Imeas(mA) = 0.498188 VDAC2,cmd(mV ) + 1.368386

| 目标电流可反算为 DAC2 初始命令：

### VDAC2,ff(mV ) = Iset(mA) − 1.368386

0.498188

| 前馈用于使输出快速接近目标，PI 只修正剩余偏差。实际输出还经过上下限约束，避免异常变量产生超

量程命令。

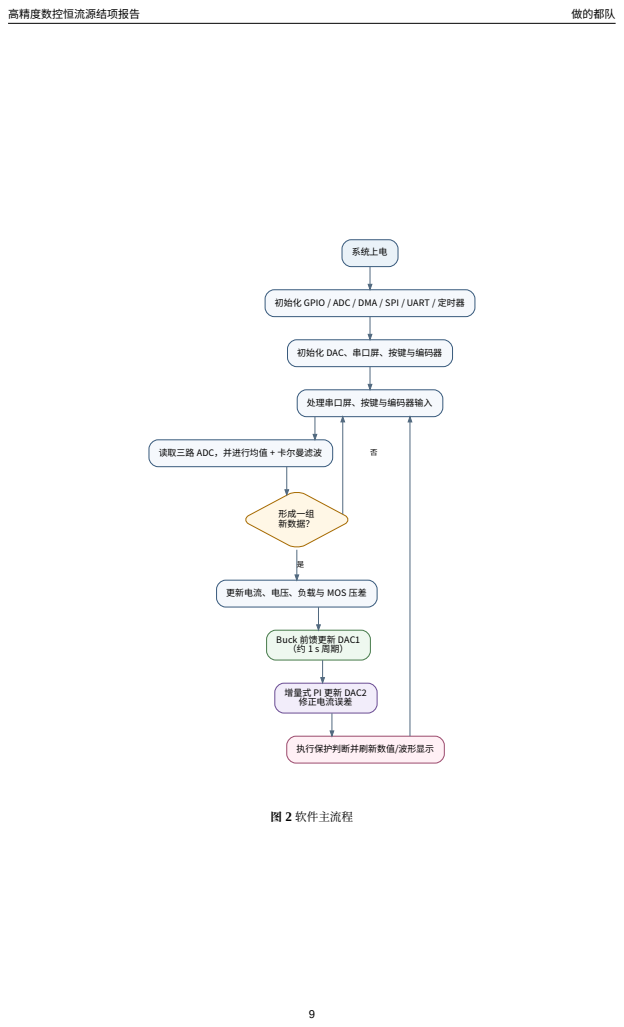
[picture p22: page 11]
系统上电; 处理串口屏、按键与编码器输入; 形成一组 新数据？; Buck 前馈更新 DAC1 （约 1 s 周期）; 执行保护判断并刷新数值/波形显示; 图 2 软件主流程

初始化 GPIO / ADC / DMA / SPI / UART / 定时器

初始化 DAC、串口屏、按键与编码器

读取三路 ADC，并进行均值 + 卡尔曼滤波

更新电流、电压、负载与 MOS 压差

增量式 PI 更新 DAC2
修正电流误差

### 4.5 增量式 PI 电流修正

最终代码采用增量式 PI：

### e(k) = Iset(k) − Idisp(k)

### Δu(k) = Kp

### [e(k) − e(k − 1)] + Ki

e(k)

### u(k) = u(k − 1) + Δu(k)

参数为 Kp=0.0007、Ki=0.00025、Kd=0。程序设置误差死区，并将 DAC2 命令限制在 0～1.4 V。不

使用微分项，是因为 ADC 量化噪声和 Buck 开关尖峰会被微分运算放大；本系统的主要动态响应已由模拟恒

流环承担。

### 4.6 电流显示误差补偿

原始电流由 V_SENSE/2 Ω 得到。最终程序首先进行全量程基础修正：

### Ibase = 0.98189Iraw + 4.821mA

随后依据多点标定结果，对低电流区中可重复的剩余偏差作小幅补偿。该处理本质上是仪器标定：用稳

定的外部电流表建立 ADC 读数与实际电流之间的静态映射，而不是改变模拟恒流原理或让控制程序直接“套

用目标答案”。报告不将这一实现细节作为主要创新点，系统精度仍主要建立在高线性的模拟恒流内环、精密

采样电阻和 PI 闭环基础上。

### 4.7 VOUT 校准、负载计算与显示

最终 VOUT 校准公式为：

VOUT +,cal = 0.98663VOUT +,raw + 0.13675

VOUT −,cal = 0.97992VOUT −,raw + 0.24886

校准后计算：

Vload = VOUT +,cal − VOUT −,cal

Rload =

Vload

Idisp

低电流时除法会放大噪声，因此程序在电流过小时不更新负载阻值，正常工作区对结果进行滤波和范围

限制。

### 4.8 Buck 供电余量前馈

最终代码每约 1000 ms 更新一次 Buck 控制量。目标电压为：

VOUT +,target = IsetRload + IsetRs + 1.5V

再由实测关系反算 DAC1：

VDAC1 =

VOUT +,target + 1.797554
10.012879

DAC1 命令限制在硬件有效范围内。低于约 10 mA 时，程序将 DAC1 设置为较低的安全值，避免低电

流或空载状态下 VOUT+ 无必要升高。该算法是低速前馈而非高速反馈：它根据当前负载估计给出合适供电

余量，恒流精度仍由模拟内环和 DAC2 PI 保证。

### 4.9 人机交互与波形显示

串口屏能够显示设定电流、实际电流、VOUT+、VOUT−、负载电压、负载阻值、DAC 命令以及保护状态。

编码器支持 1 mA、10 mA、100 mA 步进调节，按键用于输出控制和报警处理。

除数值显示外，屏幕内置双通道波形窗口：通道 0 绘制目标电流，通道 1 绘制实际电流。STM32 周期性

调用波形数据发送函数，将两条曲线同步送入串口屏，因此能够直接观察设定变化、建立过程、稳态偏差和扰

动恢复。这一功能既提高了现场展示效果，也为 PI 参数调整和异常排查提供了直观依据。

### 5 保护设计

### 5.1 过流保护

程序将 550 mA 作为过流阈值。当校准后的电流量超过阈值时，状态标志进入过流保护，主程序关闭 Buck，

使目标电流和 DAC2 命令回到安全状态，并在串口屏显示故障信息。保护解除后由用户重新确认输出条件，

避免自动反复启动。

### 5.2 短路限流

输出端短路时，负载电压接近零，但 OPA197、MOS 和采样电阻构成的模拟负反馈环仍会使 V_SENSE 跟随

DAC2 参考，因此电流被限制在设定值附近。短路保护的核心不是额外制造一个更高带宽的软件环，而是利

用原有硬件恒流内环完成限流；Buck 前馈在低负载条件下降低 VOUT+，减少 MOS 在短路状态下的功耗。

短路解除后，系统继续按负载估计更新供电余量。

### 5.3 开路检测

输出使能后，如果实际电流接近零，程序将其判为负载开路，关闭 Buck 并在屏幕显示开路告警。开路判断依

赖电流反馈和 Buck 使能状态，不通过 V/I 计算，因此不会在电流接近零时产生除零问题。工程使用中应在

输出连接稳定后再使能，并保证板间采样线与参考地连接可靠，避免接触不良被误认为负载开路。

### 5.4 保护测试结果

测试项

目 | 测试方式 | 系统表现 | 结
| | | 论
过流 | 将输出条件推向 550 mA 以上 | Buck 关闭，输出命令进入安全状态，屏幕显示过流信息 | 通
| | | 过
短路 | 输出端直接短接 | 模拟恒流环将电流限制在设定值附近，器件未出现损坏 | 通
| | | 过
开路 | 工作过程中断开负载 | 电流降为零，系统关闭输出并显示开路告警 | 通
| | | 过
故障恢 复 | 排除故障后重新确认输出 | 系统可恢复正常工作 | 通
| | | 过

### 6 设计、制作与调试过程

### 6.1 第一阶段：电源与 Buck 验证

首轮焊接后，先将恒流环关闭，仅验证输入保护、固定 5 V、3.3 V LDO 和可调 Buck。测试确认固定供电基

本正常，可调 Buck 能随控制点变化。早期实验同时发现元件漏焊、封装不匹配、反馈电阻开路等问题，由此

建立了“分模块上电、先电阻再电压、先固定电源再功率输出”的调试流程。

### 6.2 第二阶段：恒流模拟链路排查

初次测试中出现 DAC2 给定后 MOS 源极电压仍接近零的现象。逐点测量 DAC 输出、运放同相端、反相端、

输出端和 MOS 三极后，定位到 DAC2 至运放输入的 R1 焊接不良。重新焊接后参考电压能够到达运放输入，

验证了逐节点测量对模拟闭环排故的重要性。

同时观察到固定较高 VOUT+ 时 MOS 明显发热，说明仅有线性恒流环虽然能够工作，但不适合宽负载范

围长期运行。这一结果推动了后续 Buck 自动余量控制设计。

### 6.3 第三阶段：DAC 方案迭代

早期版本采用另一型号 DAC，调试中出现参考电压无法启动、输出高阻和焊接可靠性问题。经过 SPI 波形、

供电、参考电压及芯片焊接检查后，团队决定更换为 MCP4822，并重新设计功率/模拟板。新方案具有内置基

准、双通道结构清晰、驱动简单等优点，最终稳定实现 DAC1、DAC2 双路控制。

同时取消了容易形成悬浮节点的模拟开关，使 DAC2 经保护电阻直接进入恒流运放，并增加明确下拉路

径。这一修改减少了启动状态不确定性，也简化了保护和调试逻辑。

### 6.4 第四阶段：第二版硬件联调

新板完成后，依次验证：

1. MCP4822 SPI 通信和实际输出；
2. DAC1 与 VOUT+ 的传递关系；
3. DAC2 与实测电流的传递关系；
4. V_SENSE、VOUT+、VOUT− 跨板采样；
5. 编码器、串口和串口屏通信。

测试中曾出现 VOUT+ 消失，最终定位为 Buck 反馈网络中的 R21 开路。重新焊接后 Buck 恢复。该问

题说明功率反馈路径中的单个焊点即可使整机表现为严重故障，因此最终 PCB 增加关键测试点，并在装配后

进行断电连通性检查。

跨板 ADC 联调还发现，随机取用的散装杜邦线会使 Vsense 和 VOUT 采样出现明显漂移或跳动。更换

为接触可靠、长度一致并将模拟信号与 ADC_REF_GND 配对的固定线束后，采样稳定性显著改善。最终将

线束与连接器纳入模拟测量链统一管理。

### 6.5 第五阶段：数据标定与软件重构

系统能够恒流后，采集 0～500 mA 多点数据，记录设定电流、DAC2 命令、DAC2 实测值、电流表值、ADC

显示值及 VOUT 参数。数据分析表明：

- 模拟恒流内环本身线性度极高；
- DAC 命令值与实际输出存在固定增益和零点偏差；
- ADC 电流显示存在比例误差和低电流残差；
- VOUT+、VOUT− 需要分别校准；
- 不同负载下 MOS 压差需要由 Buck 自动管理。

因此软件重构为独立的采样滤波、物理量换算、校准、PI、电源余量和保护模块，避免原先在主循环中混

杂更新造成变量语义不清和调节周期不确定。

### 6.6 第六阶段：最终闭环与功能完成

最终阶段完成了：

- 低电流显示残差补偿；
- 电流 PI 参数调整；
- VOUT+、VOUT− 和负载阻值校准；
- Buck 负载前馈慢环；
- 过流、短路和开路保护；
- 串口屏数据显示和状态提示；
- 外壳结构与接口布局设计。

最终系统能够在改变设定电流和负载时自动调节 VOUT+，并保持输出电流稳定，形成从硬件、固件、交

互到结构设计的完整作品。

### 6.7 关键迭代汇总

阶段 | 主要问题 | 定位方法 | 改进结果
初版供电 | 元件漏焊、反馈开路 | 断电阻值和分模块上电 | 固定 5 V、3.3 V 和 Buck 正常
恒流输入 | DAC2 未到达运放输入 | 测量 DAC2、R1、U2 +IN | 修复 R1 焊点，恒流链建立
DAC 调 试 | 参考和输出异常 | 独立供电、SPI 波形、芯片引脚检查 | 改用 MCP4822，双通道正常
功率温升 | MOS 压差过大 | 测量 VOUT−、Vsense 和温升 | 引入 Buck 余量控制和散热片
采样显示 | 电流与电压显示偏差 | 多点仪表对比和误差分析 | 完成线性校准和多点误差补偿
控制稳定 | 两个数字环互相干扰 | 降低更新频率、职责分离 | 模拟快环、PI 慢修正、Buck 更慢
安全功能 | 故障状态需自动处理 | 开路、短路、过流实测 | 三类保护通过

### 7 成果展示

### 7.1 硬件成果

项目完成了一套控制板和一套功率/模拟板。功率/模拟板集成输入保护、固定 5 V Buck、可调 Buck、MCP4822、

OPA197、功率 MOS、2 Ω 精密采样电阻以及三路 ADC 前端；控制板集成 STM32、编码器、按键、串口屏

接口和板间连接器。两板分离便于功率区与数字区独立调试，同时通过固定线束传递 DAC、控制和采样信号。

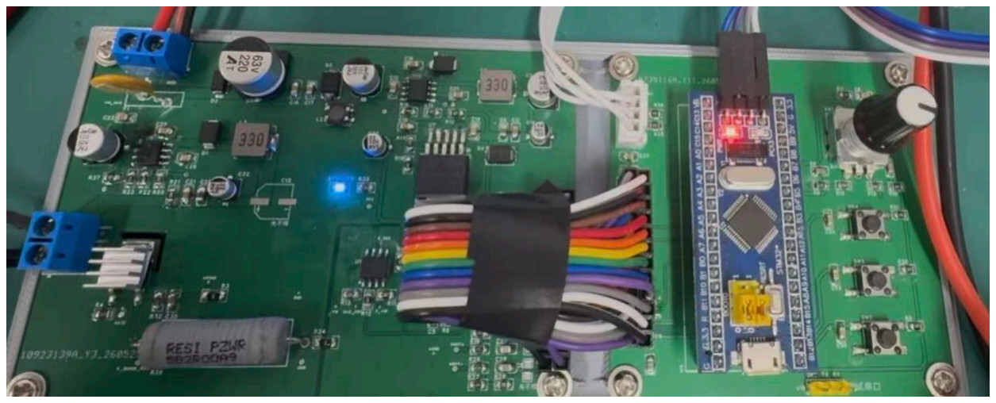
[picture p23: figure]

图 3 功率/模拟板与控制板实物合照

### 7.2 串口屏与波形显示

串口屏可显示设定电流、实际电流、VOUT+、VOUT−、负载阻值、DAC 命令、输出状态和故障状态。其波

形页面同时绘制目标电流与实际电流，两条曲线能够直观反映设定阶跃、实际跟随和稳态波动。这一设计使恒

流源不依赖外接上位机即可完成基本状态观察，也便于现场展示控制效果。

### 7.3 外壳结构设计

项目完成了针对双板系统的三维外壳方案。功率板位于底部并围绕 MOS、Buck 电感和采样电阻设置通风区

域；串口屏固定在上盖开窗处；控制板和编码器布置在便于操作的面板位置。外壳采用分体式安装和可拆上

盖，屏幕、控制板和功率板分别设置机械支撑，避免通过 PCB 或排线相互承力，并为内部线束预留弯折和检

修空间。

### 7.4 软件与工程成果

项目仓库保存了最终 STM32 工程、串口屏工程、原理图与 PCB、外壳模型、测试日志、校准数据和分析图

表。软件实现了 ADC 采样与滤波、增量式 PI、电源余量前馈、状态显示、双曲线波形以及三类故障处理。

### 7.5 项目特点

1. Buck 与线性恒流协同： Buck 管理功率余量，模拟环保证快速稳流，兼顾效率和精度；
2. 双 DAC 分工明确： DAC1 管理供电余量，DAC2 管理恒流参考；
3. 可视化程度高：串口屏同时显示数值、状态以及目标/实际电流波形；
4. 测量链工程化：采用独立 ADC 参考地、精密 2 Ω 采样电阻和固定跨板线束；
5. 完整设计闭环：项目覆盖原理图、PCB、固件、测试标定、保护、人机界面和外壳结构。

### 8 测试方案与结果分析

### 8.1 测试仪器与条件

测试使用可调直流稳压电源、数字万用表、电流表、示波器以及多组功率电阻/滑动变阻器。输入电压主要为

24～30 V，测试前确认电源处于 CV 模式且限流不低于系统正常输入电流。电流表串接于输出回路，万用表

分别测量 DAC、VOUT 和 Vsense 测试点；ADC 数据通过串口输出并同步显示在串口屏。

### 8.2 DAC2 实测电压与输出电流

测试得到：

### Imeas(mA) = 0.497253VDAC2,meas(mV ) − 0.029041

决定系数 R²=0.99999994，RMSE 为 0.041 mA，最大残差约 0.090 mA。理论斜率为 0.496715 mA/mV，

与实测结果接近，证明 OPA197、MOS 和 2 Ω 采样电阻构成的模拟内环具有良好线性。

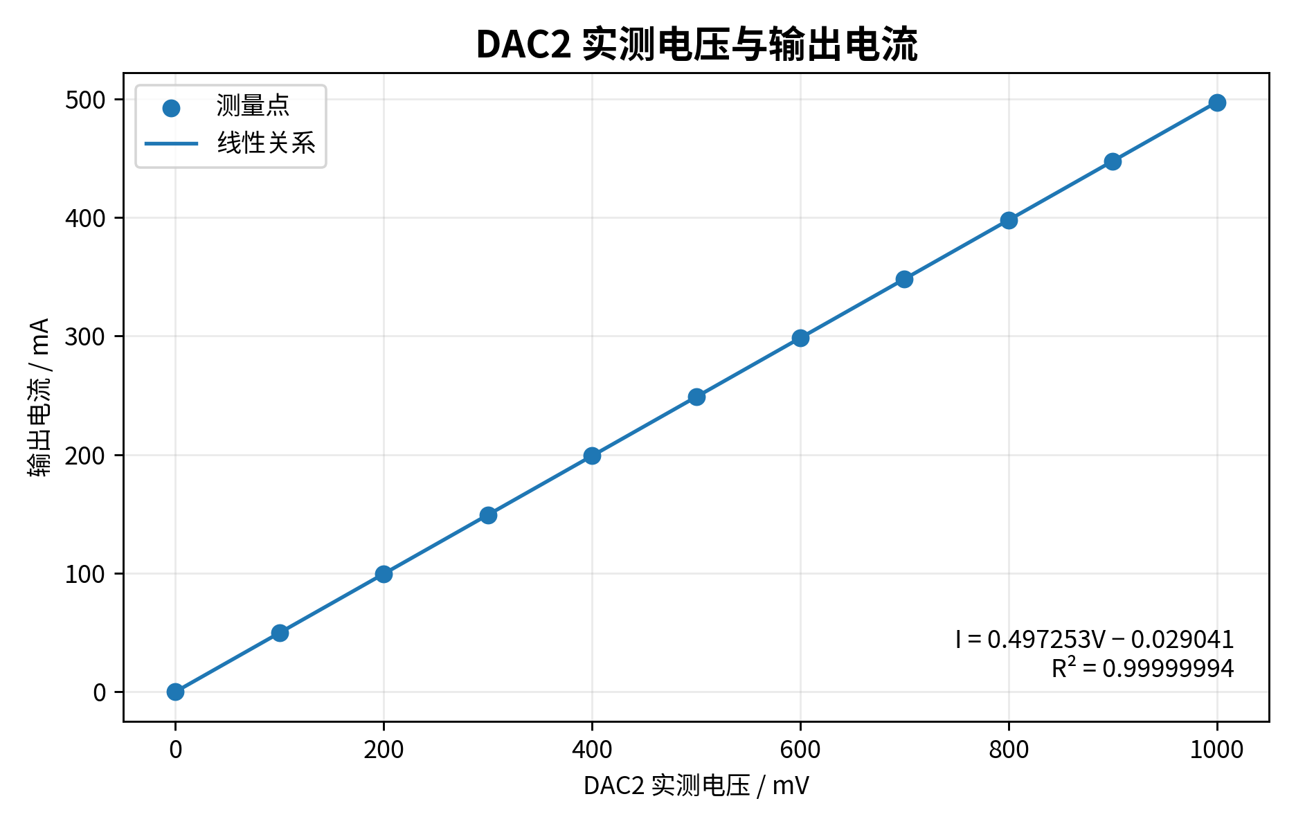
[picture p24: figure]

图 4 DAC2 实测电压与输出电流

### 8.3 设定电流与实测电流

综合校准表中，设定电流与电流表实测值的关系为：

### Imeas(mA) = 0.994738Iset(mA) + 0.067706

去除 0 mA 点后，R²=0.99999900，RMSE 为 0.165 mA，最大残差为 0.345 mA。历史数据中 500 mA

点为 497.5 mA，误差 −2.5 mA，相对误差 −0.50%；低电流区绝对误差通常为亚毫安量级，但由于分母较小，

相对误差更敏感。


图 5 设定电流与实测电流

图 6 电流设定误差

### 8.4 电流显示误差补偿

多点仪表对比表明，ADC 显示误差具有较稳定的增益和零点成分，低电流区还存在小幅、可重复的剩余偏差。

程序先进行基础线性修正，再根据标定结果对剩余偏差作小幅补偿。补偿前典型的“电流表实测值减显示值”

如下：

I_set/mA 差值/mA I_set/mA 差值/mA

10 | 1.08 | 100 | 1.00
20 | 1.80 | 150 | 0.70
30 | 1.40 | 200 | 0.50
40 | 1.37 | 250 | 0.80
50 | 1.24 | 300 | 0.90
60 | 0.70 | 350 | 1.00
70 | 0.70 | 400 | 0.80
80 | 1.00 | 450 | 0.30
90 | 1.70 | 500 | −0.10

这些误差相对于 0～500 mA 满量程很小，但在 10～100 mA 区间会明显影响相对误差，因此需要进行

低电流标定。

### 8.5 VOUT+、VOUT− 校准

最终校准数据如下：

VOUT+ 原始换算/V 万用表/V VOUT− 原始换算/V 万用表/V

4.94 | 5.007 | 1.60 | 1.865
12.02 | 12.004 | 9.24 | 9.237
20.14 | 20.002 | 17.36 | 17.247
27.22 | 26.994 | 24.46 | 24.249

得到：

VOUT +,cal = 0.98663VOUT +,raw + 0.13675

VOUT −,cal = 0.97992VOUT −,raw + 0.24886

校准后的电压足以支持负载阻值显示和 Buck 余量估计。


### 8.6 连续采样稳定性

三档连续串口数据统计如下：

Iset/mA | 样本数 | Iactual 均值/mA | 标准差/mA | Vsense 均值/mV | Vsense 标准差/mV | Rload 均值/Ω Rload 标准差/Ω VMOS 均值/mV
50 | 29 | 51.023 | 0.447 | 97.793 | 0.412 | 50.161 | 0.537 | 1920.4
250 | 30 | 252.685 | 0.377 | 501.900 | 0.305 | 49.759 | 0.097 | 2346.5
500 | 31 | 506.804 | 0.301 | 1009.742 | 0.514 | 49.631 | 0.039 | 1924.4

三档显示标准差均小于 0.5 mA。低电流时 R=V/I 对噪声更敏感，因此 50 mA 档负载显示波动大于高电

流档。

图 7 连续采样稳定性

图 8 负载阻值显示稳定性

### 8.7 负载适应能力

测试覆盖短路、低阻负载以及约 50 Ω 高阻负载。短路时模拟环维持限流；负载升高时，Buck 前馈根据 I_set(R_load+R_s)+1.5V 提高 VOUT+，避免 MOS 压差不足。连续记录中 50 mA、250 mA 和 500 mA

三档均在约 50 Ω 负载附近保持稳定输出，说明系统可覆盖题目规定的高阻端工况。

负载调整率的测试方法为在固定 I_set 下连续改变负载，并计算：

SL =

Imax − Imin

Iset

× 100%

最终功能测试中，短路限流、高阻输出和负载变化均能正常工作。完整逐点扫负载记录可在终测时继续

补充，用于替换为更细化的量化曲线。

### 8.8 Buck 自动调压和 MOS 余量

早期固定 DAC1 时，部分中高电流、高阻工况的 V_MOS 仅为 0.18～0.62 V，恒流环接近压差不足；500 mA

工况将 VOUT+ 提高至约 27.724 V 后，V_MOS 恢复至约 1.90 V。最终代码根据负载估计和设定电流每约 1 s

计算一次 VOUT+ 目标，使 MOS 获得约 1.5 V 设计余量，并避免低阻负载时承担不必要的功耗。

### 8.9 纹波测试

早期在 50 mA 档使用普通示波器探头得到约 5 mVpp 的读数。该结果混入长地线环路、Buck 高频尖峰和示

波器噪声底，不能直接等同于真实低频电流纹波。题目所要求的 0.2 mA 对 2 Ω 采样电阻仅对应 0.4 mVpp，

应使用短地弹簧、AC 耦合、20 MHz 限带，并首先测量噪声底。项目已完成测量链路分析，后续可使用差分

探头或低噪声前置放大器提高毫伏以下测量可信度。

### 9 误差分析

### 9.1 DAC 量化与增益误差

MCP4822 为 12 位 DAC。量化、内部基准和通道增益误差使软件命令值与实际输出存在差异。测试中

DAC2_meas→I_meas 的 RMSE 仅为 0.041 mA，而 DAC2_cmd→I_meas 的 RMSE 为 0.361 mA，说明模拟恒

流内环的本征误差很小，主要固定误差出现在 DAC 命令到实际参考电压的链路中。

### 9.2 采样电阻误差与温升

实际器件为 PZWR0005B2R00A9 精密绕线电阻，标称 2 Ω、±0.1%、5 W。500 mA 时功耗为：

### PR = I²R = 0.5² × 2 = 0.5W

额定功率约为实际最大耗散的 10 倍，可降低温升引起的阻值漂移，并提高短路限流状态下的可靠性。绕

线电阻存在寄生电感，但本项目输出为直流、控制带宽较低，其影响远小于阻值精度、布线和地参考误差。

### 9.3 运放和 MOS 误差

OPA197 输入失调会等效叠加到采样电压上；对 2 Ω 采样电阻而言，100 μV 对应约 0.05 mA。MOS 阈值和

跨导变化不会直接决定闭环稳态电流，但会影响运放输出范围、动态响应和低压差可控能力。

### 9.4 ADC、参考电压与分压误差

STM32 ADC 的量化误差、3.3 V 参考偏差、分压器实际比例、采样时间和通道串扰都会影响 VOUT 与

Vsense。VOUT 需要约 11 倍还原，因此 ADC 端的微小偏差会被同步放大。VOUT+、VOUT− 分别标定可

补偿两个通道的器件和布线差异。

### 9.5 接地、线束与接触误差

功率地存在 Buck、MOS 和负载回流，如果 ADC/DAC 参考与功率回路共用较长路径，地电位差会表现为电

流零点和显示误差。系统采用 AGND/GND 单点连接、ADC_REF_GND 独立回流和采样线独立引出。

跨板调试中还验证了线束质量的重要性：散装杜邦线的长度、接触电阻和回路面积不一致，会使 ADC

跨板信号波动；固定压接排线、信号与参考地相邻、减少插拔和悬空连接后，稳定性明显改善。因此连接器、

排针焊点和线束接触均属于误差链的一部分。

### 9.6 Buck 余量误差

负载估计不准或 Buck 更新不及时会使 V_MOS 偏离设计值。压差过小时恒流环可能饱和，压差过大时 MOS

发热增加。最终代码使用约 1 s 周期的负载前馈，避免 DAC1 高频动作扰动电流；负载突变后的短时间内则

由模拟恒流环利用原有余量保持输出。

### 9.7 低电流相对误差

在 10～20 mA 区间，即使绝对误差只有 0.1～0.2 mA，相对误差也会显著增大。ADC 零点、运放失调、仪

表分辨率和跨板地差在该区间占比更高。因此系统采用零点门限、滤波和多点标定后的残差补偿，而不将低电

流误差简单归结为一个全量程比例系数。

### 9.8 测试仪器和方法误差

电流表会引入额外内阻和保险丝接触电阻；功率电阻实际值随温度变化；普通示波器探头在毫伏级测量时容

易拾取地线环路噪声。测试时应固定仪表档位、线束和等待时间，并明确区分电流表实测值、ADC 显示值与

理论计算值。

### 9.9 误差链总结

综合测试表明，误差贡献大致为：

DAC 命令与实际电压差异、ADC 与地参考误差

> 采样电阻温漂、线束与仪表误差

> 模拟恒流内环的本征线性误差

因此系统采用“高线性模拟内环 + 数字标定和慢速修正”的结构：软件补偿的是稳定、可重复的系统偏

差，而不是替代硬件闭环。

### 10 总结与展望

本项目完成了一套覆盖原理图、PCB、嵌入式固件、人机界面、数据标定和外壳结构的高精度数控恒流源。系

统采用可调 Buck 与线性恒流环结合的结构：OPA197、MOS 和 2 Ω 精密采样电阻承担快速恒流，STM32 和

MCP4822 完成数字设定、PI 修正以及 Buck 供电余量管理，从而兼顾输出精度、负载范围和功率器件温升。

测试表明，模拟恒流链的电压—电流斜率与理论值接近，连续显示标准差小于 0.5 mA；系统能够完成

0～500 mA 调节、高阻负载输出、短路限流、开路报警和过流关断。串口屏不仅显示数值和状态，还实时绘

制目标电流与实际电流双通道波形；三维外壳方案进一步考虑了屏幕开窗、操作面板、功率器件散热、双板支

撑和线束检修。

项目调试经历了电源反馈开路、DAC 方案更换、模拟节点悬浮、焊点接触、跨板 ADC 线束干扰以及多

环职责划分等问题。通过分模块上电、逐节点测量、多点仪表对比和软件重构，最终形成了可运行、可测量、

可展示的完整系统。

后续可从以下方面继续提升：

1. 使用独立精密基准和外置高分辨率 ADC，提高低电流绝对精度；
2. 对采样电阻实施更严格的 Kelvin 四线连接，并使用定制屏蔽线束；
3. 在保持 Buck 低速稳定的前提下，改善负载阶跃后的余量恢复速度；
4. 使用低噪声差分测量链，对 0.2 mA 纹波指标进行高置信度验证；
5. 完成外壳实物打印、热测试和长时间运行验证；
6. 增加参数保存、上位机记录和自动化测试功能。

总体而言，系统实现了题目要求的数控恒流、参数测量、自动供电余量调节和安全保护，具有较好的完

整性、可扩展性和工程实践价值。

附录 A 关键控制公式汇总

项目 | 公式

DAC2 理论电流 Iout_mA≈0.496715×DAC2_meas_mV

DAC2 实测关系 I_meas_mA=0.497253×DAC2_meas_mV−0.029041

DAC2 命令前馈 DAC2_cmd_mV=(I_set_mA−1.368386)/0.498188

电流基础校准 | I_base=0.98189×I_raw+0.004821 A
VOUT+ 校准 | VOUTP_cal=0.98663×VOUTP_raw+0.13675 V
VOUT− 校准 | VOUTN_cal=0.97992×VOUTN_raw+0.24886 V
负载电压 | Vload=VOUTP_cal−VOUTN_cal
负载阻值 | Rload=Vload/I_disp
MOS 压差 | VMOS=VOUTN_cal−Vsense
Buck 目标 | VOUTP_target=I_set×(Rload+2Ω)+1.5V
DAC1 反算 | DAC1=(VOUTP_target+1.797554)/10.012879
MOS 功耗 | PMOS=VMOS×Iout
纹波换算 | Iripple_pp=Vpp/Rs

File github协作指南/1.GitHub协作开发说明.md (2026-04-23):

# GitHub 协作开发说明

## 适用场景
这份说明分成两部分：

1. 仓库拥有者如何把队友加入协作
2. 队友如何在本地使用 Git 参与开发

---

## 推荐协作方式

对于小团队比赛项目，最简单稳定的方式是：

1. 作为仓库拥有者，在 GitHub 上把队友加入仓库协作者
2. 每个队友把仓库克隆到自己电脑
3. 每个人先同步最新代码，再修改，再提交，再推送
4. 尽量做到“一个人负责一部分内容”，减少同时修改同一个文件

如果项目规模还不大，这种方式已经够用了，不一定一开始就上复杂的分支管理流程。

---

## 仓库拥有者如何邀请队友加入协作

### 1. 进入仓库页面

打开 GitHub 仓库页面：

`https://github.com/sysuwilliam/NC-Current-Source`

### 2. 打开仓库设置

在仓库页面上方找到：

`Settings`

### 3. 找到协作者管理入口

在左侧菜单中找到类似下面的入口：

`Collaborators`

有时它会出现在：

`Settings -> Collaborators and teams`

### 4. 邀请队友

点击：

`Add people`

然后输入队友的 GitHub 用户名，发送邀请。

### 5. 队友接受邀请

队友需要登录 GitHub，在通知或邮箱中接受邀请。接受之后，他们就能向这个仓库直接推送代码。

---

## 每个队友开始前要准备什么

每个队友本地电脑需要准备：

1. 一个 GitHub 账号
2. 已安装 Git
3. 能正常登录 GitHub
4. 本地有一个用于存放项目的文件夹

### 检查 Git 是否安装成功

在终端中输入：

```bash
git --version
```

如果能看到版本号，就说明 Git 已安装。

---

## 首次把仓库下载到本地

### 方式 1：使用 SSH 克隆

如果已经配置好 SSH key，执行：

```bash
git clone git@github.com:sysuwilliam/NC-Current-Source.git
```

### 方式 2：使用 HTTPS 克隆

如果还没配置 SSH，也可以执行：

```bash
git clone https://github.com/sysuwilliam/NC-Current-Source.git
```

### 进入项目目录

```bash
cd NC-Current-Source
```

---

## 第一次配置自己的 Git 身份

每个队友第一次使用 Git 时，建议先配置用户名和邮箱：

```bash
git config --global user.name "你的名字"
git config --global user.email "你的GitHub邮箱"
```

例如：

```bash
git config --global user.name "Liu Xinya"
git config --global user.email "example@qq.com"
```

这样以后每次提交，都会记录是谁提交的。

---

## 日常协作的标准流程

以后每次开发，建议都按这个顺序：

1. 先进入项目目录
2. 先拉取最新代码
3. 再开始修改
4. 修改后查看变更
5. 提交到本地仓库
6. 推送到 GitHub

对应命令如下：

```bash
git pull origin main
```

修改文件后：

```bash
git status
git add .
git commit -m "写清楚这次改了什么"
git push origin main
```

---

## 每条命令是什么意思

### 1. `git status`

查看当前有哪些文件被修改、哪些文件还没有加入暂存区。

```bash
git status
```

### 2. `git add .`

把当前目录下修改过的文件加入暂存区，准备提交。

```bash
git add .
```

如果不想一次加入所有文件，也可以单独加入某个文件：

```bash
git add README.md
```

### 3. `git commit -m "..."`

把这次修改正式记录到本地 Git 历史中。

```bash
git commit -m "完成串口调试框架"
```

提交信息要尽量具体，不要只写“修改了一下”。

### 4. `git push origin main`

把本地提交推送到 GitHub 远程仓库。

```bash
git push origin main
```

### 5. `git pull origin main`

把 GitHub 上最新的代码拉到本地，并合并进当前分支。

```bash
git pull origin main
```

---

## 8建议遵守的协作习惯

### 1. 开始写代码前先 `pull`

不要一上来就改。先执行：

```bash
git pull origin main
```

这样可以减少冲突。

### 2. 一次只做一类修改

例如这次只改：

- 串口通信
- ADC 采样
- LCD 显示
- 文档说明

不要把很多无关内容混在一个提交里。

### 3. 提交信息写清楚

推荐写法：

```bash
git commit -m "新增电流设定串口指令解析"
git commit -m "修复 ADC 采样值缩放错误"
git commit -m "补充硬件连接说明文档"
```

### 4. 尽量避免多人同时改同一个文件

比如：

- 一个人负责 `README`
- 一个人负责控制算法
- 一个人负责显示或调试模块

这样最省事。

---

## 如果推送失败怎么办

最常见的原因是：你本地代码不是最新的，别人已经先推送了。

这时通常会提示你先拉取远程更新。

解决步骤：

```bash
git pull origin main
```

如果没有冲突，拉完之后再执行：

```bash
git push origin main
```

---

## 如果出现冲突怎么办

冲突的典型场景是：

1. 你修改了某个文件
2. 队友也修改了同一个文件的同一部分
3. 你执行 `git pull` 时，Git 不知道该保留谁的内容

### 冲突时 Git 会在文件里标出内容

文件中可能会出现类似内容：

```text
<<<<<<< HEAD
这是你的修改
=======
这是队友的修改
>>>>>>> 分支信息
```

### 解决方法

1. 打开冲突文件
2. 手动决定保留哪些内容
3. 删除 `<<<<<<<`、`=======`、`>>>>>>>` 这些标记
4. 保存文件
5. 重新提交

命令一般是：

```bash
git add .
git commit -m "解决合并冲突"
git push origin main
```

## 最小命令集合

```bash
git clone 仓库地址
cd 仓库目录
git pull origin main
git status
git add .
git commit -m "本次修改说明"
git push origin main
```

---

## 如何查看历史记录

### 查看提交记录

```bash
git log --oneline
```

这样可以快速看到谁提交了什么。

### 查看具体改动

```bash
git diff
```

这个命令可以查看当前还没提交的修改。

---

## 如果误操作了怎么办

### 场景 1：文件改乱了，但还没提交

先不要慌，可以先用：

```bash
git status
```

看看哪些文件被改了。

### 场景 2：已经提交了，但还没推送

先找队友或你确认一下，再处理。因为 Git 的撤销方式很多，操作不当可能会把内容弄丢。

### 建议

对于新手，遇到不确定的情况时，不要随便执行危险命令，例如：

```bash
git reset --hard
git clean -fd
```

这类命令可能直接删除本地修改。

---

## 推荐的实际上手流程

你可以把下面这段直接发给队友：

### 队友加入项目步骤

1. 注册并登录 GitHub
2. 把 GitHub 用户名发给队长
3. 接受仓库协作邀请
4. 安装 Git
5. 执行 `git clone` 把仓库拉到本地
6. 进入项目目录后先执行 `git pull origin main`
7. 修改自己负责的内容
8. 执行 `git add .`
9. 执行 `git commit -m "说明本次修改"`
10. 执行 `git push origin main`

---

## 总结

对你们现在这个仓库，最实用的协作方案就是：

1. 先把队友加成 Collaborator
2. 队友克隆仓库到本地
3. 每次开发前先 `pull`
4. 每次开发后 `commit` 和 `push`
5. 尽量按模块分工，减少同时修改同一个文件
6. 后期代码复杂后，再逐步切换到“功能分支 + Pull Request”模式

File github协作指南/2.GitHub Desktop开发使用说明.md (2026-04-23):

# GitHub Desktop 开发使用说明

## 推荐使用github desktop，图形化界面易操作

GitHub Desktop 是 GitHub 官方提供的桌面客户端，适合团队协作项目的日常开发。

---

## 先说一个很重要的点

根据 GitHub 官方文档当前说明，**GitHub Desktop 连接 GitHub 时使用的是 HTTPS 认证方式**，而不是直接按命令行里常见的 SSH 工作。

官方说明页：

- [About connections to GitHub in GitHub Desktop](https://docs.github.com/en/desktop/installing-and-authenticating-to-github-desktop/about-connections-to-github-in-github-desktop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)

这意味着：

1. 如果你主要使用 GitHub Desktop，推荐直接登录 GitHub 账号，让 Desktop 帮你完成认证
2. 不建议把“命令行 SSH 工作流”和“GitHub Desktop 工作流”混着理解
3. 如果某个仓库最初是用 SSH 克隆的，GitHub 官方文档提醒你在 GitHub Desktop 中可能会遇到连接问题

所以对这个项目，**如果队友准备用 GitHub Desktop 参与开发，推荐优先使用 GitHub Desktop 自己的登录与克隆流程**。

---

## GitHub Desktop 能帮你做什么

用 GitHub Desktop，队友一般可以完成下面这些事：

1. 登录自己的 GitHub 账号
2. 克隆你们的仓库到本地
3. 查看文件改动
4. 创建分支
5. 提交代码
6. 拉取远程更新
7. 推送自己的修改
8. 发起 Pull Request

对于比赛项目的日常协作，这些功能已经很够用了。

---

## 安装 GitHub Desktop

官方下载地址：

- [GitHub Desktop Download](https://desktop.github.com/download/)

下载安装后，打开 GitHub Desktop。

---

## 五、第一次登录 GitHub 账号

第一次使用时，先登录自己的 GitHub 账号。

操作路径：

`File -> Options`

然后在 `Accounts` 页面点击登录按钮。

官方文档：

- [Getting started with GitHub Desktop](https://docs.github.com/en/desktop/overview/getting-started-with-github-desktop?platform=windows)

官方截图：

GitHub Desktop 登录界面

登录成功后，GitHub Desktop 会和你的 GitHub 账号关联，后续克隆、拉取、推送会更顺畅。

---

## 把仓库克隆到本地

对于项目，推荐两种方式。

### 方式 1：在 GitHub 网页中打开仓库，再用 GitHub Desktop 克隆

进入仓库主页后，点击绿色的 `Code` 按钮。

官方截图：

GitHub 仓库页面中的 Code 按钮

然后点击 `Open with GitHub Desktop`。

官方截图：

从 GitHub 网页用 GitHub Desktop 打开仓库

之后 GitHub Desktop 会弹出克隆窗口，让你选择本地保存位置。

官方文档：

- [Cloning a repository from GitHub to GitHub Desktop](https://docs.github.com/en/desktop/adding-and-cloning-repositories/cloning-a-repository-from-github-to-github-desktop)

### 方式 2：直接在 GitHub Desktop 里克隆

在 GitHub Desktop 中点击：

`File -> Clone repository`

官方截图：

GitHub Desktop 中的 Clone repository 菜单

接着在弹出的窗口中选择仓库并设置本地路径。

官方截图：

GitHub Desktop 的克隆仓库窗口

官方文档：

- [Cloning and forking repositories from GitHub Desktop](https://docs.github.com/en/desktop/adding-and-cloning-repositories/cloning-and-forking-repositories-from-github-desktop)

---

## 开始开发前先同步最新代码

每次开始工作前，建议先检查远程有没有新内容。

在 GitHub Desktop 顶部会看到 `Fetch origin` 按钮。

官方截图：

Fetch origin 按钮

点击后，如果远程有更新，通常会变成 `Pull origin`，这时再把更新拉下来。

官方文档：

- [Syncing your branch in GitHub Desktop](https://docs.github.com/en/desktop/working-with-your-remote-repository-on-github-or-github-enterprise/syncing-your-branch-in-github-desktop)

建议养成习惯：

1. 打开项目先点一次 `Fetch origin`
2. 如果有更新，再执行 `Pull origin`
3. 同步完成后再开始写代码

---

## 修改文件时，GitHub Desktop 会自动显示改动

真正编辑文件一般不在 GitHub Desktop 里做，而是在：

- VS Code
- Keil
- 记事本
- 其他你熟悉的编辑器

你只需要保存文件，GitHub Desktop 就会自动检测到变更。

左侧 `Changes` 面板会列出被修改的文件。

官方截图：

Changes 面板会显示改动文件

你可以：

1. 查看哪些文件被改了
2. 勾选这次想提交的文件
3. 不勾选暂时不想提交的内容

官方文档：

- [Committing and reviewing changes to your project in GitHub Desktop](https://docs.github.com/en/desktop/making-changes-in-a-branch/committing-and-reviewing-changes-to-your-project-in-github-desktop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)

---

## 写提交信息并提交

当你确认改动没问题后，在 GitHub Desktop 左下角填写提交信息：

- `Summary`：简短说明这次改了什么
- `Description`：可选，补充更多细节

推荐写法：

- `新增串口调试指令解析`
- `修复 ADC 采样缩放问题`
- `补充项目协作说明文档`

不推荐写法：

- `update`
- `改了`
- `123`

填写后点击 `Commit to 当前分支名`。

这一步只是提交到**本地仓库**，还没有上传到 GitHub。

---

## 把本地提交推送到 GitHub

本地提交后，顶部一般会出现 `Push origin` 或 `Publish branch`。

### 如果这是已有远程分支

点击 `Push origin` 即可把提交推到 GitHub。

官方截图：

Push origin 按钮

### 如果这是你新建的本地分支，远程还没有

先点击 `Publish branch`，把这个分支发布到 GitHub。

官方截图：

Publish branch 按钮

只有分支先发布到 GitHub，队友和网页端才能看到它。

---

## 日常开发的完整流程

下面这套流程最适合你们现在这个项目。

### 每次开始开发

1. 打开 GitHub Desktop
2. 选中项目仓库
3. 确认当前仓库正确
4. 点击 `Fetch origin`
5. 如果有更新，点击 `Pull origin`
6. 确认自己在正确分支上
7. 如果要做新功能，创建新分支

### 开发中

1. 用编辑器修改代码
2. 回 GitHub Desktop 查看变更
3. 检查这次改动是否合理
4. 填写提交信息
5. 点击 `Commit to ...`

### 开发后

1. 点击 `Push origin` 或 `Publish branch`
2. 如果是功能分支，发起 Pull Request
3. 通知队友你已经提交了什么内容

---

## 这个仓库如何用 GitHub Desktop 加入协作

你们当前仓库是：

- [NC-Current-Source](https://github.com/sysuwilliam/NC-Current-Source)

队友加入协作的推荐步骤如下：

1. 先接受你的 GitHub 仓库协作邀请
2. 安装 GitHub Desktop
3. 登录自己的 GitHub 账号
4. 在仓库网页点击 `Code -> Open with GitHub Desktop`
5. 把仓库克隆到本地
6. 每次开发前先 `Fetch` / `Pull`
7. 开新分支开发
8. 提交后 `Push` / `Publish branch`
9. 发起 Pull Request

---

## 使用 GitHub Desktop 时的注意事项

### 1. 开发前先同步

不要一打开仓库就直接改，先看远程有没有更新。

### 2. 尽量按模块分支开发

不要所有人一直直接在 `main` 上写。

### 3. 提交信息写清楚

这样以后回顾历史非常省事。

### 4. 改核心文件前先在群里说一声

比如：

- 主流程
- 协议定义
- 硬件接口
- 公共头文件

这些内容多人同时改时最容易冲突。

### 5. 不懂冲突时先别乱点

如果 GitHub Desktop 提示冲突，先找队友确认一下要保留哪部分内容，不要盲目覆盖。

---

## 最简工作流

如果只记最少步骤，可以记下面这套：

1. 打开 GitHub Desktop
2. 选中仓库
3. 点 `Fetch origin`
4. 有更新就点 `Pull origin`
5. 新建分支
6. 改文件
7. 回 GitHub Desktop 查看改动
8. 写提交说明并 `Commit`
9. 点击 `Push origin` 或 `Publish branch`
10. 需要合并时发 Pull Request

---

## 官方资料入口

- [GitHub Desktop 下载页](https://desktop.github.com/download/)
- [GitHub Desktop Getting started](https://docs.github.com/en/desktop/overview/getting-started-with-github-desktop?platform=windows)
- [Cloning and forking repositories from GitHub Desktop](https://docs.github.com/en/desktop/adding-and-cloning-repositories/cloning-and-forking-repositories-from-github-desktop)
- [Cloning a repository from GitHub to GitHub Desktop](https://docs.github.com/en/desktop/adding-and-cloning-repositories/cloning-a-repository-from-github-to-github-desktop)
- [Managing branches in GitHub Desktop](https://docs.github.com/en/desktop/making-changes-in-a-branch/managing-branches-in-github-desktop)
- [Committing and reviewing changes to your project in GitHub Desktop](https://docs.github.com/en/desktop/making-changes-in-a-branch/committing-and-reviewing-changes-to-your-project-in-github-desktop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)
- [Syncing your branch in GitHub Desktop](https://docs.github.com/en/desktop/working-with-your-remote-repository-on-github-or-github-enterprise/syncing-your-branch-in-github-desktop)
- [Creating an issue or pull request from GitHub Desktop](https://docs.github.com/en/desktop/working-with-your-remote-repository-on-github-or-github-enterprise/creating-an-issue-or-pull-request-from-github-desktop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)
- [About connections to GitHub in GitHub Desktop](https://docs.github.com/en/desktop/installing-and-authenticating-to-github-desktop/about-connections-to-github-in-github-desktop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)

---

## 总结

最推荐的使用方式是：

1. 登录 GitHub Desktop
2. 用官方流程克隆仓库
3. 每次先同步
4. 每次在分支上开发
5. 改完提交并推送
6. 通过 Pull Request 合并到主分支

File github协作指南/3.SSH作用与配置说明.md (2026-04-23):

# SSH 作用与配置说明

## 为什么要写这份说明

在 GitHub 协作开发中，大家经常会看到两种仓库地址：

1. HTTPS
2. SSH

例如同一个仓库，可能会有下面两种写法：

### HTTPS 地址

```text
https://github.com/sysuwilliam/NC-Current-Source.git
```

### SSH 地址

```text
git@github.com:sysuwilliam/NC-Current-Source.git
```

很多刚接触 Git 的同学会疑惑：

- SSH 是干什么的？
- 为什么有些人推荐用 SSH？
- 配 SSH 会不会很麻烦？
- 我到底该用 HTTPS 还是 SSH？

这份文档就是专门解释这些问题的。

---

## SSH 到底是什么

SSH 的全称是：

`Secure Shell`

它本来是一种安全连接远程主机的协议。在 GitHub 场景里，我们主要把它理解成：

**一种让你的电脑能够安全地向 GitHub 证明“你是谁”的身份验证方式。**

你可以把 SSH 理解成一把“数字钥匙”：

1. 你的电脑本地保存一把私钥
2. GitHub 账号中保存对应的公钥
3. 当你向 GitHub 推送代码时，GitHub 会验证这两把钥匙是否匹配
4. 匹配成功，就允许你访问和推送

所以 SSH 的核心作用不是“下载更快”，而是：

**更方便、更稳定地完成身份认证。**

---

## SSH 在 GitHub 协作中的作用

在团队协作里，SSH 主要有下面几个作用。

### 1. 免去频繁输入账号密码

如果使用 HTTPS，有时在 `git push` 时需要输入 GitHub 账号、Token 或走浏览器授权。

如果使用 SSH，配置好之后，通常不需要每次手动输入认证信息。

### 2. 适合长期开发协作

因为你们不是只提交一次，而是会持续地：

- 拉取代码
- 提交代码
- 推送代码
- 同步仓库

这种长期协作场景下，SSH 会更省事。

### 3. 让每个人的电脑拥有自己的访问身份

每个队友都可以在自己的电脑上生成一对 SSH key，并把公钥绑定到自己的 GitHub 账号。

这样 GitHub 能知道是谁在操作仓库。

### 4. 方便和 Git 命令行配合

对于经常使用终端、VS Code、CLion、Keil 配套 Git 插件的人来说，SSH 通常体验更顺。

---

## SSH 和 HTTPS 的区别

### HTTPS 的特点

优点：

1. 不需要提前配置 SSH key
2. 上手最简单
3. 复制仓库地址就能直接克隆

缺点：

1. 推送时代码认证可能稍麻烦
2. 可能需要 Token、网页登录或额外认证步骤

### SSH 的特点

优点：

1. 配好之后长期使用很方便
2. 推送和拉取更顺畅
3. 更适合经常协作开发

缺点：

1. 第一次配置会比 HTTPS 多几步
2. 需要理解公钥和私钥的概念

### 建议

如果只是临时看一下仓库，HTTPS 足够。

如果是要长期参与这个比赛项目，建议配置 SSH。

---

## 公钥和私钥分别是什么

配置 SSH 时，通常会生成两个文件：

1. 公钥
2. 私钥

### 私钥

私钥保存在你自己的电脑里，**绝对不能发给别人**。

它相当于你家的钥匙本体。

### 公钥

公钥可以上传到 GitHub。

它相当于告诉 GitHub：“以后拿着对应私钥的人，就是我这台电脑。”

### 一定要记住

1. 公钥可以上传
2. 私钥不能泄露
3. 私钥丢了或者怀疑泄露，就重新生成一对新的 key

---

## Windows 上配置 SSH 的完整流程

下面以 Windows 为例说明，适合你们当前环境。

---

## 第一步：检查电脑是否已经有 SSH key

打开 PowerShell 或 Git Bash，输入：

```bash
Get-ChildItem ~/.ssh
```

如果你看到类似文件：

```text
id_rsa
id_rsa.pub
```

或者：

```text
id_ed25519
id_ed25519.pub
```

说明电脑上可能已经有 SSH key 了。

其中：

- 没有 `.pub` 后缀的是私钥
- 有 `.pub` 后缀的是公钥

如果目录不存在或者没有这些文件，也没关系，直接生成新的就行。

---

## 第二步：生成新的 SSH key

现在 GitHub 更推荐使用 `ed25519` 算法。

在终端中输入：

```bash
ssh-keygen -t ed25519 -C "你的GitHub邮箱"
```

例如：

```bash
ssh-keygen -t ed25519 -C "example@qq.com"
```

执行后一般会看到提示：

```text
Enter file in which to save the key (...)
```

这时直接按回车，使用默认路径即可。

然后还会提示你输入密码：

```text
Enter passphrase (empty for no passphrase):
```

这里有两种选择：

### 方式 1：直接回车，不设置密码

优点：

1. 使用方便
2. 每次认证更省事

缺点：

1. 如果电脑本身安全性不足，私钥泄露风险更大

### 方式 2：设置一个 SSH key 密码

优点：

1. 更安全

缺点：

1. 使用时可能需要额外输入密码

对于比赛项目，如果电脑是自己在用、管理比较稳定，可以不设密码；如果更看重安全，可以设一个。

---

## 第三步：确认生成成功

再次执行：

```bash
Get-ChildItem ~/.ssh
```

如果看到：

```text
id_ed25519
id_ed25519.pub
```

说明生成成功了。

---

## 第四步：查看公钥内容

把公钥内容打印出来：

```bash
Get-Content ~/.ssh/id_ed25519.pub
```

你会看到一长串类似下面的内容：

```text
ssh-ed25519 AAAAC3NzaC1lZDI1NTE5AAAAI...... your_email@example.com
```

这整整一行就是你的公钥。

**复制整行内容，不要漏，不要换行，不要多空格。**

---
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

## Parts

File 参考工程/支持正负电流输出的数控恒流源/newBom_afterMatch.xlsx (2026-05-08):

Comment型号 | Designator位号 | Footprint封装 | Quantity数量 | LCSC Part#嘉立创编号
RED | LED1 | LED0603 | 1 | C2286
GREEN | LED2 | LED0603 | 1 | C72043
10R | R16 | 0603_R | 1 | C22859
LMR14020SDDAR | U1 | HSOIC 8 | 1 | C187824
10uF/50V | C13,C16,C17 | 1210_C | 3 | C18791
AT24C02C-XHM-T | U8 | TSSOP 8 | 1 | C48914
SS34 | D4,D7 | SMA | 2 | C8678
0R | R31 | 1210_R | 1 | C474103
10uF/25V | C8,C21 | 0603_C | 2 | C96446
PTLC03D-B | D8,D9 | SOD-323 | 2 | C492001
FDS6912A | Q2 | SOIC 8 | 1 | C903634
22K 1% | R3 | 0603_R | 1 | C31850
33R | R20,R21,R26,R27 | 0402_R | 4 | C25105
15uH | L1 | LL 7.0x7.0x3.5mm | 1 | C280645
20K 1% | R7 | 0603_R | 1 | C4184
TS5A3159DBVT | U4 | SOT-23(6) | 1 | C2673410
2k 1% | R15 | 0603_R | 1 | C22975
BAT54JFILM | D6 | SOD-323 | 1 | C86299
4K7 1% | R5 | 0603_R | 1 | C23162
3k 1% | R14 | 0603_R | 1 | C4211
1K 1% | R2,R6,R17,R18 | 0603_R | 4 | C21190
10nF/50V | C2,C18 | 0603_C | 2 | C57112
4.7uF/25V | C40 | 0402_C | 1 | C2858031
STM32F103RCT7 | U7 | LQFP64 | 1 | C882165
4.7K | R29,R30 | 0402_R | 2 | C25900
0.1uF/25V | C27,C28,C29,C30,C34,C35,C36,C37,C38,C39,C43 | 0402_C | 11 | C307331
0R | R22 | 0805_R | 1 | C17477
FDS4935A | Q1 | SOIC 8 | 1 | C4355028
ACM4520-231-2P | T1 | ACM4520 | 1 | C94257
10nF/25V | C23 | 0603_C | 1 | C57112
0.15uF/16V | C3,C26 | 0603_C | 2 | C1597
SP3232EEN | U6 | SOIC 16 | 1 | C2904739
10K | R8,R9,R10,R11,R12,R13,R32 | 0603_R | 7 | C25804
1M | R23 | 0402_R | 1 | C26083
LMH6642MF/NOPB | U5 | SOT-23(5) | 1 | C779390
10K | R25 | 0402_R | 1 | C25744
27nF/50V | C15 | 0603_C | 1 | C107086
0.1uF/50V | C31 | 0402_C | 1 | C307331
0.1uF/25V | C7,C9,C10,C19,C20,C22,C24,C25 | 0603_C | 8 | C14663
AMS1117-3.3 | VR1 | SOT 223 | 1 | C6186
5.6K 1% | R1 | 0603_R | 1 | C23189
2R49/1% | R19 | 2512_R | 1 | C2934066
1uF/25V | C42 | 0402_C | 1 | C52923
22uF/25V | C5,C6,C11 | 1210_C | 3 | C52306
10nF/25V | C41 | 0402_C | 1 | C15195
100K | R24,R28 | 0402_R | 2 | C25741
33R | R4 | 0603_R | 1 | C23140
1uF/50V | C4 | 0603_C | 1 | C15849
CD40109BPWR | U2 | TSSOP16 | 1 | C131950
22pF/25V | C32,C33 | 0402_C | 2 | C1555
CSD18534Q5AT | UM1 | VSONP_5X6MM | 1 | C2876531
0.1uF/50V | C1,C12,C14 | 0603_C | 3 | C14663
RC-ML08W330JT | RP1 | 0603x4 | 1 | C169805
DS1133-S60APS | CN1 | 插件 | 1 | C77857
SMBJ3.3A | D5 | SMB | 1 | C2848031
ESK107M1HF12CB | CE3 | 插件,D8xL12mm | 1 | C726178
ECG1EM101E12OTBO | CE2 | 插件,D6.3xL12mm | 1 | C2841690
SMBJ5.0A | D3 | SMB | 1 | C2688164
XXDCELNANF-8MHZ | Y1 | SMD3225-4P | 1 | C367183
CBW100505U301T | L3,L4,L5,L6 | 0402 | 4 | C124086
01EC0623 | CE1 | 插件,D10xL13mm | 1 | C2833296
SMD2920-200C-33V | F1 | 2920 | 1 | C2760298
SS54 | D1 | SMC(DO-214AB) | 1 | C2887445
PZ200V-11-04P | CN2 | 插件,P=2mm | 1 | C541858
SLH1207S330MTT | L2 | SMD | 1 | C181844
SMBJ28A | D2 | SMB(DO-214AA) | 1 | C693513
4D03WGJ0472T5E | RP2 | 0603x4 | 1 | C1980
DAC8562SDSCR | U3 | WSON 10 | 1
HR10G-7R-6SB/DNP | CN3 | HR10G-7R-6SB | 1
EDGR-3.81-2P/DNP | J1 | EDGR-3.81-2P | 1
LMR14203XM/LMR16006XD | UP1 | SOT-23(6) | 1

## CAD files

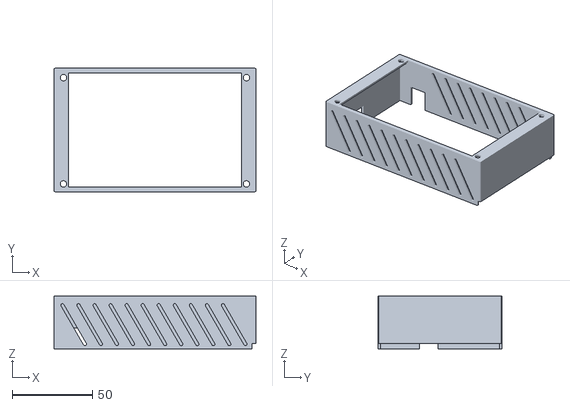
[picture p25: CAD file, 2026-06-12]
外壳/3DShell_上壳_T.stl
125.8 x 76.9 x 33.0

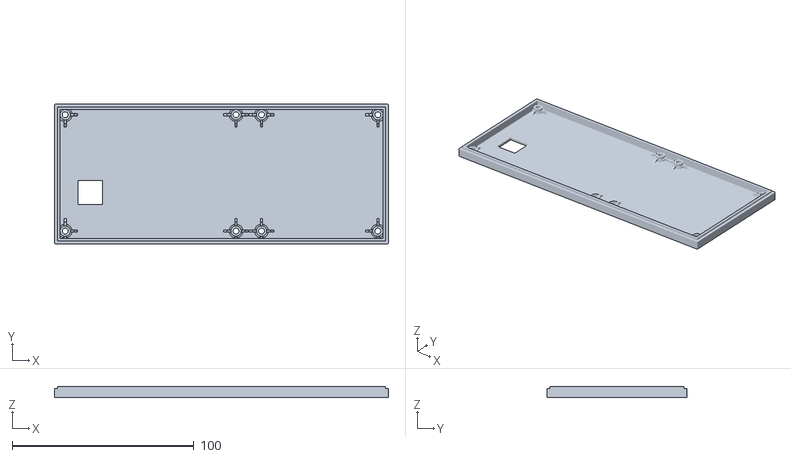
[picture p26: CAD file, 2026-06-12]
外壳/3DShell_下壳_B.stl
183.7 x 76.9 x 6.20

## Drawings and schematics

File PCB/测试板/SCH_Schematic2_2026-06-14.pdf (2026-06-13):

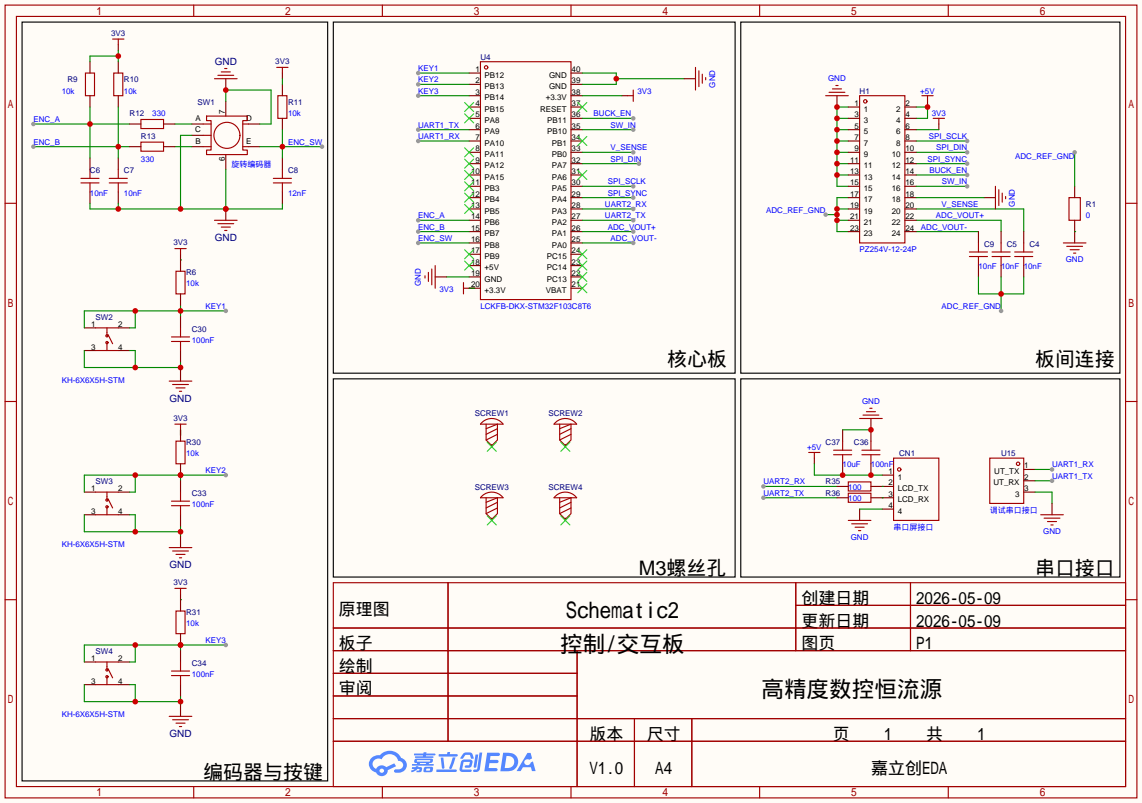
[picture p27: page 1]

原理图 | Schematic2 | 创建日期 | 2026-05-09

更新日期 | 2026-05-09

板子 | 控制/交互板 | 图页 | P1
绘制 | | 高精度数控恒流源
审阅

V1.0 | A4 | 嘉立创EDA

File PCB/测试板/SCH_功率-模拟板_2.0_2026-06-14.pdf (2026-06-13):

固定BUCK降压到5V | 输入模块

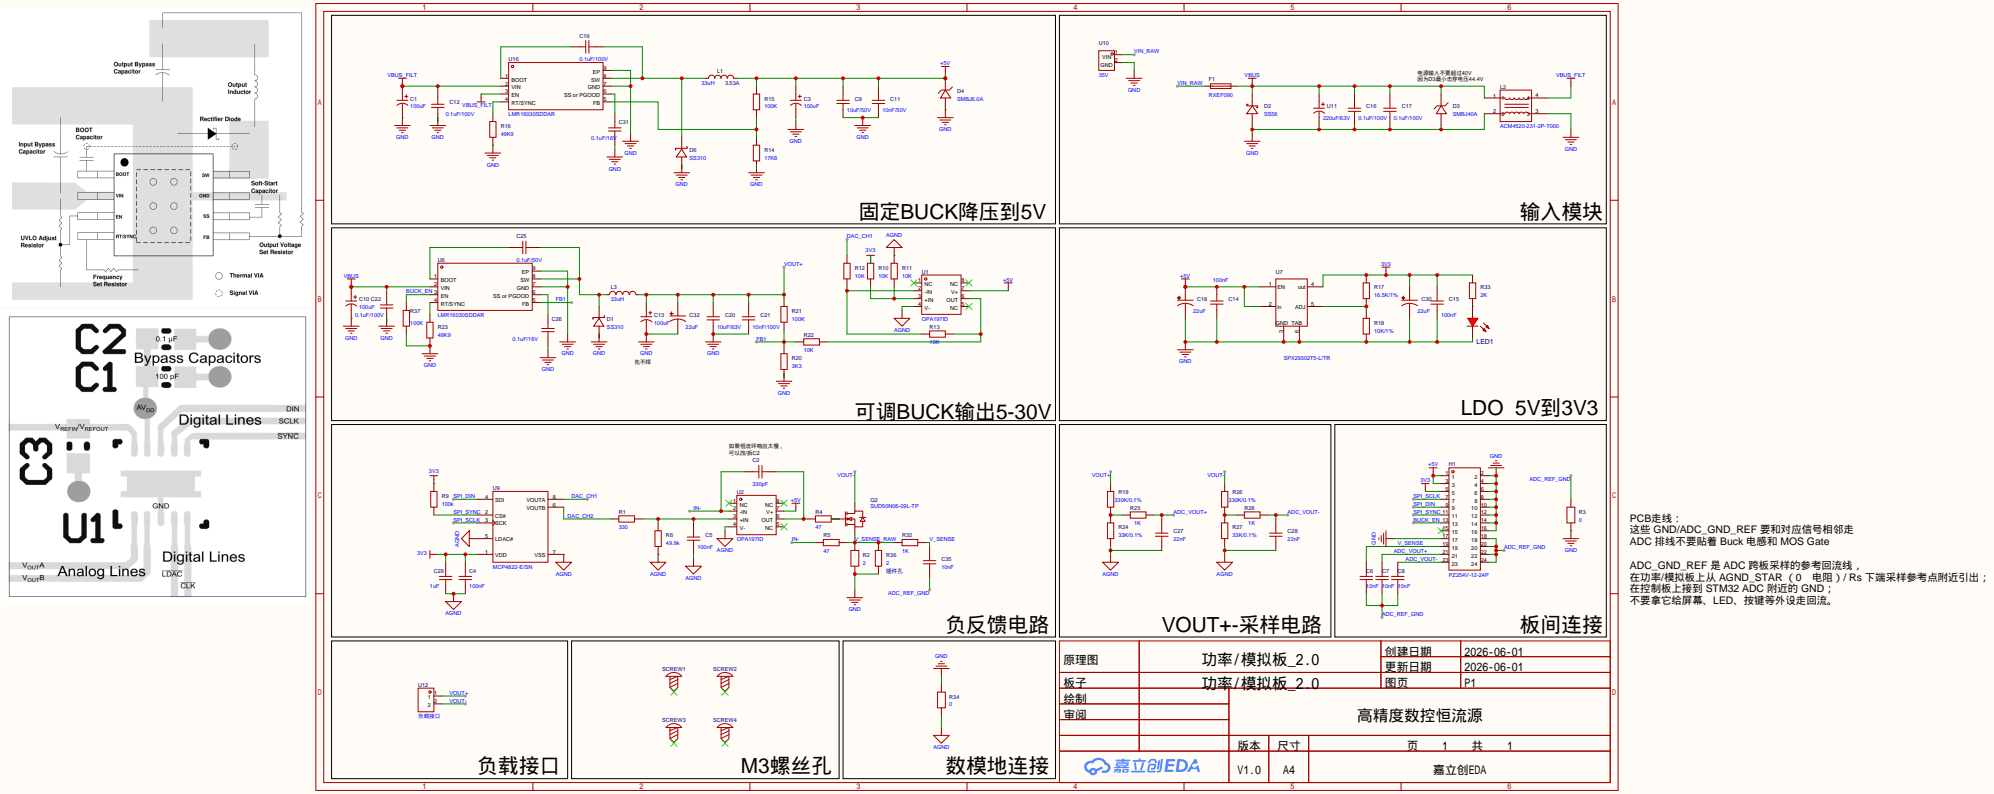
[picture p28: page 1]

PCB走线：
这些 GND/ADC_GND_REF 要和对应信号相邻走
ADC 排线不要贴着 Buck 电感和 MOS Gate
ADC_GND_REF 是 ADC 跨板采样的参考回流线，

在功率/模拟板上从 AGND_STAR （0Ω电阻）/ Rs 下端采样参考点附近引出；
在控制板上接到 STM32 ADC 附近的 GND；
不要拿它给屏幕、LED、按键等外设走回流。

原理图 | 功率/模拟板_2.0 | 创建日期 | 2026-06-01
板子 | 功率/模拟板_2.0 | 图页 | P1
绘制 | | 高精度数控恒流源
审阅

更新日期 | 2026-06-01

V1.0 | A4 | 嘉立创EDA

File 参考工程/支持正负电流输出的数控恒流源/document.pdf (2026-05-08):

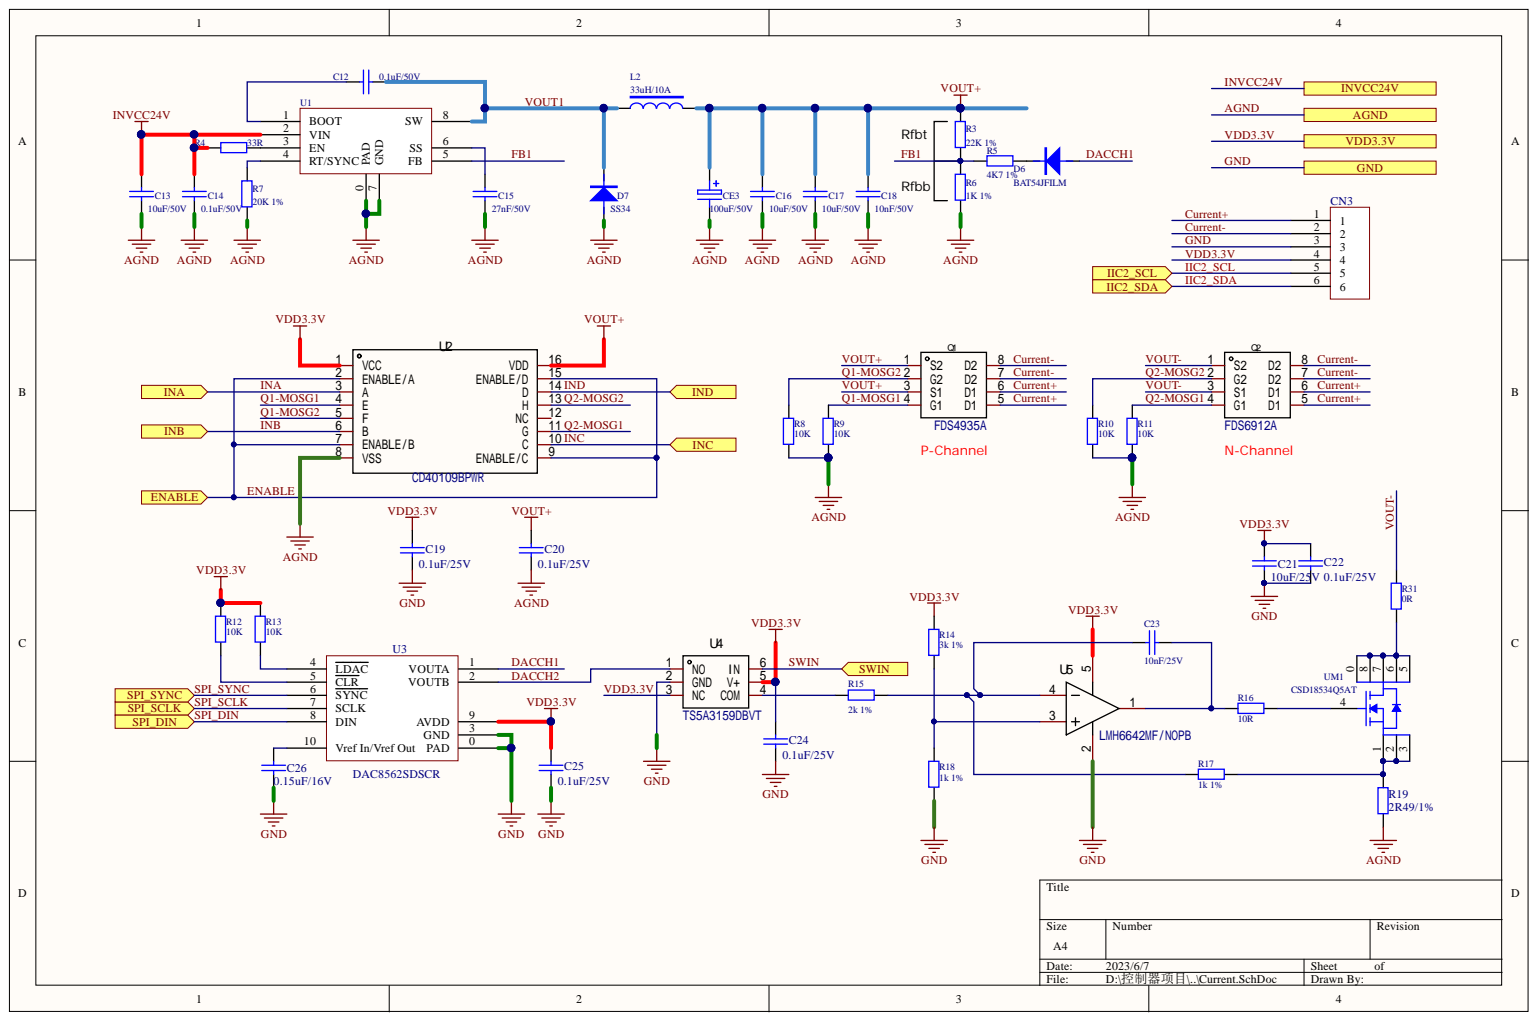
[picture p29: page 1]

Vref In/Vref Out 10

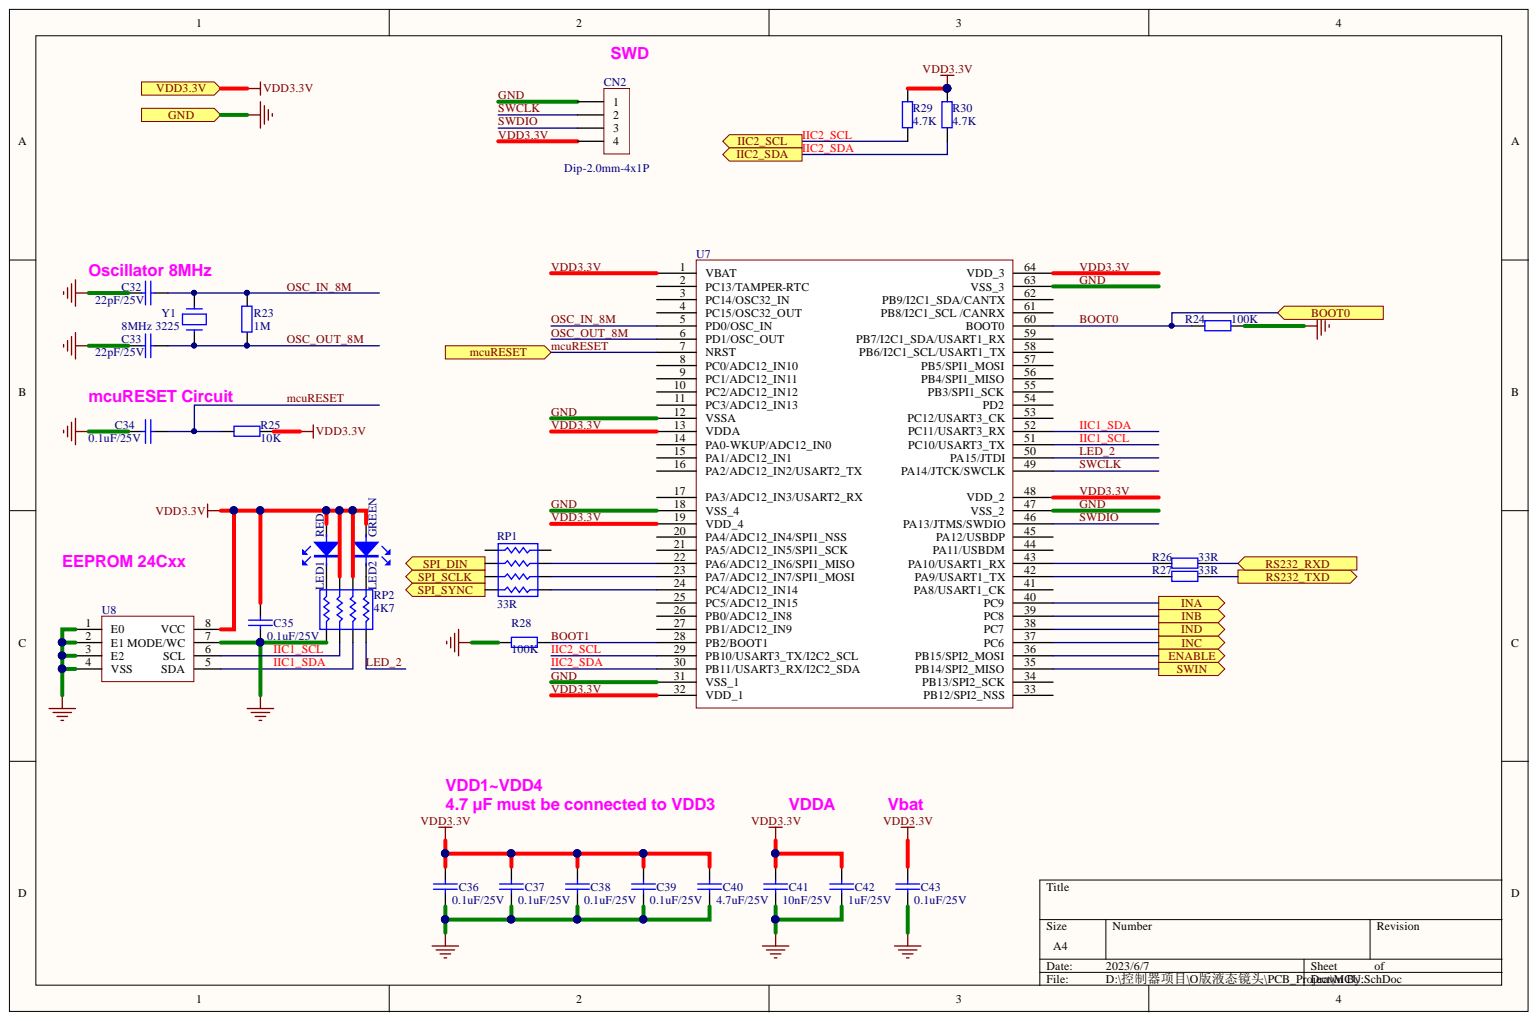
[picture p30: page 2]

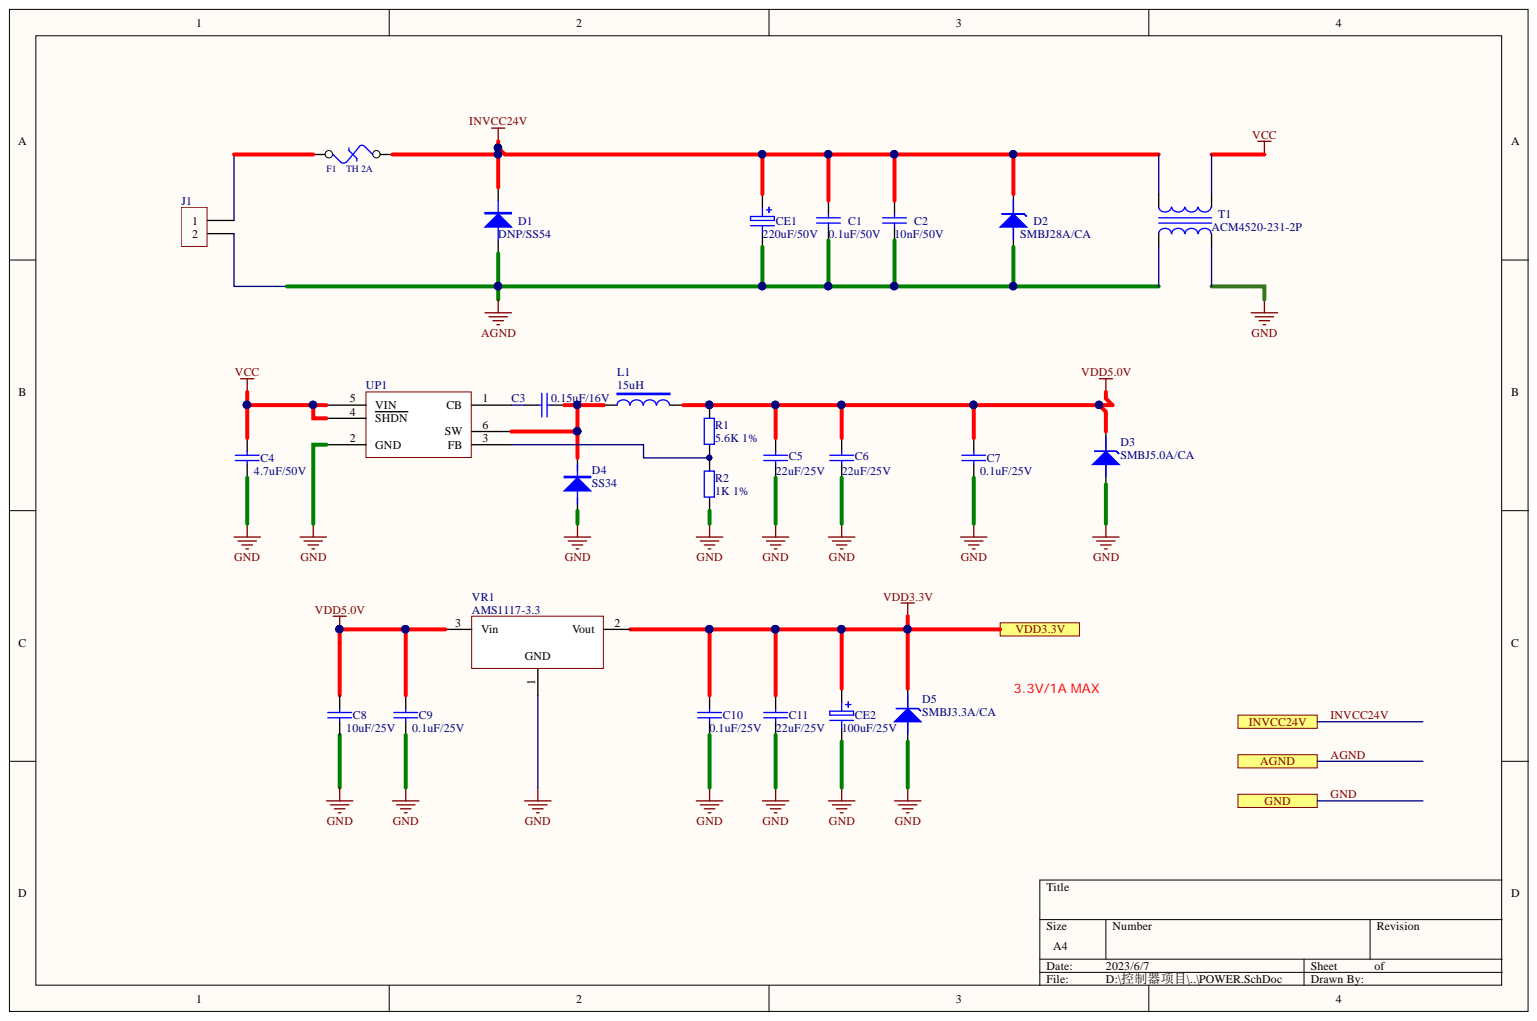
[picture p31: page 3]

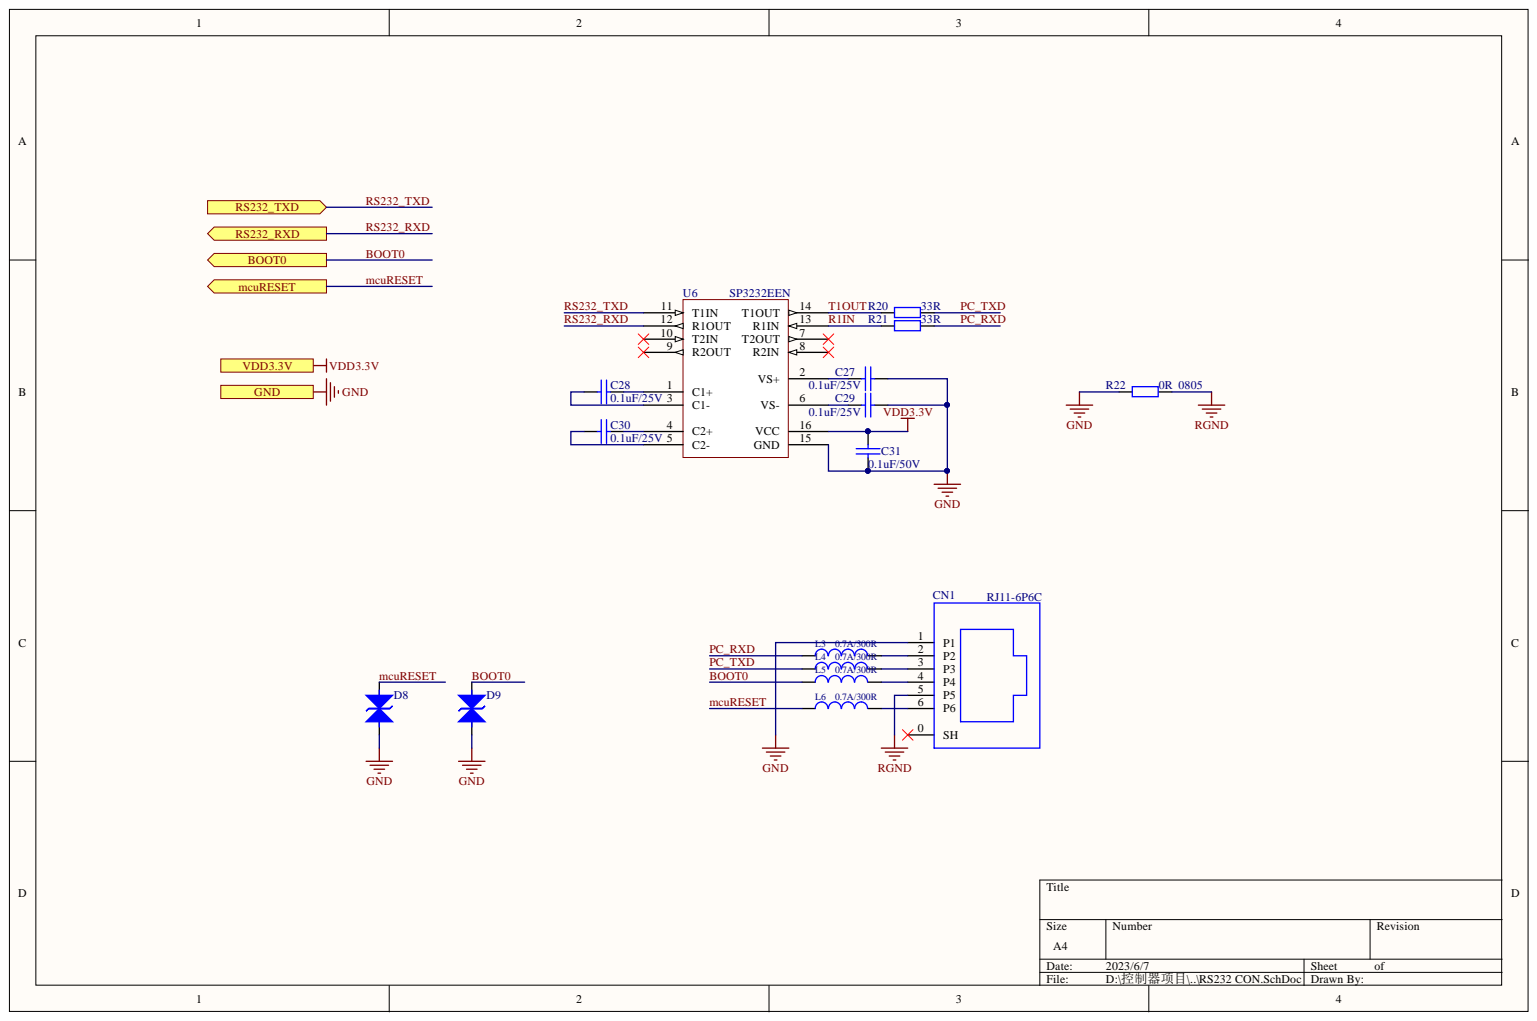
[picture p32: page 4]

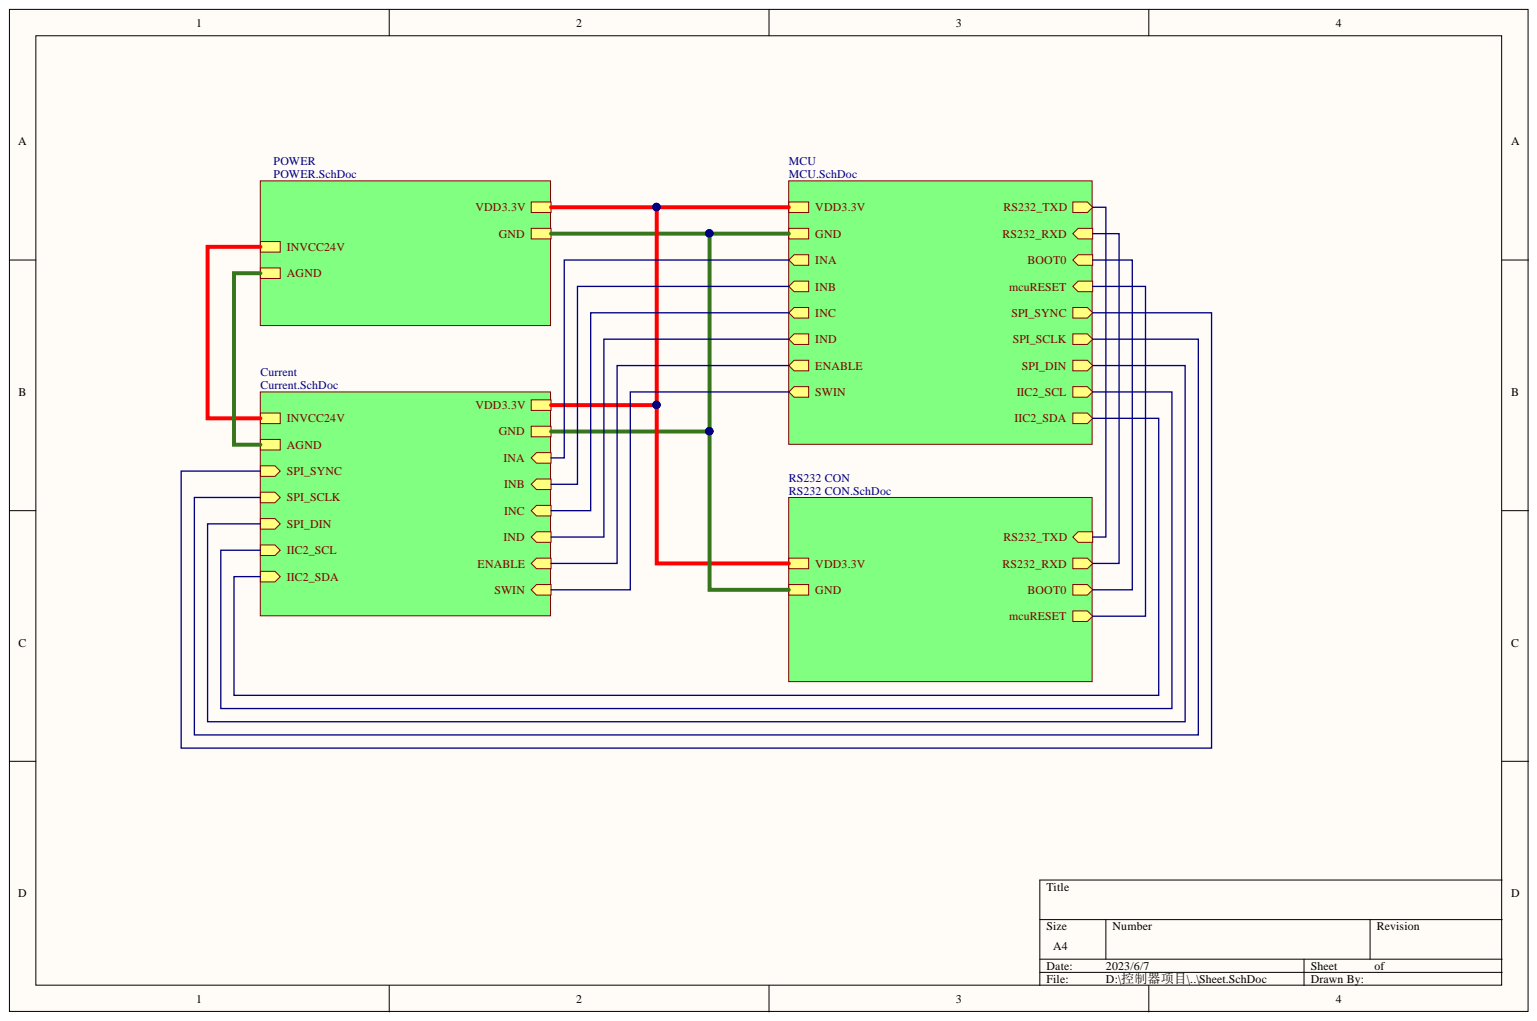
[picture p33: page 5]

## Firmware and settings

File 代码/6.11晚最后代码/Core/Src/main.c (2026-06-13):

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
/* Includes ------------------------------------------------------------------*/
#include "main.h"
#include "adc.h"
#include "dma.h"
#include "spi.h"
#include "tim.h"
#include "usart.h"
#include "gpio.h"

/* USER CODE BEGIN Includes */
#include "button.h"
#include "dsp_DAC.h"
#include "dsp_test_communication.h"
#include "key_service.h"
#include "PID.h"
#include "dsp_ADC.h"
#include "TJC_HMI.h"
#include "global_value.h"
/* USER CODE END Includes */

/* USER CODE BEGIN PD */
#define SEND_TIME 200  //发送间隔
/* USER CODE END PD */


void SystemClock_Config(void);
/**
  * @brief  The application entry point.
  * @retval int
  */
int main(void)
{

  /* MCU Configuration--------------------------------------------------------*/

  /* Reset of all peripherals, Initializes the Flash interface and the Systick. */
  HAL_Init();

  /* Configure the system clock */
  SystemClock_Config();

  /* Initialize all configured peripherals */
  MX_GPIO_Init();
  MX_DMA_Init();
  MX_ADC1_Init();
  MX_USART1_UART_Init();
  MX_USART2_UART_Init();
  MX_ADC2_Init();
  MX_SPI1_Init();
  MX_TIM4_Init();
  MX_TIM3_Init();
  /* USER CODE BEGIN 2 */
  KEY_Init();
  ADC_Init();
  TJC_HMI_Init(&huart2);

  PID_Init();

  DAC_Init(&hspi1);       //初始化DAC

  I_set = 0.22f;
  DAC1_cmd = 1.2f;

  HAL_TIM_Encoder_Start(&htim4,TIM_CHANNEL_ALL);      //旋转编码器
  HAL_Delay(20);

  uint32_t last_tick = HAL_GetTick();
  /* USER CODE END 2 */

  /* Infinite loop */
  /* USER CODE BEGIN WHILE */
  while (1)
  {
    TJC_HMI_Process();
    Button_Process();
    Encoder_Process();
    Filter_Output();
    if (ADC_FLAG==1) {
      BUCK_Loop();
      PID_Current_Loop();
      ADC_FLAG=0;
    }

    //PID_BUCK_Loop();
    if (HAL_GetTick() - last_tick >= SEND_TIME) {
      if (Safe_flag==TJC_PROTECT_NORMAL) {
        Global_OUTPUT(TJC_PROTECT_NORMAL);
      }else if(Safe_flag==TJC_PROTECT_OPEN_LOAD){

        if (I_set<0.001f) {
          
        }else {
          Global_OUTPUT(TJC_PROTECT_OPEN_LOAD);
          TJC_Beep(50);
          TJC_SetLoadVoltage_mV(0);
          TJC_SetLoadPower_mW(0);
          HAL_GPIO_WritePin(BUCK_EN_GPIO_Port, BUCK_EN_Pin, GPIO_PIN_RESET);
          HAL_GPIO_WritePin(LED_GPIO_Port, LED_Pin, GPIO_PIN_SET);
        }
      }else if(Safe_flag==TJC_PROTECT_OVERCURRENT) {
        HAL_GPIO_WritePin(BUCK_EN_GPIO_Port, BUCK_EN_Pin, GPIO_PIN_RESET);
        HAL_GPIO_WritePin(LED_GPIO_Port, LED_Pin, GPIO_PIN_SET);
        I_set = 0.0f;
        DAC2_cmd = 0.0f;
        Global_OUTPUT(TJC_PROTECT_OVERCURRENT);
      }
      last_tick = HAL_GetTick();
      if(I_disp<0.0001f && HAL_GPIO_ReadPin(BUCK_EN_GPIO_Port, BUCK_EN_Pin) == GPIO_PIN_SET){
        Safe_flag = TJC_PROTECT_OPEN_LOAD;
      }
    }
    /* USER CODE END WHILE */

    /* USER CODE BEGIN 3 */
  }
  /* USER CODE END 3 */
}

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
/* USER CODE BEGIN 4 */
void HAL_GPIO_EXTI_Callback(uint16_t GPIO_Pin) {
  Button_EXTI_Callback(GPIO_Pin);
}
/* USER CODE END 4 */
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


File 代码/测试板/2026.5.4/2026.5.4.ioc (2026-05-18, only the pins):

Mcu.UserName=STM32F103C8Tx
PA0-WKUP.GPIO_Label=V_OUT-
PA0-WKUP.Signal=ADCx_IN0
PA1.GPIO_Label=V_OUT+
PA1.Signal=ADCx_IN1
PA10.Signal=USART1_RX
PA13.Signal=SYS_JTMS-SWDIO
PA14.Signal=SYS_JTCK-SWCLK
PA2.Signal=USART2_TX
PA3.Signal=USART2_RX
PA4.GPIO_Label=DAC_CS
PA4.Signal=GPIO_Output
PA5.GPIO_Label=DAC_SCK
PA5.Signal=SPI1_SCK
PA7.GPIO_Label=DAC_MOSI
PA7.Signal=SPI1_MOSI
PA9.Signal=USART1_TX
PB0.Signal=ADCx_IN8
PB10.GPIO_Label=SW_IN
PB10.Signal=GPIO_Output
PB11.GPIO_Label=BUCK_EN
PB11.Signal=GPIO_Output
PB12.GPIO_Label=KEY_1
PB12.Signal=GPIO_Input
PB13.GPIO_Label=KEY_2
PB13.Signal=GPIO_Input
PB14.GPIO_Label=KEY_3
PB14.Signal=GPIO_Input
PB6.Signal=S_TIM4_CH1
PB7.Signal=S_TIM4_CH2
PB8.GPIO_Label=ENC_SW
PB8.Signal=GPIO_Input
PC13-TAMPER-RTC.GPIO_Label=LED
PC13-TAMPER-RTC.Signal=GPIO_Output
PD0-OSC_IN.Signal=RCC_OSC_IN
PD1-OSC_OUT.Signal=RCC_OSC_OUT

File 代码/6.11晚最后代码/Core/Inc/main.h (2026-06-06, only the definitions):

#define LED_Pin GPIO_PIN_13
#define LED_GPIO_Port GPIOC
#define V_OUT__Pin GPIO_PIN_0
#define V_OUT__GPIO_Port GPIOA
#define V_OUT_A1_Pin GPIO_PIN_1
#define V_OUT_A1_GPIO_Port GPIOA
#define DAC_CS_Pin GPIO_PIN_4
#define DAC_CS_GPIO_Port GPIOA
#define DAC_SCK_Pin GPIO_PIN_5
#define DAC_SCK_GPIO_Port GPIOA
#define DAC_MOSI_Pin GPIO_PIN_7
#define DAC_MOSI_GPIO_Port GPIOA
#define SW_IN_Pin GPIO_PIN_10
#define SW_IN_GPIO_Port GPIOB
#define BUCK_EN_Pin GPIO_PIN_11
#define BUCK_EN_GPIO_Port GPIOB
#define KEY_1_Pin GPIO_PIN_12
#define KEY_1_GPIO_Port GPIOB
#define KEY_1_EXTI_IRQn EXTI15_10_IRQn
#define KEY_2_Pin GPIO_PIN_13
#define KEY_2_GPIO_Port GPIOB
#define KEY_2_EXTI_IRQn EXTI15_10_IRQn
#define KEY_3_Pin GPIO_PIN_14
#define KEY_3_GPIO_Port GPIOB
#define KEY_3_EXTI_IRQn EXTI15_10_IRQn
#define ENC_SW_Pin GPIO_PIN_8
#define ENC_SW_GPIO_Port GPIOB
#define ENC_SW_EXTI_IRQn EXTI9_5_IRQn

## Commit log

2026-04-18 初步规划
2026-04-18 参考工程
2026-04-18 规划_new
2026-04-20 更新 README.md
2026-04-23 github使用方法
2026-04-23 github使用方法_2
2026-04-23 github使用方法_3
2026-04-23 github使用方法_4
2026-04-23 test复原
2026-04-25 参考工程_2
2026-04-27 加入测试记录
    加入测试记录文件夹，包含第一至三次的测试记录
2026-04-27 测试记录_markdown版本
2026-05-01 新增参考工程
    正负电流输出数控恒流源
2026-05-06 Update 方案说明.md
    1. 增加ADC跨板电容的说明
    2. 更新调试步骤
    3. 更新PCB布局
2026-05-08 数据手册
    [newBom_afterMatch.xlsx, 坐标文件.xlsx]
2026-05-09 更新单片机引脚分配
2026-05-11 中期报告_init
2026-05-13 测试板PCB_最终版
2026-05-13 代码开发框架_init
2026-05-15 去代码模版
2026-05-15 去代码模版_2
2026-05-16 数控恒流源测试_init + README_new
2026-05-18 代码部分DAC加ADC
2026-05-18 DAC加ADC
2026-05-18 删除.idea
2026-05-20 更新gitignore
2026-05-21 上传恒流源测试记录与规划
2026-05-21 初始化成型，按键SAFE中断
2026-05-28 DAC更改（MCP4822）
2026-06-01 DAC正常，由旋转编码器控制，ADC采样独立文件
2026-06-03 近期测试文件
    [测试数据01.xlsx, 测试数据02.xlsx]
2026-06-03 更新PID公式汇总
2026-06-03 串口屏驱动库_init
2026-06-04 添加静态映射曲线控件
2026-06-06 初步功能完成
2026-06-07 更新README.md
2026-06-07 chore: update 成品2 submodule reference
2026-06-07 chore: convert 成品2 into regular directory
2026-06-09 均值滤波
2026-06-10 成品2_6.9晚代码
2026-06-10 整理测试记录文件夹
    [测试数据01.xlsx, 测试数据02.xlsx]
2026-06-10 串口屏驱动:改为非阻塞式发送，增加动态窗口控件，添加异常响应
2026-06-10 报告初步框架
2026-06-11 补充中期报告
2026-06-11 update 测试数据03
    加入了最后的电流校准数据
    [测试数据02.xlsx, 测试数据03.xlsx]
2026-06-12 成品目录下，只留有基础功能，编码器默认调节电流，按键未启用，不含串口，保护逻辑完成
2026-06-12 3D外壳
    [3DShell_上壳_T.stl, 3DShell_下壳_B.stl]
2026-06-12 串口屏UI最终版
2026-06-12 初始化修改
2026-06-12 短路调整
2026-06-12 PID关断文件里面的在PID稳定一段时间会直接关闭，按下旋转编码器会重启PID
2026-06-13 补全“成品”的cmakelists
2026-06-13 上传6.11周四晚最后代码
2026-06-13 上传原理图pdf
2026-06-14 上传结项报告

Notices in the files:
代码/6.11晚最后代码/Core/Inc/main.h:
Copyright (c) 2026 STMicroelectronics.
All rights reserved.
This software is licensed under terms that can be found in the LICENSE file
